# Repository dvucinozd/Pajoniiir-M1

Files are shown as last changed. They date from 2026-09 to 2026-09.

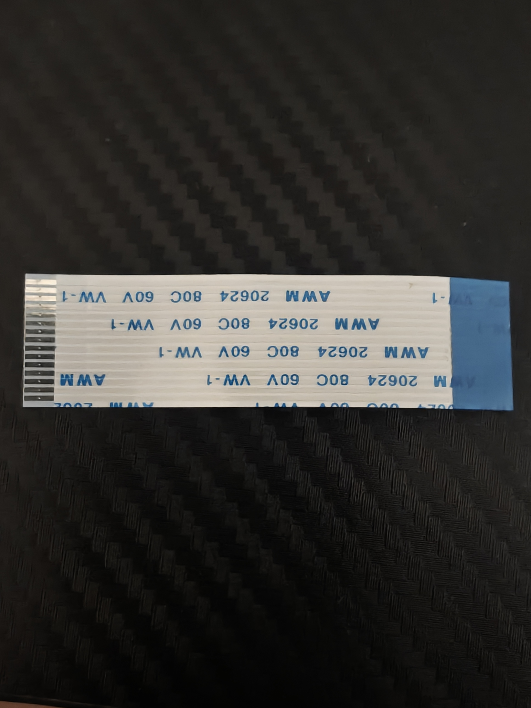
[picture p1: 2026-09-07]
hardware/Pajoniiir-M1/evidence/dsi506_ffc_flat.png

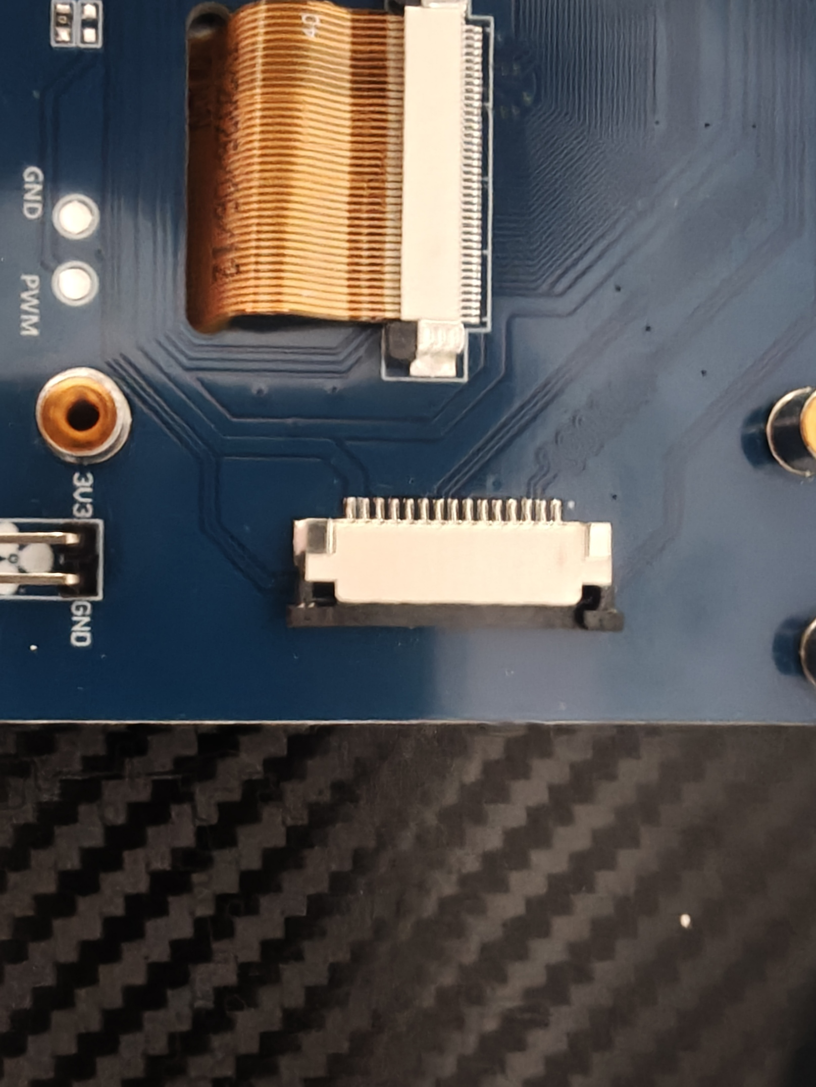
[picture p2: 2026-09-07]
hardware/Pajoniiir-M1/evidence/dsi506_actual_dsi_closeup.png

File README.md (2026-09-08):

# Pajoniiir-M1

Purpose-built Rev A mainboard for the **Pajoniiir standalone dual-deck DJ system**.

This repository contains the live hierarchical KiCad design, electrical and firmware contracts, mechanical evidence, placement/routing screening contracts, local CAD libraries and fail-closed validation tools.

## Current status

**Electrical milestone:** M1-ELEC-B2

**Mechanical milestone:** M1-MECH-B7

**Pre-layout milestone:** M1-PRELAYOUT-B10 - routed ESP32-P4 flash, crystal and external-DCDC feasibility proof

**Schematic structure:** PASS — 15/15 leaf sheets

**KiCad toolchain:** KiCad 10 only; local KiCad 10.0.4 ERC passes with zero violations and CI installs the KiCad 10 stable release

**Manufacturing BOM parity:** PASS — 244 source / 244 exported, 15 DNP, 3 intentional blank footprints

**Board-first mechanical contract:** PASS — display profiles cannot define the PCB outline or mounts

**Display-derived B2-B6 geometry:** historical screening only

**Final placement/routing freeze:** BLOCKED — 12 physical/EVT gates remain

**Gerber/EVT order:** NOT AUTHORIZED

Evidence updates: [ERC/library closure](docs/Pajoniiir_M1_ERC_Library_Closure_2026-09-04.md), [DSI506 rear image and corrected height](docs/Pajoniiir_M1_DSI506_Evidence_2026-09-04.md).

The current human-readable snapshot is [Pajoniiir M1 Current Design Status B10](docs/Pajoniiir_M1_Current_Design_Status_B10.md).

## Architecture

```text
                         5 V LOCKING INPUT
                                |
                         TPS259474 eFuse
                                |
                         5V_PROTECTED
                                |
                    5 mOhm Kelvin system shunt
                       / INA238 measurement
                                |
                             5V_SYS
              +-----------------+------------------+
              |                                    |
          TPS62132                         USB VBUS switches
          3V3_SYS                          TPS25221 x2
              |                               |       |
      +-------+---------+                  USB0 HS  USB1 FS
      |       |         |                  storage   FLX4
      v       v         v
  ESP32-P4 ESP32-C6  PCM5102A
      |      SDIO      MAIN L/R
      |
      +-- 15-pin MIPI DSI + I2C --> qualified display profile
      +-- SDMMC -----------------> microSD
```

The mainboard exposes a generic 15-pin Raspberry-Pi-style MIPI DSI host interface. EYOYO DSI506 / DYL0023 is the first validated display profile; other models may use the same board after electrical, power, firmware and cable qualification.

## Electrical baseline

- ESP32-P4NRW32X, target silicon v3.2 or newer approved revision
- 32 MB in-package PSRAM
- W25Q128JVPIQ 16 MB external QSPI flash
- ESP32-C6-WROOM-1-N4 over four-bit SDIO
- USB0 dedicated High-Speed storage host
- USB1 GPIO26/27 Full-Speed DDJ-FLX4 MIDI/UAC host
- independent TPS25221 VBUS switching, about 1.0 A USB0 and 1.6 A USB1 initial limits
- PCM5102APWR stereo MAIN output with deterministic XSMT boot mute
- native four-bit SDMMC microSD with TPS22918 power cycling
- P4 UART, P4 USB Serial/JTAG pogo and C6 recovery paths
- optional INA238 system power telemetry

## DSI host contract

```text
Host connector    Amphenol SFW15R-2STE1LF
Interface         15 contacts, 1.0 mm, Raspberry-Pi-style DSI map
Supply branch     3V3_DISPLAY_MODULE; final multi-model budget open
DSI routing       clock + lane0 + lane1
I2C               GPIO7 SDA / GPIO8 SCL
Cable             qualified per display model or adapter
Validated profile DSI506 / DYL0023: lane0, 800 Mbps, RGB888, 27.777 MHz
```

Connector shape alone does not prove compatibility. Every supported display needs a recorded pin map, power envelope, DSI timing/controller profile and cable orientation.

## Mechanical baseline

The mainboard is a standalone assembly and mounts to its own chassis or enclosure bosses. Its outline, mounting pattern and connector coordinates remain open until complete footprint packing, routing, thermal and service-envelope work establishes a viable board.

DSI506-derived values such as the 58 x 49 mm rear posts, 104 x 62 mm board screen and 128 x 84 x 30 mm enclosure screen are retained only for optional DSI506 bracket/enclosure work. They are not production `Edge.Cuts` authority.

## Connector and footprint state

| RefDes | Production part | Footprint | Mechanical state |
|---|---|---|---|
| J1 | Switchcraft 722RAHLP | open | terminal-center and panel geometry required |
| J2/J3 | Amphenol 87520-1010ALF | locked | panel/cable envelope open |
| J4/J5 | Kycon KLPX-0848A-2-W-G / -R-G | locked | panel/cable envelope open |
| J6 | Amphenol SFW15R-2STE1LF | locked | board-edge placement, power budget and per-display cable profile open |
| J7 | Molex 503398-1892 | locked | slot/access/clearance open |
| SW1/SW2 | B3U-3000P-B | locked | recessed tool-hole placement open |
| J9 | project-local factory pogo | closed, DNL | normal placement work only |

Only `J1`, `C3` and `C8` intentionally have blank footprints in the manufacturing source.

## PCB and routing state

`hardware/Pajoniiir-M1/Pajoniiir-M1.kicad_pcb` is a populated four-copper-layer pre-layout canvas. It contains all 244 assigned footprints and 193 named schematic nets in eight `Dwgs.User` working domains. B10 adds 78 track segments and 11 vias for the P4 external flash, crystal and external-DCDC proof. The P4 group has no footprint bounding-box overlaps; the board still has no zones or `Edge.Cuts`.

`m1_board_packing_inventory_b7.json` records all 247 schematic components, 244 assigned footprints, 33 footprint classes including the blank-gate class, and the seven board-first packing phases.

`m1_board_placement_seed_b8.json` records the generated domain coordinates and explicitly marks every coordinate as non-production. The seed and validator scripts preserve schematic UUID paths so KiCad can continue synchronizing the board with the hierarchy.

`m1_prelayout_b9_core_island.json` remains the reproducible unrouted source placement. `m1_prelayout_b10_core_routes.json` records the live critical routes and metrics. Its validator enforces the 5.203 mm U1/Y1 body gap, QSPI transition topology, 0.60/0.30 mm B10 vias, power-trunk widths, zero P4 bounding-box overlaps and zero route-geometry DRC violations.

The stackup is locked to JLCPCB `JLC04161H-7628`, 1.6 mm, 1 oz outer copper and 0.5 oz inner copper.

```text
F.Cu   components + critical USB/MIPI/QSPI/SDIO routing
In1.Cu continuous solid GND reference
In2.Cu power distribution + compatible low-speed routing
B.Cu   secondary components and low-speed routing
```

B5 locks routing topology and provides screening geometry:

- USB: 90 ohm differential; screening 0.2332 mm width / 0.15 mm gap
- MIPI: 100 ohm differential; screening 0.1722 mm width / 0.15 mm gap

These numbers are not production impedance locks. Exact JLCPCB calculator records, soldermask/model selection and matching KiCad rules are required before route freeze.

## Open layout blockers

The current 12 blocking gates are:

```text
C3_INPUT_BULK
C8_PROTECTED_BULK
J1_POWER_INPUT
SW1_RESET
SW2_BOOT
J2_USB0
J3_USB1
J4_RCA_L
J5_RCA_R
J_LCD_DISPLAY_FPC
J7_MICROSD
PCB_OUTLINE
```

Although most connector MPNs and footprints are locked, their gates stay open until absolute panel datums, cutouts, mating envelopes and local clearances are physically validated.

## Repository structure

```text
docs/                         engineering and status documents
hardware/Pajoniiir-M1/        KiCad project and machine contracts
  *.kicad_sch                 root plus 15 hierarchical sheets
  Pajoniiir-M1.kicad_pcb      populated four-layer B10 critical-route canvas
  *.json                      electrical/mechanical/freeze authorities
  libraries/                  project symbols and footprints
  tools/                      migration and fail-closed validators
.github/workflows/            KiCad and mechanical CI
```

## Authority order

When sources disagree:

1. live `hardware/Pajoniiir-M1/*.kicad_sch`
2. `board_first_mechanical_contract.json` and `mechanical_gates.json`
3. `pcb_constraints.json` and the current routing contract
4. B4 exact connector source lock
5. display compatibility profiles, beginning with `display_compatibility_dsi506.json`
6. [Engineering BOM v0.3](docs/Pajoniiir_Mainboard_BOM_v0.3.md)
7. [Global GPIO allocation](docs/Pajoniiir_Global_GPIO_Allocation_v0.1.md)
8. subsystem documents
9. superseded display-mounted B2-B6 and JC4880 records as historical evidence

## Current documents

### Status and release gates

- [Development handoff and remaining work](docs/Pajoniiir_M1_Development_Handoff_2026-09-08.md)
- [Current Design Status B10](docs/Pajoniiir_M1_Current_Design_Status_B10.md)
- [B10 P4 Critical Routes](docs/Pajoniiir_M1_PRELAYOUT_B10_P4_Critical_Routes_v0.1.md)
- [B9 P4 Core Island](docs/Pajoniiir_M1_PRELAYOUT_B9_P4_Core_Island_v0.1.md)
- [Schematic Audit](docs/Pajoniiir_M1_Schematic_Audit_v0.1.md)
- [Schematic Readiness Review](docs/Pajoniiir_RevA_Schematic_Readiness_Review_v0.1.md)
- [Manufacturing Output Contract](docs/Pajoniiir_Manufacturing_Output_Contract_v0.1.md)
- [Mechanical and Sourcing Gates](docs/Pajoniiir_M1_Mechanical_Sourcing_Gates_v0.1.md)
- [PCB Placement and Routing Constraints](docs/Pajoniiir_M1_PCB_Layout_Constraints_v0.1.md)

### Electrical contracts

- [Engineering BOM v0.3](docs/Pajoniiir_Mainboard_BOM_v0.3.md)
- [Global GPIO Allocation](docs/Pajoniiir_Global_GPIO_Allocation_v0.1.md)
- [Hardware/Firmware Contract](docs/Pajoniiir_M1_Hardware_Firmware_Contract_v0.1.md)
- [5-inch DSI Interface Migration](docs/Pajoniiir_M1_ELEC_B0_5in_DSI_Interface_Migration_v0.1.md)
- [15-pin DSI Connector Lock](docs/Pajoniiir_M1_ELEC_B1_DSI15_Connector_Lock_v0.1.md)
- [Board-first mechanical rebase](docs/Pajoniiir_M1_MECH_B7_Board_First_Rebase_v0.1.md)
- [DSI506 compatibility evidence](docs/Pajoniiir_M1_DSI506_Evidence_2026-09-04.md)

### Historical and subsystem design records

The original architecture, schematic plan, JC4880 display/backlight, GT911 and M1-MECH-A documents remain in `docs/` as design provenance. Their display-specific geometry does not override the B7 board-first authority.

## Validation

From the repository root:

```bash
python hardware/Pajoniiir-M1/tools/validate_schematic_structure.py
python hardware/Pajoniiir-M1/tools/validate_mechanical_authority.py
python hardware/Pajoniiir-M1/tools/report_mech_gate_snapshot.py
"C:/Program Files/KiCad/10.0/bin/python.exe" hardware/Pajoniiir-M1/tools/validate_core_routing_b10.py \
  --board hardware/Pajoniiir-M1/Pajoniiir-M1.kicad_pcb \
  --project hardware/Pajoniiir-M1/Pajoniiir-M1.kicad_pro \
  --report hardware/Pajoniiir-M1/m1_prelayout_b10_core_routes.json \
  --drc <fresh-kicad-drc.json>
```

Native KiCad 10 CI loads every schematic, exports and cross-checks the manufacturing BOM, exports the hierarchy netlist/PDF, enforces ERC cleanliness and validates the B10 PCB routing contract against a fresh DRC report.

Final placement, routing, Gerbers and EVT ordering remain blocked until every `blocks_layout_freeze` gate is closed and the production impedance geometry is recorded.

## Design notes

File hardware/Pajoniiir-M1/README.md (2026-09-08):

# Pajoniiir-M1 KiCad Rev A

Live KiCad 10 project for the Pajoniiir-M1 custom mainboard. KiCad 10 is the only supported ECAD toolchain for future edits and CI.

## Current design state

- Electrical milestone: M1-ELEC-B2
- Mechanical milestone: M1-MECH-B7
- Pre-layout milestone: M1-PRELAYOUT-B10 P4 critical-route proof
- Root schematic plus 15 leaf sheets: structurally clean
- Current manufacturing source: 244 `in_bom=yes`, 15 DNP, 3 intentional blank footprints
- PCB: 244 footprints, 193 named nets, 78 B10 track segments and 11 vias; no zones/`Edge.Cuts`
- Board packing inventory: 247 schematic components, 244 assigned footprints, 3 intentional blanks
- Final placement/routing freeze: blocked by 12 physical/EVT gates

J6 is a generic 15-pin Raspberry-Pi-style MIPI DSI host using Amphenol SFW15R-2STE1LF. DSI506 / DYL0023 is one validated display profile. `11_TOUCH_GT911.kicad_sch` stays empty because touch behavior belongs to the selected display profile.

## Authorities

1. `*.kicad_sch` — connectivity, RefDes, values and footprints
2. `board_first_mechanical_contract.json` — mainboard geometry boundary
3. `mechanical_gates.json` and `pcb_constraints.json` — freeze and layout gates
4. `m1_prelayout_b5_routing_contract.json` — routing topology and impedance state
5. `m1_board_packing_inventory_b7.json` — footprint population and packing sequence
6. `m1_board_placement_seed_b8.json` — populated-domain coordinates and non-production boundary
7. `m1_prelayout_b9_core_island.json` — reproducible unrouted P4 source placement
8. `m1_prelayout_b10_core_routes.json` — current critical-route placement and copper metrics
9. `m1_mech_b4_connector_source_lock.json` — exact external connector intent
10. `display_compatibility_dsi506.json` — first qualified display profile

The B2-B6 display-mounted placement and enclosure JSON files are retained as historical DSI506 screening only.

Human-readable current state: `../../docs/Pajoniiir_M1_Current_Design_Status_B10.md`.

Next-session development sequence: `../../docs/Pajoniiir_M1_Development_Handoff_2026-09-08.md`.

## Mechanical and routing boundary

The board mounts to its own chassis. Final `Edge.Cuts`, chassis holes, connector coordinates and height zones must come from board component packing, routing and service requirements. Display rear posts and display-derived board/enclosure screens are not production authority.

The selected stackup is JLCPCB JLC04161H-7628, four layers and 1.6 mm. Exact 90 ohm USB and 100 ohm MIPI width/gap values still require a recorded JLCPCB calculator result before routing freeze.

Do not add production `Edge.Cuts`, call screening anchors final placement, or release Gerbers while `layout_freeze_allowed` is false.

## Validation

Run from the repository root:

```bash
python hardware/Pajoniiir-M1/tools/validate_schematic_structure.py
python hardware/Pajoniiir-M1/tools/validate_mechanical_authority.py
python hardware/Pajoniiir-M1/tools/validate_board_packing_inventory.py
python hardware/Pajoniiir-M1/tools/report_mech_gate_snapshot.py
"C:/Program Files/KiCad/10.0/bin/python.exe" hardware/Pajoniiir-M1/tools/validate_core_routing_b10.py \
  --board hardware/Pajoniiir-M1/Pajoniiir-M1.kicad_pcb \
  --project hardware/Pajoniiir-M1/Pajoniiir-M1.kicad_pro \
  --report hardware/Pajoniiir-M1/m1_prelayout_b10_core_routes.json \
  --drc <fresh-kicad-drc.json>
```

Native KiCad ERC, hierarchy load, manufacturing BOM parity, netlist and PDF export are enforced in CI. B10 routing validation additionally uses KiCad's bundled `pcbnew` Python module and a fresh KiCad DRC JSON locally.

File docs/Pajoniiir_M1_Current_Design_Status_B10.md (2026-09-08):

# Pajoniiir-M1 current design status B10

**Date:** 2026-09-08

**Electrical milestone:** M1-ELEC-B2

**Mechanical milestone:** M1-MECH-B7

**Pre-layout milestone:** M1-PRELAYOUT-B10

**Layout state:** populated board-first canvas with routed P4 flash, crystal and external-DCDC feasibility proof; `layout_freeze_allowed=false`

**ECAD toolchain:** KiCad 10.x only for all future edits and CI

## Product boundary

Pajoniiir-M1 is the primary product assembly: a standalone ESP32-P4 mainboard. Its PCB outline, mounting holes, connector locations, height zones and enclosure datums must come from the board's own packing, routing, thermal, service and manufacturing requirements.

The screen is a replaceable external peripheral. DSI506 / DYL0023 remains one electrically and physically qualified compatibility profile; it does not define the mainboard outline or mounting pattern.

## Electrical and PCB state

The hierarchical KiCad design contains 15 leaf sheets. Current structural validation passes, all 244 assigned footprints are on the board, and the board retains 193 named schematic nets. The intentional blank-footprint set remains J1, C3 and C8.

The board retains:

- ESP32-P4 with ESP32-C6 over four-bit SDIO;
- independent USB host ports and switched VBUS branches;
- PCM5102A stereo MAIN output;
- native four-bit SDMMC microSD;
- power protection, current measurement and power-good diagnostics;
- generic 15-pin Raspberry-Pi-style MIPI DSI host interface.

B8 populated the eight reversible `Dwgs.User` electrical domains. B9 compacted the 63 P4 and flash-sheet footprints into a deterministic island. B10 rotates U1 and adds real copper for the external QSPI flash, 40 MHz crystal and external VDD_HP regulator.

The B10 live board contains 78 track segments and 11 vias. There are no footprint bounding-box overlaps in the P4 group, no zones and no `Edge.Cuts`. The crystal body is 5.203 mm from U1. The six QSPI paths have a 12.208 mm screening length spread and three package-opposed paths use one via pair each.

KiCad 10.0.4 reports zero route-specific geometry violations. U8 now uses a project-local KiCad 10 footprint with four 0.30 mm thermal-via drills, clearing the previous minimum-drill conflict. The unfinished whole board still has 499 unconnected items and nine non-routing findings: eight silkscreen findings and the intentionally absent outline.

`m1_prelayout_b10_core_routes.json` is the current machine-readable route authority. B9 remains the reproducible unrouted source placement.

## Display interface

J6 remains Amphenol `SFW15R-2STE1LF`, 15 contacts at 1.0 mm pitch, top contact, right-angle SMT ZIF. It routes DSI clock, lane 0, lane 1, shared display I2C and `3V3_DISPLAY_MODULE`.

Every supported display model still needs its own pin-map or adapter, power envelope, DSI timing/controller profile, touch behavior and cable orientation/service qualification. Type-B is a DSI506 cable fact, not a universal M1 requirement.

## Locked and open items

Locked today:

- electrical connectivity and current 15-sheet hierarchy;
- J6 part, footprint and 15-pin electrical map;
- JLCPCB `JLC04161H-7628` four-layer, 1.6 mm stackup;
- most external connector MPN and footprint intent;
- DSI506 compatibility profile;
- reproducible B9 source placement and B10 critical-route proof;
- U8 project-local VQFN thermal-via variant with 0.30 mm drills;
- 0.15 mm Default clearance for current fine-pitch escape validation;
- `layout_freeze_allowed=false` while blockers remain.

The 12 layout blockers remain:

```text
C3_INPUT_BULK
C8_PROTECTED_BULK
J1_POWER_INPUT
SW1_RESET
SW2_BOOT
J2_USB0
J3_USB1
J4_RCA_L
J5_RCA_R
J_LCD_DISPLAY_FPC
J7_MICROSD
PCB_OUTLINE
```

## Next board work

1. Place U4 at a candidate board edge, enforce its all-layer antenna keepout and prove the four-bit SDIO escape to U1.
2. Add the complete P4 power/GND plane and stitching strategy.
3. Compact the power spine and connector domains around the P4 and C6 islands, then derive the minimum board-owned envelope.
4. Add a chassis mounting pattern and validate cables, height zones, thermal clearance and user access.
5. Close J1/C3/C8 EVT and exact controlled-impedance geometry before final route freeze.

No Gerber or EVT order is authorized while the outline and blocking gates remain open.

## Validation

```powershell
python hardware/Pajoniiir-M1/tools/validate_schematic_structure.py
python hardware/Pajoniiir-M1/tools/validate_mechanical_authority.py
python hardware/Pajoniiir-M1/tools/validate_board_packing_inventory.py
python hardware/Pajoniiir-M1/tools/report_mech_gate_snapshot.py
kicad-cli pcb drc --format json --output <b10-drc.json> `
  hardware/Pajoniiir-M1/Pajoniiir-M1.kicad_pcb
& 'C:\Program Files\KiCad\10.0\bin\python.exe' `
  hardware/Pajoniiir-M1/tools/validate_core_routing_b10.py `
  --board hardware/Pajoniiir-M1/Pajoniiir-M1.kicad_pcb `
  --project hardware/Pajoniiir-M1/Pajoniiir-M1.kicad_pro `
  --report hardware/Pajoniiir-M1/m1_prelayout_b10_core_routes.json `
  --drc <b10-drc.json>
```

The B8 and B9 validators apply to their historical unrouted artifacts. The B10 validator is the live-board routing gate.

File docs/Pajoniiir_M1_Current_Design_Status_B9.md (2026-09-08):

# Pajoniiir-M1 current design status B9

> **HISTORICAL STATUS.** B10 added the routed P4 flash, crystal and external-DCDC feasibility proof. Use `Pajoniiir_M1_Current_Design_Status_B10.md` for the current state.

**Date:** 2026-09-07

**Electrical milestone:** M1-ELEC-B2

**Mechanical milestone:** M1-MECH-B7

**Pre-layout milestone:** M1-PRELAYOUT-B9

**Layout state:** populated board-first canvas with a compact P4 routing-feasibility island; `layout_freeze_allowed=false`

## Product boundary

Pajoniiir-M1 is the primary product assembly: a standalone ESP32-P4 mainboard. Its PCB outline, mounting holes, connector locations, height zones and enclosure datums must be derived from the board's own component packing, routing, thermal, service and manufacturing requirements.

The screen is a replaceable external peripheral. No display PCB, display mounting-post pattern or display enclosure may define the M1 board geometry.

The active machine authority is `hardware/Pajoniiir-M1/board_first_mechanical_contract.json`. `mech_a.json`, `mechanical_gates.json` and `pcb_constraints.json` are synchronized to that boundary.

## Electrical state

The hierarchical KiCad design contains 15 leaf sheets. Current structural validation passes with all 15 sheets and the intentional blank-footprint policy remains limited to J1, C3 and C8. Local KiCad 10 ERC previously passed with zero violations after power-good test points, no-connect markers and library closure were added.

The board retains these main functions:

- ESP32-P4 with ESP32-C6 over four-bit SDIO
- independent USB host ports and switched VBUS branches
- PCM5102A stereo MAIN output
- native four-bit SDMMC microSD
- power protection, current measurement and power-good diagnostics
- generic 15-pin Raspberry-Pi-style MIPI DSI host interface

## Display interface and compatibility

J6 is the board interface, using Amphenol `SFW15R-2STE1LF`, 15 contacts at 1.0 mm pitch, top contact, right-angle SMT ZIF. The locked electrical map routes DSI clock, lane 0, lane 1, shared display I2C and `3V3_DISPLAY_MODULE`.

EYOYO DSI506 / DYL0023 is one validated compatibility profile. Pajoniiir-M3 evidence confirms its electrical map and operating profile, and the supplied photos confirm its Type-B FFC construction. Those facts do not make DSI506 the final product display or the mechanical datum for M1.

Every additional display model must qualify:

- the same 15-pin electrical map, or an explicit adapter;
- startup, steady-state and transient current on `3V3_DISPLAY_MODULE`;
- DSI lanes, rate, pixel format and timing;
- touch/controller I2C behavior where used;
- cable contact orientation, insertion and service envelope.

Type-B is a DSI506 cable fact, not a universal M1 requirement. The board-side connector remains fixed; a cable or adapter profile resolves model-specific orientation.

## Mechanical rebase

The following values are retained only as DSI506-specific or historical screening evidence:

- 58 x 49 mm DSI506 rear-post pattern;
- 104 x 62 mm display-derived board screen;
- 128 x 84 x 30 mm display-derived enclosure screen;
- the 1.4455 mm DSI506 right-edge FFC clearance result;
- all JC4880 enclosure, mount and Z-stack geometry.

They are forbidden as production `Edge.Cuts`, mainboard mounting or connector-placement authority. The B2 through B6 display-specific records remain useful when designing a DSI506 bracket, cable kit or enclosure variant.

The board outline and its chassis mounting pattern remain open. `m1_board_packing_inventory_b7.json` closed the inventory step with 247 schematic components, 244 assigned footprints, 3 intentional blank footprints and 33 footprint classes including the blank-gate class.

M1-PRELAYOUT-B8 populated the live PCB with all 244 assigned footprints and 193 named schematic nets. Eight `Dwgs.User` rectangles separate the working electrical domains: power spine, USB edges, audio, P4 core, C6 RF, DSI host, storage and service.

M1-PRELAYOUT-B9 moves all 63 footprints from `03_P4_CORE` and `04_P4_FLASH_CLOCK_RESET` into a deterministic 52.602 x 50.033 mm routing-feasibility island. U1, U2, U3, L1 and Y1 now form the electrical anchors; the six QSPI tuning resistors sit between U1 and U2, the external DCDC loop sits beside U1, and the 40 MHz crystal body remains 7.285 mm from U1. The island has zero footprint bounding-box overlaps and the entire board still has no tracks, zones or `Edge.Cuts`.

`m1_prelayout_b9_core_island.json` records every B9 coordinate and metric. These coordinates and the eight domain rectangles remain a reversible working canvas. They are not connector, mounting or enclosure datums, and the next escape/routing pass may move parts within the P4 island.

## Locked and open items

Locked today:

- electrical connectivity and current 15-sheet hierarchy;
- J6 part, footprint and 15-pin electrical map;
- JLCPCB `JLC04161H-7628` four-layer, 1.6 mm stackup;
- most external connector MPN and footprint intent;
- DSI506 electrical/firmware compatibility profile;
- the reproducible B9 P4 core-island seed and its fail-closed validator;
- `layout_freeze_allowed=false` while blockers remain.

The 12 layout blockers remain:

```text
C3_INPUT_BULK
C8_PROTECTED_BULK
J1_POWER_INPUT
SW1_RESET
SW2_BOOT
J2_USB0
J3_USB1
J4_RCA_L
J5_RCA_R
J_LCD_DISPLAY_FPC
J7_MICROSD
PCB_OUTLINE
```

The meaning of the last two gates changed at B7. `J_LCD_DISPLAY_FPC` now asks for board-edge J6 placement, generic service access, branch power qualification and per-display cable profiles. `PCB_OUTLINE` now asks for a board-owned outline and chassis mount derived from completed packing and routing evidence.

## Next board work

1. Prove the U1 escape corridors and short QSPI, external-DCDC and crystal routes inside the B9 island while retaining a complete GND reference.
2. Place U4 at a candidate outer edge, preserve its all-layer antenna keepout and prove the four-bit SDIO escape to U1.
3. Compact the power spine and connector domains around those two critical islands, then derive a minimum feasible board envelope.
4. Add an independent chassis mounting-hole pattern and validate mated cables, height zones and thermal clearance.
5. Close J1/C3/C8 EVT and exact controlled-impedance geometry before final routing freeze.

No Gerber or EVT order is authorized while the outline and blocking gates remain open.

## Validation

```bash
python hardware/Pajoniiir-M1/tools/validate_schematic_structure.py
python hardware/Pajoniiir-M1/tools/validate_mechanical_authority.py
python hardware/Pajoniiir-M1/tools/validate_board_packing_inventory.py
python hardware/Pajoniiir-M1/tools/report_mech_gate_snapshot.py
"C:/Program Files/KiCad/10.0/bin/python.exe" hardware/Pajoniiir-M1/tools/validate_board_placement_b8.py \
  --board hardware/Pajoniiir-M1/Pajoniiir-M1.kicad_pcb \
  --netlist <fresh-kicad-xml-netlist> \
  --report hardware/Pajoniiir-M1/m1_board_placement_seed_b8.json
"C:/Program Files/KiCad/10.0/bin/python.exe" hardware/Pajoniiir-M1/tools/validate_core_placement_b9.py \
  --board hardware/Pajoniiir-M1/Pajoniiir-M1.kicad_pcb \
  --report hardware/Pajoniiir-M1/m1_prelayout_b9_core_island.json
```

The former B4 panel-window and B5 display-mounted placement validators are no longer CI gates because their coordinate systems were tied to DSI506. Their JSON outputs are explicitly marked historical screening only.

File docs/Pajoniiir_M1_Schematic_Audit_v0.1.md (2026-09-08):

# Pajoniiir-M1 — Schematic Audit v0.2

**Updated:** 2026-09-04

**Electrical milestone:** M1-ELEC-B2

**Mechanical context:** M1-MECH-B7

**Status:** local KiCad 10.0.4 ERC and export validation pass; KiCad 10 is the sole current CI/ECAD toolchain; final PCB placement/routing remains blocked

## Scope

This audit covers the root KiCad schematic and all 15 leaf sheets under `hardware/Pajoniiir-M1/`.

```text
01_POWER_INPUT
02_POWER_3V3
03_P4_CORE
04_P4_FLASH_CLOCK_RESET
05_C6_WIFI
06_USB_POWER
07_USB0_STORAGE
08_USB1_FLX4
09_AUDIO_PCM5102A
10_DISPLAY_MIPI
11_TOUCH_GT911
12_MICROSD
13_DEBUG_SERVICE
14_TEST_MONITORING
15_DNP_OPTIONS
```

`11_TOUCH_GT911` and `15_DNP_OPTIONS` intentionally contain no instantiated symbols after migration to the generic DSI host. Their presence preserves the hierarchy and historical sheet roles.

## Current verdict

| Check | Result |
|---|---|
| 15-sheet structural contract | PASS |
| Unique RefDes/unit contract | PASS |
| Root/child hierarchical pin name and shape equivalence | PASS |
| Critical 5 V/shunt topology | PASS |
| Generic 15-pin DSI host contract | PASS |
| Complete hierarchy load under KiCad 10.0.4 | PASS (16-sheet ERC/PDF export) |
| Local native KiCad 10.0.4 ERC | 0 unexplained errors, 0 excluded errors, 0 warnings |
| Manufacturing BOM parity | 244 source / 244 export, 15 DNP, 3 blank gates, PASS |
| Final PCB placement/routing freeze | BLOCKED |

The `.kicad_pro` file still contains six UUID-scoped exclusion records from the retired JC4880 connector gate. The current native KiCad 10 ERC report contains no violations, so those records are inactive configuration history rather than current violations.

See [PG diagnostics and library closure](Pajoniiir_M1_ERC_Library_Closure_2026-09-04.md) for TP25/TP26 connectivity, connector shield preservation, U14 land pattern and the remaining export-warning observation.

## Captured electrical architecture

### Power

```text
J1 -> D1 -> U7 TPS259474A -> 5V_PROTECTED
   -> R120 5 mOhm Kelvin shunt -> 5V_SYS
```

`5V_SYS` supplies the TPS62132 3.3 V system regulator and independent TPS25221 USB VBUS paths. INA238 measures across the system shunt. J1, C3 and C8 remain intentional blank-footprint production gates.

### ESP32-P4

U1 is ESP32-P4NRW32X with a reviewed project-local KiCad 10 symbol/footprint derived from current Espressif data. Both symbol units are instantiated. The P4 v3.x power model, physical pin 54 `VDD_HP_1`, TLV62569 core regulator, 499 k/499 k/22 pF feedback network, DSI_REXT, MIPI LDO and USB PHY supplies are captured.

### Flash, clock and recovery

W25Q128JVPIQ external flash, 40 MHz ECS crystal, boot/reset straps, P4 UART0, P4 USB Serial/JTAG pogo and C6 recovery paths are captured. SW1/SW2 use B3U-3000P-B footprints but remain open for enclosure tool-hole placement.

### ESP32-C6

ESP32-C6-WROOM-1-N4 is connected over four-bit SDIO with external pull-ups and series tuning. GPIO54 controls C6 reset/EN. RF antenna placement and final enclosure performance remain PCB/EVT work.

### USB

USB0 uses the dedicated P4 High-Speed PHY, TPD2EUSB30A and Amphenol 87520-1010ALF. USB1 uses GPIO26/27 Full-Speed, 22 ohm source series, TPD2EUSB30A and the same connector. Each port has an independent TPS25221 VBUS switch and EN/FAULT path.

J2/J3 MPNs and footprints are locked. Their gates remain open only for final panel/cutout/mated-cable geometry.

### MAIN audio

PCM5102APWR uses GPIO50 BCLK, GPIO51 DATA, GPIO52 LRCK and GPIO49 XSMT. The outputs use 470 ohm plus 2.2 nF filters into Kycon white/red RCA connectors. The former 3.5 mm line output was removed from Rev A.

### DSI host interface

The active design is a generic 15-pin Raspberry-Pi-style DSI host. J6 is Amphenol SFW15R-2STE1LF with a locked project footprint; DSI506/DYL0023 is one validated profile.

Captured interface:

```text
clock + DSI lane0 + DSI lane1
GPIO7 DISPLAY_I2C_SDA
GPIO8 DISPLAY_I2C_SCL
3V3_DISPLAY_MODULE on pins 14/15
```

The initial accepted firmware profile uses one lane at 800 Mbps, RGB888 and 27.777 MHz DPI. Touch is FT5426/FT5x06-compatible at 0x38 and panel power/backlight is controlled by the module device at 0x45.

There is no active MP3202 backlight boost, GT911 reset/interrupt network, LCD reset/TE or GPIO23 external PWM path. GPIO3/4/5/6/23 are released and unassigned.

The remaining J6 gate covers board-edge placement, power budget, generic service clearance and cable/adapter qualification per display model.

### microSD

The four-bit SDMMC bus, GPIO45-controlled TPS22918 supply and optional GPIO46 card detect are captured. J7 is Molex 503398-1892 with a locked footprint. Panel slot/access and local FFC/screw clearance remain open.

## Source and manufacturing inventory

Current source-derived counts:

```text
in_bom=yes      244
DNP              15
blank footprints  3: C3, C8, J1
DNL service       J8, J9, J10
```

Exact B4 footprints are present for J2/J3 USB, J4/J5 RCA, J7 microSD and SW1/SW2. J6 uses the B2 display connector footprint.

Historical 269/16/10 and run #76 270/17/12 figures predate the final display migration and B4 footprint locks. They are not current acceptance numbers.

## Structural validator coverage

`validate_schematic_structure.py` checks:

- balanced KiCad S-expressions and expected hierarchy
- bidirectional child-label/root-pin name and shape equivalence
- duplicate RefDes and duplicate RefDes/unit instances
- U1 two-unit geometry and pin partitioning
- prohibited ESP32-S3/ES8311/MAX485/NS4150 legacy blocks
- exact project eFuse and generic DSI host connector contracts
- `5V_PROTECTED -> R120 -> 5V_SYS` topology
- blank-footprint allowlist derived from `mechanical_gates.json`
- B7 board-first authority and fail-closed mechanical/PCB state
- PCB copper-layer count and absence of `Edge.Cuts` while the outline gate is open

Native KiCad ERC and downstream manufacturing export remain separate CI checks.

## Remaining release boundary

Electrical capture is complete. The 12 remaining blockers are physical/EVT/layout gates:

```text
C3_INPUT_BULK
C8_PROTECTED_BULK
J1_POWER_INPUT
SW1_RESET
SW2_BOOT
J2_USB0
J3_USB1
J4_RCA_L
J5_RCA_R
J_LCD_DISPLAY_FPC
J7_MICROSD
PCB_OUTLINE
```

Production placement/routing additionally requires exact 90 ohm USB and 100 ohm MIPI width/gap values for JLCPCB JLC04161H-7628.

## Go / no-go

- Schematic capture: **PASS / complete**
- Structural and manufacturing-source validation: **PASS**
- Exploratory placement using B5 screening anchors: **allowed**
- Final component placement: **blocked**
- Final USB/MIPI routing: **blocked**
- Gerbers and EVT PCB order: **blocked**

The next work should close J1 geometry, DSI FFC continuity/bend, display obstruction mapping, final enclosure/panel datums, mounting hardware, `Edge.Cuts`, C3/C8 EVT selection and production impedance rules.

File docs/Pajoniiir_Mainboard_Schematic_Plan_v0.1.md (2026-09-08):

# Pajoniiir Mainboard — Schematic Plan v0.1

**Projekt:** Pajoniiir BL-A1800 / Pajoniiir-M1  
**Ploča:** Pajoniiir Mainboard Rev A  
**Repo:** `dvucinozd/Pajoniiir-M1`  
**Datum:** 2026-09-02  
**Status:** Historical schematic architecture/capture plan. Implementation status is superseded by `Pajoniiir_M1_Schematic_Audit_v0.1.md` and the live KiCad project; pre-capture checkboxes below are not current milestone status.

---

# 1. Svrha dokumenta

Ovaj dokument bilježi kako su tadašnja hardverska arhitektura i Engineering BOM v0.2 prevedeni u plan za crtanje sheme. Aktivni projekt i Engineering BOM v0.3 sada su mjerodavni za stvarno stanje.

Cilj je da KiCad projekt od početka bude:

- hijerarhijski organiziran
- čitljiv
- lako reviewabilan
- pripremljen za ERC
- pripremljen za Rev A bring-up
- pripremljen za DNP varijante
- kompatibilan s postojećim Pajoniiir firmwareom
- pogodan za buduće PCB revizije bez velikog refaktora sheme

Podržani CAD alat: **KiCad 10 stable**.

Predloženi root projekt:

```text
hardware/
└── Pajoniiir-M1/
    ├── Pajoniiir-M1.kicad_pro
    ├── Pajoniiir-M1.kicad_sch
    ├── Pajoniiir-M1.kicad_pcb
    ├── sym-lib-table
    ├── fp-lib-table
    ├── symbols/
    ├── footprints/
    ├── 3d/
    └── docs/
```

---

# 2. Predložena hijerarhija sheme

Root sheet treba biti gotovo isključivo blok dijagram s hijerarhijskim sheetovima.

Predloženi sheetovi:

```text
00_ROOT
01_POWER_INPUT
02_POWER_3V3
03_P4_CORE
04_P4_FLASH_CLOCK_RESET
05_C6_WIFI
06_USB_POWER
07_USB0_STORAGE
08_USB1_FLX4
09_AUDIO_PCM5102A
10_DISPLAY_MIPI
11_TOUCH_GT911
12_MICROSD
13_DEBUG_SERVICE
14_TEST_MONITORING
15_DNP_OPTIONS
```

Preporuka: koristiti prefiks broja kako bi redoslijed sheetova ostao stabilan u KiCadu, PDF exportu i reviewu.

---

# 3. 00_ROOT — system interconnect

Root sheet mora prikazivati samo glavne funkcionalne blokove i globalne power railove.

## 3.1 Blokovi

```text
                        +-------------------+
                        |  01_POWER_INPUT   |
                        | VIN -> eFuse      |
                        +---------+---------+
                                  |
                                5V_SYS
                                  |
             +--------------------+--------------------+
             |                    |                    |
             v                    v                    v
      +-------------+      +-------------+      +-------------+
      | 02_POWER    |      | 06/07 USB   |      | 09 DISPLAY  |
      | 3V3 rails   |      | VBUS power  |      | backlight   |
      +------+------+      +------+------+      +------+------+
             |                    |                    |
           3V3_SYS               5V                LCD_BL
             |
      +------+-----------------------------------------------+
      |                                                      |
      v                                                      v
+-----------+                                        +---------------+
| 03 P4     |<---- QSPI ---- 04 FLASH/CLOCK         | 05 ESP32-C6   |
| CORE      |<---- SDIO ---------------------------->| ESP-HOSTED    |
+-----+-----+                                        +---------------+
      |
      +---- USB0 PHY ------> 06 USB0 STORAGE
      +---- USB1 PHY ------> 07 USB1 FLX4
      +---- I2S -----------> 08 PCM5102A
      +---- MIPI DSI ------> 09 DISPLAY
      +---- I2C -----------> 10 TOUCH
      +---- SDMMC ---------> 11 MICROSD
      +---- UART/GPIO -----> 12 DEBUG
      +---- MONITOR -------> 13 TEST/MONITORING
```

## 3.2 Root-level power nets

Koristiti konzistentne nazive:

- `VIN_5V`
- `5V_PROTECTED`
- `5V_SYS`
- `3V3_SYS`
- `3V3_C6`
- `3V3_AUDIO`
- `P4_VDD_HP`
- `LCD_BL_VOUT`
- `USB0_VBUS`
- `USB1_VBUS`
- `GND`

Ako se kasnije pokaže potreba, dodati:

- `3V3_SD`
- `3V3_LCD`
- `3V3_TOUCH`

ali u Rev A ne treba nepotrebno fragmentirati railove bez električkog razloga.

---

# 4. Naming convention

## 4.1 Digitalni signalni netovi

Koristiti funkcionalne nazive, ne samo GPIO broj.

Primjeri:

```text
P4_USB0_DP
P4_USB0_DM
P4_USB1_DP
P4_USB1_DM

P4_I2S_BCLK
P4_I2S_LRCK
P4_I2S_DOUT

P4_SDMMC_D0
P4_SDMMC_D1
P4_SDMMC_D2
P4_SDMMC_D3
P4_SDMMC_CLK
P4_SDMMC_CMD

P4_C6_SDIO_CLK
P4_C6_SDIO_CMD
P4_C6_SDIO_D0
P4_C6_SDIO_D1
P4_C6_SDIO_D2
P4_C6_SDIO_D3

P4_TOUCH_SDA
P4_TOUCH_SCL
P4_TOUCH_INT
P4_TOUCH_RST

P4_LCD_RST
P4_LCD_BL_PWM
```

GPIO broj staviti u pin label/comment, primjer:

```text
P4_I2S_BCLK   # GPIO50
```

To omogućuje kasniji firmware remap bez preimenovanja cijele sheme.

---

# 5. 01_POWER_INPUT

Ovaj sheet je električki najkritičniji uz USB.

## 5.1 Ulaz

Predloženi ulaz:

```text
J_PWR_IN
5 V regulated
4 A recommended source
```

Konektor: `TBD-MECH`.

Preporučuje se locking tip, ne obični labavi micro-USB/USB-C za osnovno napajanje Rev A.

## 5.2 Power chain

```text
J_PWR_IN
   |
   +-- C_IN_HF
   +-- C_IN_BULK
   |
   +-- TVS
   |
   +-- TPS25947 eFuse
   |
   +--> 5V_PROTECTED / 5V_SYS
```

## 5.3 TPS25947 signali

Izvesti:

- `EFUSE_EN`
- `EFUSE_PG`

Ako nema dovoljno GPIO-a u Rev A, `EFUSE_EN` može biti hardware-on. Za TPS259474A koristiti `EFUSE_PG`/`PGTH`; ova varijanta nema zaseban `FLT` izlaz. `EFUSE_PG` treba dovesti barem na P4 ili test point.

## 5.4 Test points

- TP VIN_5V
- TP 5V_SYS
- TP GND

## 5.5 ERC pravila

- power input označiti `PWR_FLAG`
- output eFusea označiti kao power output
- ne dopustiti drugi izvor na 5V_SYS
- USB VBUS se nikada ne smije direktno vezati natrag na VIN bez switcha

---

# 6. 02_POWER_3V3

U8 = TPS62132RGTR.

## 6.1 Funkcija

```text
5V_SYS
  |
TPS62132
  |
3V3_SYS
```

## 6.2 Consumers

`3V3_SYS` napaja:

- ESP32-P4 I/O/system railove prema referentnoj shemi
- external QSPI flash
- ESP32-C6-WROOM-1
- PCM5102A 3.3 V operation
- GT911 / touch subsystem ako kompatibilno
- microSD
- LCD logic gdje panel to zahtijeva

## 6.3 Layout-sensitive elementi

Na shemi ih grupirati fizičkim redoslijedom:

```text
VIN caps -> U8 -> SW -> L -> output caps -> feedback
```

Ne crtati feedback mrežu daleko od regulatora na shemi jer to otežava review layouta.

## 6.4 Test points

- `TP_3V3_SYS`
- opcionalno `TP_BUCK_SW` samo za laboratorij, jasno označen kao noisy node

---

# 7. 03_P4_CORE

Ovo je glavni sheet za ESP32-P4.

## 7.1 U1

`ESP32-P4NRW32X`

Prije capturea finalne sheme potvrditi:

- v3.x pinout
- VDD_HP_1 razliku u odnosu na staru v1.3 ploču
- sve power pinove
- exposed pad / GND requirements
- PSRAM in-package konfiguraciju

## 7.2 Funkcionalne grupe pinova

Na custom KiCad simbolu pinove grupirati po funkciji:

1. power
2. reset/strapping
3. USB HS
4. USB FS
5. MIPI DSI
6. flash interface
7. SDMMC
8. C6 SDIO
9. I2S audio
10. I2C touch
11. UART/debug
12. misc GPIO

## 7.3 GPIO assignment baseline

### Audio

- GPIO50 = I2S BCLK
- GPIO52 = I2S LRCK/WS
- GPIO51 = I2S DATA

### Touch

- GPIO3 = RST
- GPIO4 = INT
- GPIO7 = SDA
- GPIO8 = SCL

### microSD

- GPIO39 = D0
- GPIO40 = D1
- GPIO41 = D2
- GPIO42 = D3
- GPIO43 = CLK
- GPIO44 = CMD

### LCD

- GPIO5 = LCD RESET
- GPIO6 = optional TE
- GPIO23 = BACKLIGHT PWM

### C6 SDIO

- GPIO18 = CLK
- GPIO19 = CMD
- GPIO14 = D0
- GPIO15 = D1
- GPIO16 = D2
- GPIO17 = D3
- GPIO54 = C6 RESET

### USB power control

- GPIO20 = USB0 EN
- GPIO21 = USB0 FAULT_N
- GPIO22 = USB1 EN
- GPIO32 = USB1 FAULT_N

### microSD control

- GPIO45 = SD_PWR_EN
- GPIO46 = optional CARD_DETECT

### Audio mute

- GPIO49 = PCM5102A XSMT

### Monitoring

- GPIO53 = optional INA238 ALERT

## 7.4 Reserved GPIO table

U schematic notes dodati tablicu:

| GPIO | Rev A funkcija | Status |
|---|---|---|
| 5 | LCD_RST | locked |
| 7 | TOUCH_SDA | locked |
| 8 | TOUCH_SCL | locked |
| 14 | C6_SDIO_D0 | locked |
| 15 | C6_SDIO_D1 | locked |
| 16 | C6_SDIO_D2 | locked |
| 17 | C6_SDIO_D3 | locked |
| 18 | C6_SDIO_CLK | locked |
| 19 | C6_SDIO_CMD | locked |
| 23 | LCD_BL_PWM | locked |
| 39 | SD_D0 | locked |
| 40 | SD_D1 | locked |
| 41 | SD_D2 | locked |
| 42 | SD_D3 | locked |
| 43 | SD_CLK | locked |
| 44 | SD_CMD | locked |
| 50 | I2S_BCLK | locked |
| 51 | I2S_DATA | locked |
| 52 | I2S_LRCK | locked |
| 54 | C6_RESET | tentative-v3.x check |

Posebno provjeriti GPIO54/v3.x mapiranje prije schematic locka.

---

# 8. P4 VDD_HP core regulator

Može biti na `03_P4_CORE` ili kao pod-sheet.

Preporuka: ostaviti ga unutar P4 sheeta jer je električki dio SoC-a.

## 8.1 U3

TLV62569DRLR

## 8.2 Netovi

- input = `3V3_SYS`
- output = `P4_VDD_HP`
- feedback = lokalni netovi
- GND = solid GND

## 8.3 V3.x rule

Schematic comment:

> DO NOT COPY JC4880 P4 REV1.3 CORE DCDC VALUES. USE CURRENT ESPRESSIF V3.X REFERENCE NETWORK.

## 8.4 Test point

`TP_P4_VDD_HP`

---

# 9. 04_P4_FLASH_CLOCK_RESET

Namjerno odvojeno od glavnog P4 simbola zbog preglednosti.

## 9.1 QSPI flash

U2 = W25Q128JVPIQ candidate.

Netovi:

- `FLASH_CS`
- `FLASH_CLK`
- `FLASH_D0`
- `FLASH_D1`
- `FLASH_D2`
- `FLASH_D3`

Serijski 0 Ω footprints uz P4 ili flash, prema layout izboru.

## 9.2 40 MHz crystal

- Y1 = 40 MHz ±10 ppm
- Cload TBD nakon odabira MPN-a
- kratki netovi `XTAL_P`, `XTAL_N`

## 9.3 Reset

- 10 kΩ pull-up
- 1 µF prema GND
- RESET switch
- test point

## 9.4 BOOT

- strap prema aktualnom P4 reference designu
- BOOT switch
- test point

---

# 10. 05_C6_WIFI

U4 = ESP32-C6-WROOM-1-N4 candidate.

## 10.1 Interfaces

### P4 ↔ C6 SDIO

- CLK
- CMD
- D0-D3

### Control

- C6_RESET
- optional HOST_WAKE
- optional SLAVE_WAKE ako ESP-Hosted topologija bude zahtijevala

### Debug

- C6 UART TX
- C6 UART RX
- C6 EN

## 10.2 Antenna

Na shemi staviti velik note:

> MODULE ANTENNA KEEP-OUT REQUIRED ON PCB. NO COPPER, TRACES OR METAL UNDER ANTENNA REGION.

## 10.3 Power

Poželjno odvojiti net label:

`3V3_C6`

U početku može biti spojen preko 0 Ω / ferrite bead na `3V3_SYS`.

To daje mogućnost kasnije dodati EMI filtriranje bez PCB respina.

Predloženo:

```text
3V3_SYS -- FB_C6 / 0R --> 3V3_C6
```

---

# 11. 06_USB0_STORAGE

USB0 = High-Speed root za Rekordbox storage.

## 11.1 Data path

```text
ESP32-P4 HS USB PHY
      |
   D+ / D-
      |
 optional 0R tuning
      |
 low-C ESD
      |
 USB-A receptacle
```

## 11.2 Power path

```text
5V_SYS
  |
TPS25221 x2 CH1
  |
USB0_VBUS
  |
USB-A VBUS
```

## 11.3 Signals to P4

- `USB0_PWR_EN`
- `USB0_FAULT_N`

## 11.4 Connector shield

Ne vezati mehanički shield naslijepo direktno u signal GND bez razmišljanja.

Za Rev A predvidjeti opciju:

- direct GND via 0 Ω
- RC/chassis coupling footprint

ovisno o EMC strategiji.

## 11.5 Test

- VBUS TP
- D+ TP
- D- TP
- fault TP

---

# 12. 07_USB1_FLX4

USB1 = DDJ-FLX4.

Funkcije:

- MIDI IN
- MIDI OUT
- LED feedback
- USB Audio Class
- CUE/PFL channels 3/4

## 12.1 Data path

```text
ESP32-P4 FS USB
 |
22R / 22R initial
 |
ESD
 |
USB-A receptacle
 |
USB-A -> USB-C cable
 |
DDJ-FLX4
```

## 12.2 Power

TPS25221 x2 channel 2.

Netovi:

- `USB1_PWR_EN`
- `USB1_FAULT_N`
- `USB1_VBUS`

## 12.3 Critical validation

USB1 power path mora podnijeti:

- FLX4 enumeration
- LED activity
- MIDI
- 4ch UAC
- reconnect
- startup transient

bez brownouta P4.

---

# 13. TPS25221 x2 shared implementation

Iako se USB sheetovi prikazuju odvojeno, U6 može fizički biti na jednom sheetu.

Preporuka:

- U6 staviti na `06_USB0_STORAGE`
- CH1 = USB0
- CH2 = USB1
- na `07_USB1_FLX4` dovesti hijerarhijske netove

Alternativa: napraviti zaseban `06_USB_POWER` sheet.

Ako KiCad projekt krene rasti, bolja finalna hijerarhija je:

```text
06_USB_POWER
07_USB0_STORAGE
08_USB1_FLX4
```

i ostale sheetove pomaknuti za +1.

Za Rev A preporučujem upravo ovu varijantu jer jasno odvaja power od signal integrity dijela.

---

# 14. 08_AUDIO_PCM5102A

U5 = PCM5102APWR.

## 14.1 I²S input

- `P4_I2S_BCLK`
- `P4_I2S_LRCK`
- `P4_I2S_DOUT`

MCLK = NC / not used.

## 14.2 DAC control

Izvesti:

- `DAC_XSMT`

FMT i FLT mogu biti strapirani, ali ostaviti 0 Ω / resistor selection mogućnost.

## 14.3 Power

Preporučeni pristup:

```text
3V3_SYS
 |
ferrite bead / 0R
 |
3V3_AUDIO
 |
PCM5102A
```

Time se analogni DAC ne napaja direktno s najbučnijeg digitalnog raila bez mogućnosti filtriranja.

## 14.4 Analog outputs

```text
PCM5102A OUTL
  |
470R
  +---- RCA_L
  |
2.2nF
  |
GND

PCM5102A OUTR
  |
470R
  +---- RCA_R
  |
2.2nF
  |
GND
```

Točan položaj RC mreže u odnosu na konektor treba uskladiti s TI Figure 33 referentnom topologijom.

## 14.5 3.5 mm out — removed from Rev A

M1-MECH-A8 removes J6 from the Rev A board. No DNP footprint or panel aperture is reserved. MAIN remains RCA L/R; a future 3.5 mm option requires a new board/product revision.

---

# 15. 09_DISPLAY_MIPI

## 15.1 MIPI differential pairs

Netovi:

- `DSI_CLK_P`
- `DSI_CLK_N`
- `DSI_D0_P`
- `DSI_D0_N`
- `DSI_D1_P`
- `DSI_D1_N`

## 15.2 Control

- LCD_RST
- LCD_BL_PWM

## 15.3 Required analog/PHY support

- MIPI PHY decoupling
- DSI_REXT = 4.02 kΩ
- 0 Ω tuning footprints na svim DSI pair signalima samo ako ih layout i reference design opravdavaju

## 15.4 FPC

J_LCD ostaje TBD dok se ne zaključa točan panel.

Na shemi obavezno dokumentirati:

- FPC pitch
- contact side
- pin 1 orientation
- LED+ / LED-
- logic voltage
- touch signals ako dijele FPC

Bez ovoga PCB ne smije u layout freeze.

---

# 16. LCD backlight

U_BL = MP3202DJ-LF-Z candidate.

## 16.1 Input

5V_SYS.

## 16.2 Control

`LCD_BL_PWM` s GPIO23.

Ako MP3202 EN/PWM zahtijeva specifičnu logiku ili level, uključiti buffer samo ako datasheet/measurement pokaže potrebu.

## 16.3 Output

`LCD_BL_VOUT` prema LED stringu.

## 16.4 Lock condition

Ne zaključavati:

- inductor
- diode
- sense resistor
- OVP network

dok nije poznat finalni LCD LED string.

---

# 17. 10_TOUCH_GT911

## 17.1 Interface

- SDA = GPIO7
- SCL = GPIO8
- INT = odabrati slobodan P4 GPIO
- RESET = odabrati slobodan P4 GPIO

INT/RST pinovi trebaju biti firmware-configurable.

## 17.2 Pull-ups

Početno 4.7 kΩ, ali finalna vrijednost ovisi o:

- FPC dužini
- I2C frekvenciji
- bus capacitance

## 17.3 Address selection

GT911 reset/INT sequencing može utjecati na adresu.

Na shemi i firmwareu treba eksplicitno dokumentirati željenu 0x5D konfiguraciju.

---

# 18. 11_MICROSD

## 18.1 SDMMC 4-bit

- D0 GPIO39
- D1 GPIO40
- D2 GPIO41
- D3 GPIO42
- CLK GPIO43
- CMD GPIO44

## 18.2 Pull-ups

Predvidjeti pull-up na:

- CMD
- D0
- D1
- D2
- D3

Početna vrijednost 10 kΩ, finalno prema Espressif SDMMC preporuci.

## 18.3 CLK tuning

R_SD_CLK = 22 Ω initial.

Ostaviti 0402/0603 footprint blizu P4.

## 18.4 Optional power cycle

`SD_PWR_EN` kroz load switch ili P-MOSFET može biti DNP u Rev A, ali footprint je koristan.

---

# 19. 12_DEBUG_SERVICE

Rev A treba biti servisabilan bez lemljenja žica na fine pitch pinove.

## 19.1 P4 UART

- TX
- RX
- GND
- 3V3
- CHIP_PU
- BOOT

## 19.2 C6 debug

- TX
- RX
- EN
- RESET
- GND

## 19.3 USB Serial/JTAG

Ako P4 dedicated USB Serial/JTAG pinovi nisu zauzeti active topologyjem, predvidjeti test pads ili optional connector.

Ne uvoditi novi vanjski USB connector samo radi JTAG-a ako otežava finalnu mehaniku.

## 19.4 Connector

Preferred:

- Tag-Connect footprint
- pogo pads

Ne preferirati stalni 2.54 mm header na finalnom proizvodu.

---

# 20. 13_TEST_MONITORING

Ovaj sheet sadrži samo EVT/DVT opcije.

## 20.1 Current monitor

INA226/INA238 class.

Mjeri:

- 5V_SYS
- total system current

DNP default.

## 20.2 Optional divider rails

Može se omogućiti P4 ADC mjerenje:

- 5V_SYS divider
- USB0_VBUS divider
- USB1_VBUS divider

Ako ima dovoljno ADC resursa.

To daje firmware telemetry bez skupljeg current monitor IC-a.

## 20.3 Testpoint matrix

Na sheetu definirati sve TP oznake i funkcije.

---

# 21. 14_DNP_OPTIONS

Ovaj sheet sadrži stvari koje ne želimo u Rev A populaciji, ali mogu biti korisne za eksperiment.

Primjeri:

- 3.5 mm line out removed from Rev A (M1-MECH-A8)
- optional SD load switch
- optional current monitor
- optional reset supervisor
- optional EMI ferrite beads
- optional shield RC network
- optional status RGB LED

Ne stavljati ovdje obsolete funkcije poput S3, ES8311, camera ili RS485.

Njih uopće ne treba nositi u novu shemu.

---

# 22. Net classes za budući PCB

Iako je ovo schematic plan, net classes treba planirati prije layouta.

Predložene klase:

## USB_HS

- 90 Ω differential
- D+/D-
- tight pair
- low via count

## USB_FS

- differential pair
- manje strogo od HS, ali i dalje kontrolirano

## MIPI_DSI

- differential pair
- impedance prema Espressif/board stackup recommendation
- strict length matching unutar para
- međupair matching prema DPHY budgetu

## QSPI_FLASH

- kratko
- low stub
- matching po potrebi

## SDIO_C6

- kratko
- CLK kontroliran
- data/cmd matching prema SDIO timing budgetu

## SDMMC

- CLK kritičan
- D0-D3/CMD grupirani

## I2S

- BCLK/LRCK/DATA
- držati dalje od analog outputa

## ANALOG_AUDIO

- OUTL/OUTR
- no switching cross
- minimal loop area

## POWER_5V_HIGH

- 5V_SYS
- USB0_VBUS
- USB1_VBUS
- dimenzionirati za current + transient margin

---

# 23. ERC rules

## 23.1 Power flags

Dodati samo gdje je stvarno potrebno.

Ne “gasiti” ERC upozorenja naslijepo.

## 23.2 No-connect pins

Svaki NC pin eksplicitno označiti NC.

## 23.3 DNP

DNP elementi trebaju imati:

- `DNP` property
- BOM exclude flag gdje je potrebno
- jasno objašnjenje čemu služe

## 23.4 Active-low naming

Koristiti suffix:

`_N`

Primjeri:

- USB0_FAULT_N
- USB1_FAULT_N
- C6_RESET_N samo ako signal stvarno jest active-low

---

# 24. KiCad symbol strategy

## 24.1 Koristiti official symbols gdje postoje

Za generičke R/C/L i standardne IC-e.

## 24.2 Custom verified symbols

Obavezno ručno verificirati:

- ESP32-P4NRW32X
- ESP32-C6-WROOM-1-N4
- exact LCD connector
- exact USB connectors
- exact RCA
- exact microSD socket

Pin 1 i exposed pad greške su kritične.

## 24.3 Symbol review checklist

Za svaki custom IC:

- pin count
- pin number
- pin name
- electrical type
- power pins
- NC
- exposed pad
- footprint mapping

Ne koristiti community symbol bez usporedbe s originalnim datasheetom.

---

# 25. Footprint strategy

Prije povezivanja footprinta treba imati “footprint lock” listu.

## Must verify

- U1 ESP32-P4 package revision
- U2 WSON flash
- U3 TLV62569 DRL
- U4 ESP32-C6-WROOM
- U5 PCM5102A TSSOP
- U6 TPS25221 x2 DRC
- U7 TPS25947 RPW
- U8 TPS62132 RGT
- U9 MP3202 DJ
- LCD FPC
- USB-A ×2
- RCA ×2
- SD socket
- DC input

Za svaki footprint spremiti link na manufacturer mechanical drawing u property `Datasheet`.

---

# 26. Schematic design review gates

## Gate A — architecture

Prije crtanja:

- [x] P4-only arhitektura
- [x] PCM5102A MAIN
- [x] FLX4 CUE/UAC
- [x] dual USB
- [x] C6 SDIO
- [x] MIPI display
- [x] microSD

## Gate B — component lock

Prije finalnog capturea:

- [ ] P4 exact orderable v3.x MPN
- [ ] exact crystal
- [ ] exact LCD
- [ ] exact connectors
- [ ] final USB ILIM
- [ ] final backlight values

## Gate C — ERC

- [ ] zero unexplained ERC errors
- [ ] zero floating power pins
- [ ] every NC intentional
- [ ] every DNP intentional

## Gate D — pre-layout

- [ ] net classes assigned
- [ ] differential pairs named correctly
- [ ] connector pin 1 verified
- [ ] all test points included
- [ ] all debug nets included

---

# 27. Schematic bring-up sequence

Rev A board ne treba paliti “sve odjednom”.

## Phase 1 — naked power

Bez P4 firmware aktivnosti potvrditi:

- VIN
- eFuse output
- 3V3
- P4 core rail
- no abnormal current
- no hot component

## Phase 2 — P4 boot

Provjeriti:

- 40 MHz clock
- reset
- boot strap
- QSPI flash
- UART log

## Phase 3 — display/touch

- DSI output
- backlight
- touch I2C

## Phase 4 — microSD

- init
- read/write
- hot/reinsert behavior

## Phase 5 — PCM5102A

- BCLK
- LRCK
- DATA
- analog L/R
- noise floor

## Phase 6 — C6 Wi-Fi

- SDIO enumeration
- ESP-Hosted
- Wi-Fi
- web UI

## Phase 7 — USB0

- VBUS enable
- storage enumerate
- MP3 playback

## Phase 8 — USB1

- FLX4 enumerate
- MIDI
- LED
- UAC

## Phase 9 — combined load

- full backlight
- Wi-Fi
- USB0
- USB1
- dual-deck audio
- multi-hour soak

---

# 28. Brownout-specific design review

S obzirom na prototip, svaki schematic review mora posebno provjeriti:

1. Je li 5V_SYS topologija dovoljno niskoimpedantna?
2. Ima li USB0 vlastiti lokalni bulk C?
3. Ima li USB1 vlastiti lokalni bulk C?
4. Je li TPS25221 x2 input dovoljno dobro bypassan?
5. Je li 3V3 buck odvojen od USB VBUS load transienta?
6. Je li P4 core regulator lokalno pravilno decouplan?
7. Ima li input eFuse soft-start koji ne uzrokuje spor/pogrešan startup?
8. Postoji li dovoljno velik ulazni bulk reservoir?
9. Je li ground return USB powera odvojen fizički od osjetljivog audio dijela?
10. Mogu li se svi railovi mjeriti test pointovima?

---

# 29. Audio-specific design review

1. PCM5102A mora biti blizu RCA konektora.
2. I2S ne voditi uz analog output.
3. Backlight SW node daleko od audio područja.
4. P4 core DCDC daleko od RCA input/output trase.
5. RCA ground return direktno i široko prema GND planeu.
6. 3V3_AUDIO filter/0R option obavezno.
7. XSMT mora imati determinističko stanje na bootu.
8. Ne smije biti pop/glitch zbog floating control pina.

---

# 30. USB-specific design review

1. USB0 HS pair bez stuba.
2. USB0 ESD tik uz connector.
3. USB1 series R bliže source strani.
4. VBUS trace dimenzioniran na najmanje 1 A + margin.
5. TPS25221 x2 thermal pad layout po datasheetu.
6. FAULT pinovi imaju pull-up.
7. EN pinovi imaju definiran boot state.
8. shield strategy dokumentirana.
9. nema backfeed patha.
10. svaki port može se fizički power-cycleati.

---

# 31. MIPI-specific design review

1. DSI pair pinout potvrđen s LCD FPC datasheetom.
2. Pair polarity potvrđen.
3. lane0/lane1 mapping potvrđen.
4. DSI_REXT vrijednost i pin potvrđeni.
5. MIPI DPHY decoupling neposredno uz P4.
6. pair impedance definiran prema stackupu.
7. bez layer transitiona gdje nije nužno.
8. bez split planea ispod MIPI parova.
9. backlight power udaljen od DSI parova.

---

# 32. Recommended first KiCad files

Prvi konkretni commit nakon ovog plana trebao bi sadržavati:

```text
hardware/Pajoniiir-M1/
├── Pajoniiir-M1.kicad_pro
├── Pajoniiir-M1.kicad_sch
├── sheets/
│   ├── 01_POWER_INPUT.kicad_sch
│   ├── 02_POWER_3V3.kicad_sch
│   ├── 03_P4_CORE.kicad_sch
│   ├── 04_P4_FLASH_CLOCK_RESET.kicad_sch
│   ├── 05_C6_WIFI.kicad_sch
│   ├── 06_USB_POWER.kicad_sch
│   ├── 07_USB0_STORAGE.kicad_sch
│   ├── 08_USB1_FLX4.kicad_sch
│   ├── 09_AUDIO_PCM5102A.kicad_sch
│   ├── 10_DISPLAY_MIPI.kicad_sch
│   ├── 11_TOUCH_GT911.kicad_sch
│   ├── 12_MICROSD.kicad_sch
│   ├── 13_DEBUG_SERVICE.kicad_sch
│   ├── 14_TEST_MONITORING.kicad_sch
│   └── 15_DNP_OPTIONS.kicad_sch
├── symbols/
├── footprints/
└── docs/
```

Napomena: stvarni KiCad hijerarhijski sheet file layout treba potvrditi s načinom na koji KiCad sprema child sheet reference; struktura iznad je organizacijski cilj, ne razlog za ručno uređivanje KiCad S-expression datoteka.

---

# 33. Definition of Done za Schematic Rev A

Shema je spremna za PCB tek kad:

- svaki blok ima izvor i potrošač napajanja
- svaka naponska domena je dokumentirana
- svaki P4 pin ima poznatu funkciju ili NC
- P4 revizija je finalno potvrđena
- svi power regulator values su zaključani
- dual USB VBUS je dimenzioniran
- flash MPN je potvrđen
- LCD/FPC je finalan
- touch pinout je finalan
- RCA/USB/SD/DC footprints su mehanički potvrđeni
- ERC nema neobjašnjene greške
- BOM je reproducibilan
- test points pokrivaju sve kritične railove i busove
- schematic review je odrađen protiv datasheetova, ne samo protiv prethodne development ploče

---

# 34. Sljedeći konkretni korak

Nakon ovog plana treba prijeći s dokumentacije na stvarni ECAD projekt.

Preporučeni redoslijed capturea:

1. `01_POWER_INPUT`
2. `02_POWER_3V3`
3. `03_P4_CORE`
4. `04_P4_FLASH_CLOCK_RESET`
5. `06_USB_POWER`
6. `07_USB0_STORAGE`
7. `08_USB1_FLX4`
8. `09_AUDIO_PCM5102A`
9. `05_C6_WIFI`
10. `12_MICROSD`
11. `10_DISPLAY_MIPI`
12. `11_TOUCH_GT911`
13. `13_DEBUG_SERVICE`
14. `14_TEST_MONITORING`
15. `15_DNP_OPTIONS`

Razlog za ovaj redoslijed je da se najprije zaključa power integrity i P4 minimum-boot platforma, zatim USB/audio koji su ključni za samu funkciju Pajoniiira, a tek onda display i pomoćni blokovi.

---

# 35. Zaključak

Pajoniiir-M1 shemu treba projektirati kao **namjenski embedded audio/USB proizvod**, a ne kao smanjenu kopiju JC4880 development boarda.

Najvažnije arhitekturne odluke ovog plana su:

- jedan ESP32-P4 kao glavni procesor
- zaseban ESP32-C6 modul samo za radio/network funkcije
- vlastiti robustan 5V power tree
- dva fizički neovisno switchana USB VBUS kanala
- integrirani PCM5102A
- direktni MIPI DSI display
- direktni GT911 touch
- microSD preko native SDMMC
- puna bring-up i test infrastruktura
- bez S3/ES8311/camera/RS485 legacy sklopova

Time Rev A ostaje dovoljno jednostavan za proizvodnju, ali dovoljno instrumentiran da možemo precizno pronaći svaki problem tijekom prvog hardware bring-upa.

**Sljedeća faza:** izrada stvarnog KiCad projekta i prvog sheeta `01_POWER_INPUT`.

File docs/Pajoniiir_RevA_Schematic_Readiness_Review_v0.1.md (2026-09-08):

# Pajoniiir-M1 Rev A — Readiness Review v0.2

**Updated:** 2026-09-04

**Electrical milestone:** M1-ELEC-B2

**Mechanical milestone:** M1-MECH-B7

**Pre-layout milestone:** M1-PRELAYOUT-B5

**Status:** schematic ready; production PCB layout and fabrication release not ready

## Executive verdict

The Rev A electrical design is captured in the 15-sheet KiCad hierarchy and passes local structural, native KiCad 10.0.4 ERC and manufacturing-output checks. KiCad 10 is the sole current CI/ECAD toolchain. The B7 rebase makes the mainboard independent of display geometry. The user-confirmed DSI506 height remains profile evidence only.

```text
KiCad files loaded       16/16 PASS
ERC                      0 unexplained / 0 excluded / 0 warnings
Manufacturing BOM        244 source / 244 export PASS
DNP                      15
Blank-footprint gates     3
Mechanical blockers      12
Layout freeze             false
```

The design is ready for controlled exploratory placement and physical closure work. It is not ready for final placement, controlled-impedance routing, Gerbers or an EVT PCB order.

## Authority order

1. live KiCad schematic sources
2. `mechanical_gates.json`
3. `pcb_constraints.json` and the routing contract
4. B4 connector source lock
5. display compatibility profiles
6. historical display-mounted screening records
7. `Pajoniiir_Mainboard_BOM_v0.3.md`
8. global GPIO and hardware/firmware contracts
9. subsystem documents
10. explicitly superseded JC4880/M1-MECH-A documents as history only

## Completed electrical scope

| Block | Current state |
|---|---|
| 5 V input/eFuse | captured; D1 locked; J1/C3/C8 production packages open |
| 3.3 V system rail | captured around TPS62132 |
| ESP32-P4 v3.x core | captured with v3.x power/feedback contract |
| Flash/clock/boot | captured |
| ESP32-C6 SDIO/Wi-Fi | captured; RF placement/EVT open |
| USB0/USB1 VBUS | independent TPS25221 paths captured |
| USB0 HS data | captured; J2 footprint locked |
| USB1 FLX4 FS data | captured; J3 footprint locked |
| PCM5102A MAIN output | captured; J4/J5 footprints locked |
| Generic 15-pin DSI host | captured; J6 MPN/pin map/footprint locked |
| Touch/backlight | module-integrated over display I2C |
| microSD | captured; J7 footprint locked |
| Debug/service | captured; J9 gate closed |
| Power monitoring | INA238 and Kelvin shunt captured |
| DNP/DNL policy | captured and CI-checked |

## Current DSI interface readiness

The board provides a generic 15-pin Raspberry-Pi-style DSI host using Amphenol SFW15R-2STE1LF, 15 contacts, 1.0 mm, top-contact and right-angle. DSI506/DYL0023 is one validated display profile.

Electrical pin map, module power, DSI lanes and shared I2C are locked. The initial M3-derived firmware profile is also defined.

Remaining display work is physical:

- board-edge J6 placement and viable MIPI route
- generic insertion/removal service clearance
- per-display cable or adapter orientation
- supported-display startup/transient power budget

The retired ST7701S/GT911/MP3202 architecture is not a current blocker and must not be reintroduced.

## Current connector readiness

| Group | MPN | Footprint | Remaining work |
|---|---|---|---|
| J1 | Switchcraft 722RAHLP | open | unambiguous pad centers, wall/cutout and plug geometry |
| J2/J3 | Amphenol 87520-1010ALF | locked | final top-wall centers/cutouts/cables |
| J4/J5 | Kycon KLPX-0848A-2-W-G / -R-G | locked | final centers/cutouts/mated plugs |
| J6 | Amphenol SFW15R-2STE1LF | locked | board-edge placement, power budget and display-profile cables |
| J7 | Molex 503398-1892 | locked | slot, card access, screw and FFC clearance |
| SW1/SW2 | B3U-3000P-B | locked | recessed tool holes and local clearance |

Connector sourcing is substantially closed. The remaining gates are placement and enclosure integration gates.

## Mechanical readiness

Locked:

- mainboard is a standalone assembly
- display models cannot define board `Edge.Cuts`, mounts or connector coordinates
- JLCPCB four-layer 1.6 mm stackup
- J6 connector, footprint and 15-pin electrical map
- exact external connector part intent where recorded

Open:

- board-owned chassis mounting pattern and screw keepouts
- complete footprint/courtyard packing and critical-route feasibility
- component-height and thermal zones
- absolute panel datums and cutouts
- enclosure bosses/ribs/rear cover and thermal/ventilation review
- final `Edge.Cuts`

The former DSI506-derived board, mount and enclosure dimensions are historical profile screening and cannot constrain the production mainboard.

## Stackup and routing readiness

JLCPCB JLC04161H-7628 is locked as the four-layer, 1.6 mm fabrication stackup. Layer roles and critical route topology are locked.

Production impedance geometry remains open. Current 0.2332/0.15 mm USB and 0.1722/0.15 mm MIPI width/gap values are screening inputs only. A direct current JLCPCB calculator record and matching KiCad rules are required before route freeze.

## EVT choices still open

- C3/C8 production capacitance technology, ESR, ripple rating, MPN and package
- final USB current limits against measured devices
- 3.3 V all-on load and display transient margin
- RF performance in the final enclosure
- audio noise/pop behavior under display, USB and Wi-Fi activity
- microSD power-cycle and signal-integrity tuning
- crystal and optional tuning-element selections

Only C3/C8 currently block footprint completion. The remaining electrical items are validation gates for release quality.

## Go / no-go

| Activity | State |
|---|---|
| Schematic changes and ERC | GO |
| Manufacturing BOM/netlist/PDF generation | GO |
| Mechanical CAD and physical evidence capture | GO |
| Exploratory B5 placement | GO with screening labels |
| Final connector XY and `Edge.Cuts` | NO-GO |
| Final USB/MIPI routing | NO-GO |
| Gerbers / EVT board order | NO-GO |

## Next milestone

Close the remaining physical/EVT gates in this order:

1. J1 land pattern evidence
2. DSI FFC pin-1 continuity and bend/removal proof
3. local display obstruction map
4. enclosure walls/bosses/rear cover and absolute panel datums
5. screw/NPTH and final side-wing/outline geometry
6. C3/C8 EVT production selection
7. exact controlled-impedance geometry and KiCad rules
8. final placement, routing, PCB DRC and manufacturing review

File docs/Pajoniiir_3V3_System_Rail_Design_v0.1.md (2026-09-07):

# Pajoniiir Mainboard — 3V3 System Rail Design v0.1

**Captured update 2026-09-04:** `3V3_PG` is available at `TP26` on `02_POWER_3V3` with the existing pull-up. It is a diagnostic testpoint; no P4 GPIO is assigned. See [ERC closure](Pajoniiir_M1_ERC_Library_Closure_2026-09-04.md).

**Projekt:** Pajoniiir BL-A1800 / Pajoniiir-M1
**Ploča:** Pajoniiir Mainboard Rev A
**Blok:** 02_POWER_3V3
**Datum:** 2026-09-02
**Status:** Captured in KiCad; production validation remains EVT work

> **Post-capture update (2026-09-06):** The TPS62132 design is captured. `3V3_DISPLAY_MODULE` powers the generic 15-pin J6 interface; DSI506 is one validated 340 mA profile. The production rail budget must cover the supported display matrix, and all-on/startup/transient margin remains EVT work.

---

# 1. Cilj

Ovaj blok pretvara `5V_SYS` u glavni digitalni `3V3_SYS` rail.

Glavni kandidat je:

**TPS62132RGTR**

Važna korekcija u odnosu na raniji preliminarni BOM:

- TPS62132 = fixed **3.3 V**
- TPS62133 = fixed **5.0 V**

Za Pajoniiir se zato koristi TPS62132.

---

# 2. Zašto TPS62132

TPS62132 je aktivni TI synchronous buck:

- VIN = 3–17 V
- fixed VOUT = 3.3 V
- do 3 A
- DCS-Control
- oko 2.5 MHz default switching frequency
- programmable soft-start
- Power Good
- 100% duty-cycle mode
- QFN 3×3 mm

Za Rev A je koristan jer je dovoljno snažan, dobro dokumentiran i fizički nije ekstremno sitan.

TI navodi noviji TPS62903 kao alternativu, ali za prvi Pajoniiir PCB ostajemo na TPS62132 jer je 3×3 mm QFN zahvalniji za prototipiranje i debug.

---

# 3. Consumers of 3V3_SYS

Glavni 3.3 V rail napaja:

- ESP32-P4 relevantne 3.3 V power domene
- external QSPI flash
- ESP32-C6-WROOM-1
- PCM5102A
- GT911 / touch logiku gdje je kompatibilno
- microSD
- LCD logic rail gdje finalni panel zahtijeva 3.3 V
- pull-up mreže
- debug/status logiku

P4 `VDD_HP` core rail nije direktno 3.3 V load nego se iz 3V3_SYS generira lokalnim TLV62569 core DCDC blokom.

---

# 4. Topologija

```text
5V_SYS
  |
  +---- 10uF
  +---- 100nF
  |
  v
TPS62132
  |
  SW
  |
  +---- L = 2.2uH
  |
  v
3V3_SYS
  |
  +---- 22uF
  +---- local bulk/distribution
```

---

# 5. U8 — TPS62132RGTR pin strategy

```text
PVIN  -> 5V_SYS
AVIN  -> 5V_SYS
EN    -> enabled from 5V_SYS / sequencing option
SW    -> inductor
VOS   -> 3V3_SYS sense
PG    -> 3V3_PG
FB    -> AGND on fixed-output version
SS/TR -> soft-start capacitor
DEF   -> LOW for nominal 3.3V
FSW   -> LOW for ~2.5MHz default
AGND  -> GND / exposed pad
PGND  -> GND / exposed pad
EPAD  -> GND plane
```

TI za fixed-output verzije preporučuje FB spojiti na AGND.

---

# 6. Input capacitors

TI reference design za 3.3 V/3 A koristi:

- 10 µF input
- 0.1 µF high-frequency bypass

Rev A:

| RefDes | Value | Type |
|---|---:|---|
| C_3V3_IN1 | 10 µF | X7R/X5R, ≥10 V |
| C_3V3_IN2 | 100 nF | X7R, ≥10 V |

Oba moraju biti neposredno uz PVIN/AVIN power loop.

Dodatni 10 µF footprint može se ostaviti DNP ako transient test pokaže potrebu.

---

# 7. Inductor

TI reference 3.3 V/3 A aplikacija koristi:

**1 µH ili 2.2 µH**

Za Pajoniiir Rev A preferiramo:

**2.2 µH**

Razlozi:

- niži ripple
- bolji EMI margin
- TI ga koristi u karakterizacijskim grafovima
- prikladan za full 3 A rail

Za FSW ≈ 2.5 MHz 2.2 µH je konzervativan izbor.

Kandidat klase:

```text
2.2 µH
shielded
Isat >= 4.5–5 A preferred
low DCR
~4x4 mm class
```

Exact MPN ostaje TBD nakon availability/thermal provjere.

---

# 8. Output capacitor

TI tipična 3.3 V shema:

**22 µF**

Rev A:

| RefDes | Value | Type |
|---|---:|---|
| C_3V3_OUT1 | 22 µF | X7R/X5R, ≥6.3 V |
| C_3V3_OUT2 | 100 nF | X7R |

Važno je računati DC-bias gubitak ceramic capacitance.

Ako nominalni 22 µF MLCC pod 3.3 V realno padne znatno ispod toga, koristiti:

- veći package
- viši voltage rating
- ili 2×22 µF

Predvidjeti mjesto za drugi 22 µF DNP footprint.

---

# 9. FSW

Pin FSW ima internal pulldown.

LOW daje približno:

**2.5 MHz**

To je default Rev A konfiguracija.

Prednosti:

- manji inductor
- brži transient response
- jednostavan reference layout

Ako kasnije EMI/audio mjerenje pokaže problem, moguće je razmotriti 1.25 MHz mode.

Za Rev A:

```text
FSW = GND / default LOW
```

uz opcionalni 0 Ω strap footprint.

---

# 10. DEF

TPS62132 DEF:

- LOW = nominal 3.3 V
- HIGH = nominal +5%

Pajoniiir treba:

```text
DEF = LOW
```

Ne trebamo 3.465 V margin mode kao normalni rad.

Ostaviti 0 Ω strap kako bi se u laboratoriju mogao testirati +5% rail ako ikad zatreba, ali DNP alternativni path.

---

# 11. Soft-start

TI reference circuit koristi:

**3.3 nF** na SS/TR.

Rev A default:

```text
C_SS = 3.3 nF
```

Cilj je clean startup nakon 5V_SYS eFuse ramp-a.

Treba osciloskopom provjeriti odnos:

- 5V_SYS rise
- 3V3_SYS rise
- P4 CHIP_PU
- P4 VDD_HP

Ako je 3V3 startup prerano ili prebrz, C_SS se može povećati.

---

# 12. EN

EN ima internal pulldown, pa mora biti deterministički high za normalni rad.

Najjednostavniji Rev A:

```text
5V_SYS -> R_EN -> EN
```

Početni R_EN:

**100 kΩ**

Opcionalno dodati footprint kojim P4 ili supervisor može u budućnosti preuzeti enable.

Međutim, P4 ne može biti jedini kontroler vlastitog 3V3 regulatora tijekom cold boot-a.

Zato default mora biti hardware enabled.

---

# 13. Power Good

PG je open-drain.

Net:

```text
3V3_PG
```

Početni pull-up:

```text
R_PG = 100 kΩ -> 3V3_SYS
```

TI reference figure koristi 100 kΩ.

Preporuka:

- dovesti `3V3_PG` na P4/supervisor samo ako startup architecture to koristi
- obavezno test point

PG je koristan tijekom bring-upa za dokaz da regulator nije samo “oko 3.3 V” nego je u regulation windowu.

---

# 14. VOS routing

VOS je output sense.

Ne uzimati VOS sa switch/inductor hot područja.

Routing pravilo:

```text
VOS sense point
   |
   +--- na 3V3_SYS kod output capacitor/load distribution nodea
```

Sense trace treba biti quiet Kelvin-like route prema stvarnom output nodeu.

---

# 15. Grounding

TPS62132 ima:

- AGND
- PGND
- exposed thermal pad

Sve ih treba povezati na common GND prema TI layout primjeru.

Ne raditi fizički odvojene “analog” i “power” ground otoke sa tankim spojem.

Umjesto toga:

- solid L2 ground plane
- kratki PGND return
- thermal vias ispod exposed pada
- AVIN/AGND layout tih i kompaktan

---

# 16. Switch node

`SW` je najbučniji net ovog bloka.

Pravila:

- minimalna površina
- vrlo kratko do L
- ne routeati ispod C6 antene
- ne routeati uz PCM5102A analog output
- ne routeati uz MIPI/USB HS ako nije nužno
- bez test pointa na finalnom proizvodu

Za EVT se eventualno može ostaviti mali scope pad, ali nije preporučen kao standardni TP.

---

# 17. Power distribution

Nakon output capacitor nodea:

```text
3V3_SYS
  |
  +---- P4 domains
  +---- P4 core DCDC input
  +---- FLASH
  +---- C6 filter -> 3V3_C6
  +---- AUDIO filter -> 3V3_AUDIO
  +---- microSD
  +---- touch
  +---- display logic
```

C6 i audio trebaju imati lokalni 0 Ω / ferrite option:

```text
3V3_SYS -- 0R/FB --> 3V3_C6
3V3_SYS -- 0R/FB --> 3V3_AUDIO
```

Default Rev A može koristiti 0 Ω, a ferrite se populira tek ako EMI/noise mjerenje pokaže korist.

---

# 18. Estimated load strategy

Ne zaključavamo finalni 3V3 current budget samo iz datasheet maksimuma.

Rev A treba mjeriti stvarni rail current u stanjima:

1. P4 boot
2. LCD/touch
3. Wi-Fi idle
4. Wi-Fi TX
5. SD read
6. USB0 active
7. USB1 active
8. dual-deck decode/DSP
9. all-on worst case

TPS62132 3 A daje dobru rezervu, ali thermal/layout validacija ostaje obavezna.

---

# 19. Test points

Obavezno:

```text
TP_5V_SYS_BUCK_IN
TP_3V3_SYS
TP_3V3_PG
TP_GND_3V3
```

Opcionalno:

```text
TP_SS_TR
```

Ne preporučuje se veliki SW testpoint.

---

# 20. Preliminary RefDes table

| RefDes | Part/value | Status |
|---|---|---|
| U8 | TPS62132RGTR | LOCK-CANDIDATE |
| C20 | 10 µF, ≥10 V | input |
| C21 | 100 nF, ≥10 V | input HF |
| C22 | 3.3 nF | SS/TR |
| L2 | 2.2 µH, Isat ≥4.5–5 A preferred | TBD MPN |
| C23 | 22 µF, ≥6.3 V | output |
| C24 | 22 µF | optional DNP output reserve |
| C25 | 100 nF | output HF |
| R20 | 100 kΩ | EN pull-up |
| R21 | 100 kΩ | PG pull-up |
| R22 | 0 Ω | FSW LOW strap / config |
| R23 | 0 Ω | DEF LOW strap / config |
| FB_C6 | 0 Ω default / ferrite option | branch |
| FB_AUDIO | 0 Ω default / ferrite option | branch |

---

# 21. KiCad nets

Inputs:

```text
5V_SYS
```

Outputs:

```text
3V3_SYS
3V3_PG
```

Derived child rails:

```text
3V3_C6
3V3_AUDIO
```

Local:

```text
BUCK_SW
BUCK_SS_TR
BUCK_EN
BUCK_FSW
BUCK_DEF
```

---

# 22. Bring-up measurement

Oscilloscope:

CH1 = 5V_SYS
CH2 = 3V3_SYS
CH3 = 3V3_PG
CH4 = P4_VDD_HP

Provjeriti:

- monotonic 3V3 rise
- PG transition
- no overshoot
- no repeated startup
- load transient recovery
- rail noise

---

# 23. Acceptance criteria

Blok prolazi ako:

- 3V3_SYS = unutar TPS62132 regulation tolerance
- boot transient ne spušta rail ispod P4 dopuštenja
- Wi-Fi TX burst ne uzrokuje reset
- microSD access ne uzrokuje vidljiv rail collapse
- converter ne ulazi u thermal limit
- output ripple prihvatljiv
- nema audio-correlated switching artefakta
- PG je stabilan pri normalnom radu

---

# 24. Layout constraints

Najvažniji layout loopovi:

```text
5V_SYS -> input C -> PVIN -> internal FET -> SW -> L -> COUT -> PGND
```

moraju biti vrlo kompaktni.

Preporučeni placement:

```text
CIN
 |
U8 -- L2 -- COUT
 |          |
GND plane --+
```

VOS sense voditi od output nodea, ne iz SW hot zone.

---

# 25. Zaključak

Rev A 3V3 system rail:

```text
U8      = TPS62132RGTR
VIN     = 5V_SYS
VOUT    = 3.3 V
IOUT    = up to 3 A
L       = 2.2 µH initial
CIN     = 10 µF + 100 nF
COUT    = 22 µF + optional second 22 µF
C_SS    = 3.3 nF
FSW     = LOW (~2.5 MHz)
DEF     = LOW (nominal 3.3 V)
FB      = AGND
PG pull = 100 kΩ
```

Ovim su prva dva power bloka dovoljno definirana da možemo prijeći na:

**03_P4_CORE — ESP32-P4 v3.x power domains, decoupling i TLV62569 VDD_HP regulator.**

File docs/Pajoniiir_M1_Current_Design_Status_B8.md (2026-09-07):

# Pajoniiir-M1 current design status B8

**Date:** 2026-09-06

**Electrical milestone:** M1-ELEC-B2

**Mechanical milestone:** M1-MECH-B7

**Pre-layout milestone:** M1-PRELAYOUT-B8

**Layout state:** populated board-first placement canvas; `layout_freeze_allowed=false`

## Product boundary

Pajoniiir-M1 is the primary product assembly: a standalone ESP32-P4 mainboard. Its PCB outline, mounting holes, connector locations, height zones and enclosure datums must be derived from the board's own component packing, routing, thermal, service and manufacturing requirements.

The screen is a replaceable external peripheral. No display PCB, display mounting-post pattern or display enclosure may define the M1 board geometry.

The active machine authority is `hardware/Pajoniiir-M1/board_first_mechanical_contract.json`. `mech_a.json`, `mechanical_gates.json` and `pcb_constraints.json` are synchronized to that boundary.

## Electrical state

The hierarchical KiCad design contains 15 leaf sheets. Current structural validation passes with all 15 sheets and the intentional blank-footprint policy remains limited to J1, C3 and C8. Local KiCad 10 ERC previously passed with zero violations after power-good test points, no-connect markers and library closure were added.

The board retains these main functions:

- ESP32-P4 with ESP32-C6 over four-bit SDIO
- independent USB host ports and switched VBUS branches
- PCM5102A stereo MAIN output
- native four-bit SDMMC microSD
- power protection, current measurement and power-good diagnostics
- generic 15-pin Raspberry-Pi-style MIPI DSI host interface

## Display interface and compatibility

J6 is the board interface, using Amphenol `SFW15R-2STE1LF`, 15 contacts at 1.0 mm pitch, top contact, right-angle SMT ZIF. The locked electrical map routes DSI clock, lane 0, lane 1, shared display I2C and `3V3_DISPLAY_MODULE`.

EYOYO DSI506 / DYL0023 is one validated compatibility profile. Pajoniiir-M3 evidence confirms its electrical map and operating profile, and the supplied photos confirm its Type-B FFC construction. Those facts do not make DSI506 the final product display or the mechanical datum for M1.

Every additional display model must qualify:

- the same 15-pin electrical map, or an explicit adapter;
- startup, steady-state and transient current on `3V3_DISPLAY_MODULE`;
- DSI lanes, rate, pixel format and timing;
- touch/controller I2C behavior where used;
- cable contact orientation, insertion and service envelope.

Type-B is a DSI506 cable fact, not a universal M1 requirement. The board-side connector remains fixed; a cable or adapter profile resolves model-specific orientation.

## Mechanical rebase

The following values are retained only as DSI506-specific or historical screening evidence:

- 58 x 49 mm DSI506 rear-post pattern;
- 104 x 62 mm display-derived board screen;
- 128 x 84 x 30 mm display-derived enclosure screen;
- the 1.4455 mm DSI506 right-edge FFC clearance result;
- all JC4880 enclosure, mount and Z-stack geometry.

They are forbidden as production `Edge.Cuts`, mainboard mounting or connector-placement authority. The B2 through B6 display-specific records remain useful when designing a DSI506 bracket, cable kit or enclosure variant.

The board outline and its chassis mounting pattern remain open. `m1_board_packing_inventory_b7.json` closed the inventory step with 247 schematic components, 244 assigned footprints, 3 intentional blank footprints and 33 footprint classes including the blank-gate class.

M1-PRELAYOUT-B8 now populates the live PCB with all 244 assigned footprints and 193 named schematic nets. Eight `Dwgs.User` rectangles separate the working electrical domains: power spine, USB edges, audio, P4 core, C6 RF, DSI host, storage and service. There are no footprint bounding-box overlaps, tracks, zones or `Edge.Cuts`. These rectangles and their XY coordinates are a reversible working canvas, not connector, mounting or enclosure datums.

## Locked and open items

Locked today:

- electrical connectivity and current 15-sheet hierarchy;
- J6 part, footprint and 15-pin electrical map;
- JLCPCB `JLC04161H-7628` four-layer, 1.6 mm stackup;
- most external connector MPN and footprint intent;
- DSI506 electrical/firmware compatibility profile;
- `layout_freeze_allowed=false` while blockers remain.

The 12 layout blockers remain:

```text
C3_INPUT_BULK
C8_PROTECTED_BULK
J1_POWER_INPUT
SW1_RESET
SW2_BOOT
J2_USB0
J3_USB1
J4_RCA_L
J5_RCA_R
J_LCD_DISPLAY_FPC
J7_MICROSD
PCB_OUTLINE
```

The meaning of the last two gates changed at B7. `J_LCD_DISPLAY_FPC` now asks for board-edge J6 placement, generic service access, branch power qualification and per-display cable profiles. `PCB_OUTLINE` now asks for a board-owned outline and chassis mount derived from completed packing and routing evidence.

## Next board work

1. Tighten the P4 core and flash island around U1 using the Espressif escape and decoupling constraints; keep all B8 coordinates movable.
2. Place U4 at a candidate outer edge, preserve its all-layer antenna keepout and prove the four-bit SDIO escape to U1.
3. Compact the power spine and connector domains around those two critical islands, then derive a minimum feasible board envelope.
4. Add an independent chassis mounting-hole pattern and validate mated cables, height zones and thermal clearance.
5. Close J1/C3/C8 EVT and exact controlled-impedance geometry before final routing freeze.

No Gerber or EVT order is authorized while the outline and blocking gates remain open.

## Validation

```bash
python hardware/Pajoniiir-M1/tools/validate_schematic_structure.py
python hardware/Pajoniiir-M1/tools/validate_mechanical_authority.py
python hardware/Pajoniiir-M1/tools/validate_board_packing_inventory.py
python hardware/Pajoniiir-M1/tools/report_mech_gate_snapshot.py
"C:/Program Files/KiCad/10.0/bin/python.exe" hardware/Pajoniiir-M1/tools/validate_board_placement_b8.py \
  --board hardware/Pajoniiir-M1/Pajoniiir-M1.kicad_pcb \
  --netlist <fresh-kicad-xml-netlist> \
  --report hardware/Pajoniiir-M1/m1_board_placement_seed_b8.json
```

The former B4 panel-window and B5 display-mounted placement validators are no longer CI gates because their coordinate systems were tied to DSI506. Their JSON outputs are explicitly marked historical screening only.

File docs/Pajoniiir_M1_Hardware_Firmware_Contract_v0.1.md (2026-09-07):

# Pajoniiir-M1 — Hardware / Firmware Contract v0.2

**Projekt:** Pajoniiir-M1 Rev A
**Datum:** 2026-09-06
**Status:** Current pre-bring-up custom-PCB contract after M1-ELEC-B2 implementation

---

## 1. Purpose

The custom M1 PCB gets a dedicated firmware target:

```text
bsp_pajoniiir_m1
```

The board is a standalone M1-specific power/USB/audio/service platform with a generic 15-pin Raspberry-Pi-style DSI host interface. DSI506/DYL0023 is one validated display profile already accepted in Pajoniiir-M3.

The M3 DSI506 BSP is the reference for that display profile. Other supported displays require their own timing, controller, touch and cable profile; the board must not carry forward the old 4.3-inch ST7701S/GT911/MP3202 assumptions.

---

## 2. Silicon contract

```text
ESP32-P4NRW32X
production target silicon v3.2+
```

M1 and old JC4880 binaries remain separate build artifacts.

---

## 3. GPIO contract

```text
GPIO7   DISPLAY_I2C_SDA
GPIO8   DISPLAY_I2C_SCL

GPIO14  C6_SDIO_D0
GPIO15  C6_SDIO_D1
GPIO16  C6_SDIO_D2
GPIO17  C6_SDIO_D3
GPIO18  C6_SDIO_CLK
GPIO19  C6_SDIO_CMD

GPIO20  USB0_PWR_EN
GPIO21  USB0_FAULT_N
GPIO22  USB1_PWR_EN
GPIO24  P4_USB_SERIAL_JTAG_DM
GPIO25  P4_USB_SERIAL_JTAG_DP
GPIO26  USB1_FS_DM
GPIO27  USB1_FS_DP
GPIO32  USB1_FAULT_N

GPIO35  BOOT
GPIO36  BOOT_STRAP_HIGH
GPIO37  UART0_TX
GPIO38  UART0_RX

GPIO39  SDMMC_D0
GPIO40  SDMMC_D1
GPIO41  SDMMC_D2
GPIO42  SDMMC_D3
GPIO43  SDMMC_CLK
GPIO44  SDMMC_CMD
GPIO45  SD_PWR_EN
GPIO46  SD_CARD_DETECT optional

GPIO49  DAC_XSMT
GPIO50  DAC_BCLK
GPIO51  DAC_DATA
GPIO52  DAC_LRCK
GPIO53  SYS_POWER_ALERT_N optional
GPIO54  C6_RESET
```

Released by the final display migration:

```text
GPIO3  old TOUCH_RST
GPIO4  old TOUCH_INT
GPIO5  old LCD_RST
GPIO6  old LCD_TE
GPIO23 old LCD_BL_PWM
```

These are free candidates, not automatically assigned to new features.

---

## 4. Final display connector contract

The final module uses a 15-pin 1.0 mm DSI connector:

```text
1   GND
2   DSI DATA1-
3   DSI DATA1+
4   GND
5   DSI CLK-
6   DSI CLK+
7   GND
8   DSI DATA0-
9   DSI DATA0+
10  GND
11  I2C SCL  -> GPIO8
12  I2C SDA  -> GPIO7
13  GND
14  3V3
15  3V3
```

M1 routes clock, lane0 and lane1. Initial firmware activates lane0 only because that profile is already accepted on the same module in M3.

---

## 5. DSI PHY/video contract

P4 internal MIPI LDO remains required:

```text
LDO channel 3
2500 mV
VDD_MIPI_DPHY
```

Initial display profile:

```text
resolution       800 x 480
orientation      native landscape
DSI lanes active 1
lane rate        800 Mbps
format           RGB888
DPI clock        27.777 MHz
HFP/HSW/HBP      59 / 2 / 45
VFP/VSW/VBP      109 / 2 / 22
mode             burst with sync pulses
frame ACK        off
```

Do not copy the old ST7701S 480x800 / 500 Mbps / RGB565 init table into the M1 target.

Lane1 stays physically routed even though the initial profile does not use it.

---

## 6. Shared display I2C contract

```text
SDA GPIO7
SCL GPIO8
100 kHz
```

Known module devices:

```text
0x38 touch
0x45 panel power/backlight controller
0x18 additional module response observed in M3 diagnostics
```

Do not issue generic register writes to unknown `0x18`.

---

## 7. Touch contract

The accepted touch path is FT5426/FT5x06-compatible at `0x38`.

No dedicated M1 GPIO reset or interrupt is carried by the 15-pin interface.

Initial transform:

```text
swap_xy  = 0
mirror_x = 1
mirror_y = 1
```

The accepted bus rate is **100 kHz**. Do not raise it to 400 kHz by default; M3 found 400 kHz caused runtime touch read failures on this module.

---

## 8. Panel power/backlight contract

The module-local controller at `0x45` owns panel power and brightness.

Known M3 register contract:

```text
0x85 POWERON
0x86 PWM
0x81 PORTA
```

Baseline startup concept:

1. initialize shared I2C,
2. attach `0x45`,
3. PWM = 0,
4. POWERON = 0 and settle,
5. acquire 2.5 V MIPI LDO,
6. create DSI host,
7. POWERON = 1,
8. allow panel/controller settle,
9. create/start DPI video,
10. set required module enable/orientation state,
11. ramp PWM through `0x45`.

The final M1 PCB does **not** use GPIO23 external PWM and does not populate an MP3202 WLED boost for this display.

Do not move the display module's 0-ohm external-PWM selector in baseline production.

---

## 9. Display power contract

Module supply:

```text
3V3_DISPLAY_MODULE
pins 14 + 15
GND pins 1/4/7/10/13
```

M3 specification evidence records up to **340 mA** at 3.3 V.

M1 TPS62132 is a 3 A-class 3.3 V regulator, so regulator nameplate capacity passes first-order screening. The following remain mandatory before release:

- all-on M1 3V3 current measurement,
- cold-start rail droop/overshoot,
- display enable/backlight transients,
- local connector bulk/decoupling validation.

Use a dedicated `3V3_DISPLAY_MODULE` branch with a 0-ohm/ferrite option and local capacitance.

---

## 10. USB VBUS contract

Both ports power up hardware-off.

```text
USB0 EN GPIO20 / FAULT GPIO21
USB1 EN GPIO22 / FAULT GPIO32
```

Stagger enable to avoid simultaneous inrush. Fault recovery should power-cycle only the affected port before escalating to a system reset.

USB0 remains the P4 dedicated HS storage root. USB1 FS remains GPIO26/27 for DDJ-FLX4.

---

## 11. PCM5102A contract

```text
GPIO50 BCLK
GPIO52 LRCK
GPIO51 DATA
GPIO49 XSMT
MCLK unused
```

Hold XSMT low through boot/reconfiguration and unmute only after clocks/stream are stable.

---

## 12. microSD / C6 / service contracts

microSD:

```text
D0..D3 GPIO39..42
CLK GPIO43
CMD GPIO44
power enable GPIO45
card detect GPIO46 optional
```

ESP32-C6 SDIO:

```text
D0..D3 GPIO14..17
CLK GPIO18
CMD GPIO19
RESET GPIO54
```

Recovery/service remains UART0 GPIO37/38 plus USB Serial/JTAG pogo on GPIO24/25.

---

## 13. Bring-up acceptance for M1 display

M1 hardware bring-up starts from the M3-known-good profile and then verifies the custom PCB:

- 3.3 V module rail startup and current,
- DPHY 2.5 V,
- `0x38` and `0x45` presence,
- stable 800x480 image,
- correct color order,
- touch at 100 kHz,
- brightness 0..100 through `0x45`,
- cold boot/reconnect,
- sustained UI/waveform scanout,
- no display-induced audio/USB regression.

A failure on the M1 custom PCB should first be treated as a board/power/SI/integration regression against a known-good module profile, not as a reason to invent a new panel driver.

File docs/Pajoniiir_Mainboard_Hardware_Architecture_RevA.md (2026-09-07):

# Pajoniiir Mainboard — Hardverska arhitektura i početni PCB BOM

> **HISTORICAL ARCHITECTURE RECORD.** The active Rev A display and mechanical architecture changed after this record. Do not use this document's JC4880/ST7701S/GT911/MP3202, old enclosure or pre-capture BOM statements as current authority. Use `Pajoniiir_M1_Current_Design_Status_B8.md`, the live KiCad hierarchy and current machine-readable contracts.

**Projekt:** Pajoniiir BL-A1800
**Repozitorij:** `dvucinozd/Pajoniiir`
**Branch:** `feat/p4-dual-usb-host`
**Analizirani commit:** `af597d8`
**Namjena dokumenta:** početni hardverski baseline za izradu vlastite Pajoniiir PCB ploče
**Datum:** 2026-09-02

---

## 1. Cilj dokumenta

Cilj ovog dokumenta je pretvoriti postojeći Pajoniiir prototip, koji trenutno koristi razvojnu ploču **Guition JC4880P443C_I_W** i vanjski **PCM5102A** modul, u jasnu i proizvodno upotrebljivu hardversku arhitekturu za vlastitu tiskanu ploču.

Dokument nije samo popis modula koji su danas fizički spojeni, nego popis funkcionalnih i električnih blokova koji moraju postojati na budućoj Pajoniiir Mainboard ploči.

Posebno su obrađeni:

- ESP32-P4 glavni procesor
- memorija i flash
- ESP32-C6 Wi-Fi koprocesor
- 4.3" MIPI DSI zaslon
- GT911 touch
- microSD
- PCM5102A MAIN audio izlaz
- dual USB host
- zaštita i napajanje USB VBUS-a
- glavno napajanje
- zaštite
- debug/programiranje
- testne točke
- komponente koje više nisu potrebne
- prijedlog Rev A arhitekture
- prijedlog početnog Engineering BOM-a

---

# 2. Sažetak trenutne Pajoniiir arhitekture

Na branchu `feat/p4-dual-usb-host` Pajoniiir je sada **P4-only** uređaj.

Stari ESP32-S3 više nije dio aktivne proizvodne arhitekture.

Glavni ESP32-P4 direktno obavlja:

- USB0 mass-storage host za Rekordbox USB medij
- USB1 host za DDJ-FLX4
- USB MIDI IN
- USB MIDI OUT / LED feedback
- USB Audio Class prema FLX4
- dva decka
- audio decode
- audio DSP
- mixing
- MAIN izlaz preko PCM5102A
- CUE/PFL prema FLX4 headphone izlazu
- Rekordbox library
- microSD
- LVGL korisničko sučelje
- touch
- Wi-Fi/web UI preko ESP32-C6
- OTA firmware update
- controller profile sustav

Aktivna arhitektura može se svesti na:

```text
                         ┌──────────────────────┐
                         │      ESP32-P4        │
                         │                      │
Rekordbox USB ─ USB0 ──► │ HS USB HOST          │
                         │                      │
DDJ-FLX4 ───── USB1 ───► │ USB HOST             │
 MIDI + UAC 4ch          │                      │
                         │                      │
                         │ I2S                  │
                         └──────┬───────────────┘
                                │
                          BCLK / LRCK / DATA
                                │
                         ┌──────▼───────┐
                         │   PCM5102A   │
                         │   MAIN DAC   │
                         └─────┬────┬───┘
                               │    │
                              RCA  RCA
                               L    R

ESP32-P4 ── MIPI DSI ──► ST7701S 4.3" LCD
ESP32-P4 ── I²C ───────► GT911 Touch
ESP32-P4 ── SDMMC ─────► microSD
ESP32-P4 ── SDIO ──────► ESP32-C6 ── Wi-Fi

CUE/PFL ────────────────► USB UAC CH3/CH4
                           │
                           ▼
                    DDJ-FLX4 headphone jack
```

---

# 3. Osnovna projektna filozofija nove PCB ploče

Nova ploča ne bi trebala biti kopija Guition JC4880P443C_I_W.

Guition ploča je univerzalna HMI/multimedijska development ploča i sadrži više sklopova koji Pajoniiiru više nisu potrebni.

Nova PCB treba biti:

- specifična za Pajoniiir
- P4-only
- dual USB host
- s robusnim VBUS napajanjem
- s integriranim PCM5102A
- s integriranim Wi-Fi modulom
- s MIPI DSI display sučeljem
- s GT911 touchom
- s microSD
- s dovoljnom rezervom napajanja
- s dobrim debug i test mogućnostima

Preporučeni naziv:

**Pajoniiir Mainboard Rev A**

---

# 4. Glavni procesor

## 4.1 ESP32-P4

Za novi dizajn ne preporučuje se kopiranje stare ESP32-P4 revizije koja se nalazi na Guition ploči.

Za novu ploču preporučeni kandidat je novija ESP32-P4 revizija s integriranim 32 MB PSRAM-a.

### Preporučena varijanta

**ESP32-P4NRW32X**

Cilj je zadržati:

- 32 MB PSRAM
- dovoljno memorije za LVGL
- waveform cache
- compressed audio cache
- dva decka
- USB stack
- audio DSP
- Rekordbox parser
- OTA
- web UI

### Razlog

Tvoj firmware već aktivno koristi 32 MB PSRAM-a.

U `sdkconfig.defaults` postoje:

```text
CONFIG_SPIRAM=y
CONFIG_SPIRAM_USE_MALLOC=y
CONFIG_SPIRAM_MODE_HEX=y
CONFIG_SPIRAM_SPEED_200M=y
CONFIG_SPIRAM_FETCH_INSTRUCTIONS=y
CONFIG_SPIRAM_RODATA=y
CONFIG_SPIRAM_XIP_FROM_PSRAM=y
CONFIG_SPIRAM_FLASH_LOAD_TO_PSRAM=y
```

Dakle 32 MB PSRAM nije luksuz nego dio trenutne arhitekture.

---

# 5. Firmware flash

Pajoniiir trenutno koristi 16 MB firmware flash.

To treba zadržati zbog:

- ESP-IDF
- LVGL
- USB stacka
- audio codeca
- DSP-a
- controller profila
- OTA A/B particija
- rollback mehanizma
- coredump particije

### Preporuka

**16 MB / 128 Mbit QSPI NOR Flash**

Primjeri klase:

- Winbond W25Q128
- GD25Q128
- ISSI IS25LP128
- ekvivalent koji je podržan i provjeren za ESP32-P4

### Obavezni pomoćni elementi

- 100 nF decoupling uz flash
- pull-up na CS prema Espressif preporuci
- 0 Ω tuning footprintovi na SPI signalima
- kvalitetan GND reference plane
- vrlo kratke veze prema P4

---

# 6. P4 clock

ESP32-P4 zahtijeva vanjski glavni clock.

### Y1

**40 MHz crystal**

Preporučene karakteristike:

- 40 MHz
- ±10 ppm ili bolje
- odgovarajući ESR
- odgovarajući CL
- mala kućišna izvedba, npr. 3225 ili 2520

Load kondenzatori moraju biti izračunati prema konkretnom kristalu.

Za Rev A korisno je predvidjeti footprintove tako da se vrijednosti mogu tuningom promijeniti bez izmjene PCB-a.

---

# 7. Reset / Boot / Strapping

Nova ploča treba imati barem:

### SW1 — RESET

Povezan na `CHIP_PU`.

Preporučeni reset network:

- 10 kΩ pull-up
- 1 µF prema GND
- tipka prema GND

### SW2 — BOOT

Za ručni ulazak u download/programming mode.

### Dodatno

Preporučuje se dovesti:

- CHIP_PU
- BOOT
- UART TX
- UART RX
- GND
- 3V3

na debug header ili pogo-pin test pads.

---

# 8. ESP32-P4 core napajanje

ESP32-P4 zahtijeva dobro projektirano napajanje.

Posebnu pažnju treba posvetiti VDD_HP/core DCDC dijelu.

### Kandidat

**TLV62569**

ili drugi Espressif odobren regulator za konkretnu P4 reviziju.

Uz njega trebaju:

- odgovarajući induktor
- input kondenzatori
- output kondenzatori
- feedback otpornici
- vrlo kratka high-current switching petlja
- dobar GND plane

### Važno

Za novu reviziju ESP32-P4 mora se koristiti aktualni Espressif reference design.

Ne treba 1:1 kopirati power dio sa stare Guition P4 revizije.

---

# 9. ESP32-C6 Wi-Fi koprocesor

ESP32-P4 nema integrirani Wi-Fi.

Tvoj firmware koristi ESP-Hosted preko SDIO prema C6.

Trenutni firmware koristi približno:

```text
P4 GPIO18  -> SDIO CLK
P4 GPIO19  -> SDIO CMD
P4 GPIO14  -> SDIO D0
P4 GPIO15  -> SDIO D1
P4 GPIO16  -> SDIO D2
P4 GPIO17  -> SDIO D3
P4 GPIO54  -> C6 RESET
```

## Preporuka

Umjesto bare ESP32-C6 RF implementacije:

**ESP32-C6-WROOM-1**

### Prednosti

Modul već integrira:

- ESP32-C6
- flash
- RF matching
- 40 MHz clock
- PCB antenu ili U.FL varijantu
- RF layout koji je već kvalificiran

Time se znatno smanjuje RF rizik nove PCB ploče.

### Obavezni PCB zahtjevi

- antenna keep-out
- bez bakra ispod PCB antene
- bez visokih metalnih dijelova uz antenu
- odgovarajući 3.3 V decoupling
- SDIO routing
- RESET
- eventualni UART za C6 debug

---

# 10. Display

Aktualna hardverski potvrđena konfiguracija je:

- 4.3"
- IPS TFT
- 480 × 800
- ST7701S
- MIPI DSI
- 2 data lane
- landscape UI kroz rotaciju

Tvoj UI je praktički projektiran za 800 × 480 landscape način rada.

## Preporuka

Zadržati isti ili potpuno kompatibilan LCD panel.

### Potrebna DSI sučelja

- DSI CLK+
- DSI CLK-
- DSI DATA0+
- DSI DATA0-
- DSI DATA1+
- DSI DATA1-

### Kontrolni signali

- LCD RESET
- backlight enable/PWM
- power rails

### Firmware pinovi

- GPIO5 — LCD reset
- GPIO23 — LCD backlight PWM

### Preporučene dodatne PCB komponente

- DSI_REXT ≈ 4.02 kΩ
- 0 Ω series/tuning footprints
- lokalni DSI PHY decoupling
- FPC connector
- kvalitetan ground reference
- vrlo kratke MIPI parice

---

# 11. LCD backlight driver

Guition ploča sadrži sklop za LCD backlight.

Na vlastitoj PCB ploči moramo ga ponovno implementirati.

### Kandidat

**MP3202** ili drugi LED boost driver koji odgovara točno odabranom panelu.

Sklop treba uključivati:

- boost IC
- inductor
- Schottky diode ako topologija zahtijeva
- current setting resistor
- input/output kondenzatore
- PWM/EN iz P4
- dovoljno visok voltage rating za LED string

Vrijednosti se ne smiju zaključati prije nego odaberemo konačni LCD panel i njegov backlight string.

---

# 12. Touch

Trenutni touch controller:

**GT911**

Trenutna komunikacija:

- I2C SDA — GPIO7
- I2C SCL — GPIO8
- adresa 0x5D

Za novu PCB preporučujem spojiti i dodatne signale:

- GT911 INT
- GT911 RESET

čak i ako ih sada firmware ne koristi.

To omogućuje:

- interrupt-driven touch
- hardware reset toucha
- lakši recovery
- manje I2C pollinga

### Potrebno

- SDA pull-up
- SCL pull-up
- ESD zaštita
- FPC konektor
- pravilna touch naponska domena

---

# 13. microSD

microSD treba ostati.

Ne služi kao glavni Rekordbox media uređaj, ali je važan za:

- controller profile
- config
- cache
- moguće logove
- pomoćne podatke
- future features

Trenutni mapping:

| Signal | GPIO |
|---|---:|
| D0 | 39 |
| D1 | 40 |
| D2 | 41 |
| D3 | 42 |
| CLK | 43 |
| CMD | 44 |

Koristi se 4-bit SDMMC.

## Preporučene dodatne komponente

- microSD socket
- ESD array
- pull-up na CMD
- pull-up na D0-D3
- series resistor footprint na CLK
- series resistor footprints i na drugim linijama ako SI test pokaže potrebu
- lokalni 100 nF
- bulk capacitor npr. 10–47 µF blizu socketa

## Preporučeno napajanje

microSD napajati iz glavnog 3.3 V raila.

Opcionalno dodati:

- high-side load switch ili P-MOSFET

kako bi firmware mogao fizički power-cycleati SD karticu.

---

# 14. PCM5102A MAIN audio DAC

PCM5102A je sada dokazani MAIN audio izlaz.

Aktualni pinovi:

| Funkcija | ESP32-P4 |
|---|---:|
| BCLK | GPIO50 |
| LRCK / WS | GPIO52 |
| DATA | GPIO51 |
| MCLK | nije potreban |

PCM5102A podržava 3-wire I2S jer ima interni PLL.

## Preporučeni IC

**PCM5102APWR**

TSSOP-20 kućište.

## Prednosti

- kvalitetan stereo DAC
- line-level output
- nema potrebe za dodatnim MCLK-om
- nema potrebe za zasebnim izlaznim op-ampom u osnovnoj konfiguraciji
- ground-centered output
- prikladan za RCA MAIN OUT

## Tipični pomoćni elementi

Prema TI referentnom dizajnu treba predvidjeti:

- lokalni 100 nF bypass
- bulk decoupling
- charge pump capacitor
- analog supply filtering
- digital supply filtering
- 470 Ω series R na OUTL
- 470 Ω series R na OUTR
- približno 2.2 nF RF filter C na L/R
- XSMT control
- FMT konfiguraciju
- FLT konfiguraciju

## Izlazi

### J4
RCA LEFT

### J5
RCA RIGHT

### J6 — removed from Rev A

The optional 3.5 mm stereo line output was removed in M1-MECH-A8. MAIN remains RCA L/R; CUE/headphones remain on the DDJ-FLX4 USB Audio path.

---

# 15. CUE / headphones audio

Važno: nova ploča **ne treba drugi DAC za headphones**.

CUE/PFL signal ide:

```text
P4 audio engine
      |
      +-> MAIN -> PCM5102A -> RCA
      |
      +-> CUE/MONITOR
             |
             -> USB Audio Class ch.3/4
                    |
                    -> DDJ-FLX4
                           |
                           -> FLX4 headphone jack
```

To smanjuje:

- broj DAC-ova
- analogne sklopove
- routing
- trošak
- potencijalne ground-loop probleme

---

# 16. Dual USB host

Ovo je najvažniji električni blok cijelog Pajoniiir Mainboarda.

Trenutna konfiguracija:

### USB0

Rekordbox storage.

### USB1

DDJ-FLX4:

- MIDI IN
- MIDI OUT
- LEDs
- UAC audio
- cue/headphones

USB podaci rade, ali na Guition prototipu VBUS napajanje ostaje glavni hardverski rizik.

---

# 17. Zašto USB VBUS mora biti potpuno nov

Na prototipu je potvrđeno da napajanje JC4880 preko JP1 VCC5V:

- napaja sam P4 board
- ali ne jamči ispravan downstream VBUS prema oba USB host porta

Kasniji bench setup uspio je napajati uređaje, ali je došlo do brownouta pod audio opterećenjem.

Zbog toga buduća PCB mora imati namjenski dual-VBUS power distribution.

---

# 18. Preporučena dual USB power arhitektura

```text
                         +---------------- USB0 VBUS
                         |
5V_SYS ── TPS25221 x2 ───────+
                         |
                         +---------------- USB1 VBUS
```

### U6

**TPS25221 x2**

Dual USB current-limited high-side switch.

Za svaki port:

- zaseban switch kanal
- zaseban current limit
- zaseban enable
- zaseban fault
- thermal protection
- short-circuit protection
- soft-start

## Preporučeni target

Približno:

- USB0: 0.8–1.0 A
- USB1: 0.8–1.0 A

Točan ILIM treba definirati prema:

- DDJ-FLX4 stvarnoj potrošnji
- USB stick peak currentu
- TPS25221 x2 datasheetu
- bench mjerenju

---

# 19. USB firmware-controlled power

Vrlo preporučljivo:

### EN1

P4 kontrolira USB0 VBUS.

### EN2

P4 kontrolira USB1 VBUS.

### FAULT1

P4 čita USB0 overcurrent/fault.

### FAULT2

P4 čita USB1 overcurrent/fault.

To omogućuje softwareu:

- isključiti samo USB stick
- power-cycleati USB0
- power-cycleati FLX4
- razlikovati overcurrent od USB enumeration problema
- prikazati fault u Settings UI
- napraviti automatski recovery bez resetiranja uređaja

Primjer budućeg dijagnostičkog ekrana:

```text
USB POWER

USB0 STORAGE   5.02 V   OK
USB1 FLX4      4.98 V   OK

USB0 FAULT     NO
USB1 FAULT     NO
```

---

# 20. USB konektori

Za Rev A preporučujem:

**USB-A host ×2**

umjesto dva USB-C host konektora.

## Razlog

USB-A host je električki i mehanički jednostavniji.

Nema potrebe za:

- CC1/CC2 konfiguracijom
- Type-C role detectionom
- source current advertisement logikom
- USB-C host role greškama

### USB0

USB-A ženski

za USB stick.

### USB1

USB-A ženski

prema DDJ-FLX4 preko:

**USB-A → USB-C data kabela**

Kasnije se može napraviti Type-C revizija ako bude potrebno.

---

# 21. USB signal integrity

Za svaki USB port treba predvidjeti:

- D+
- D-
- GND
- SHIELD
- VBUS iz TPS25221 x2

## FS USB

Za Full-Speed linije predvidjeti series resistor footprintove, tipično:

- 22 Ω
- 33 Ω

konačna vrijednost nakon SI testiranja.

## HS USB

Za High-Speed port:

- pravilna 90 Ω differential impedance
- kratke parice
- isti layer
- minimalan broj via
- kontinuiran GND plane
- low-capacitance ESD

ESD zaštita HS linija mora imati vrlo malu kapacitivnost, tipično <1 pF.

---

# 22. USB ESD zaštita

Za oba porta treba zaseban USB ESD array.

Kandidati klase:

- TPD2EUSB30
- USBLC6-2
- PESD5V
- ekvivalent za USB 2.0

Za HS port treba izabrati dio s dovoljno niskim Cpar.

---

# 23. Glavno napajanje

Predložena osnovna arhitektura:

```text
External regulated 5 V / 4 A
            |
           TVS
            |
        Input eFuse
            |
           5V_SYS
            |
     ┌──────┼───────────────┐
     │      │               │
     │      │               │
 TPS25221 x2   5→3.3V         LCD BL
 USB VBUS   BUCK            BOOST
            |
       ┌────┼──────┬──────────────┐
       │    │      │              │
      P4   C6    FLASH          PCM5102A
       │
  P4 core DCDC
```

---

# 24. Ulazni eFuse

Preporučeni kandidat:

**TPS25947**

ili ekvivalent.

Poželjne funkcije:

- overcurrent protection
- current limit
- short-circuit protection
- overvoltage protection
- reverse polarity/reverse current zaštita
- thermal shutdown
- controlled soft-start
- power-good

To je vrlo korisno jer uređaj ima:

- veliki P4
- MIPI LCD
- Wi-Fi
- audio DAC
- dva USB host uređaja
- SD karticu

---

# 25. Ulazna TVS zaštita

Na 5 V power input preporučujem TVS diodu.

Odabir ovisi o:

- vanjskom adapteru
- konektoru
- maksimalnom dopuštenom standoff naponu
- željenom IEC ESD/surge nivou

Treba dodati i:

- input bulk capacitor
- 100 nF ceramic
- eventualni π filter

---

# 26. 5 V → 3.3 V regulator

Glavni 3.3 V regulator mora biti sinkroni buck.

Ne preporučujem linearni regulator.

Razlog:

- ESP32-P4
- C6
- flash
- microSD
- touch
- digitalni DAC dio
- ostala logika

mogu stvoriti značajnu potrošnju.

### Minimalni target

3.3 V / 2 A

### Preporučeni design target

3.3 V / 3 A

radi rezerve.

Kandidati klase:

- TPS62132
- TPS62132
- MP2145
- SY8089
- drugi kvalitetan synchronous buck

Konačni dio treba odabrati prema:

- cijeni
- dostupnosti
- efikasnosti
- EMI-u
- layout zahtjevima

---

# 27. Power budget

Repo trenutačno predviđa približno:

- do ~1 A USB0
- do ~1 A USB1
- P4 + LCD + Wi-Fi + SD + audio ostatak

Zato:

### Minimum

5 V / 3 A

### Preporučeni design input

**5 V / 4 A**

To daje korisnu rezervu za:

- FLX4 startup
- USB stick peak
- LCD backlight
- Wi-Fi TX burst
- SD current transient
- audio processing

PCB power routing treba projektirati tako da 4 A nije problem.

---

# 28. Napajanje kao topologija zvijezde

Preporučuje se od `5V_SYS` razdvojiti glavne grane:

```text
5V_SYS
 |
 +-- P4/3V3 converter
 |
 +-- USB TPS25221 x2
 |
 +-- LCD backlight
 |
 +-- audio analog filter
```

Treba izbjeći da USB load transient prolazi istom tankom stazom kao P4 napajanje.

To je posebno važno jer je prototip već pokazao brownout ponašanje.

---

# 29. Opcionalni power monitor

Vrlo korisna EVT/DVT komponenta:

**INA226 / INA238 / sličan current monitor**

Mjerio bi:

- 5V_SYS voltage
- total current
- power

Time firmware može logirati:

- USB hotplug peak
- FLX4 startup
- dual-deck load
- Wi-Fi burst
- backlight load

Primjer:

```text
SYSTEM POWER

5V_SYS       4.98 V
CURRENT      1.74 A
POWER        8.67 W

USB0         OK
USB1         OK
```

Ovo nije nužno za finalnu masovnu proizvodnju, ali je vrlo korisno za Rev A.

---

# 30. Debug / programiranje

Ploča mora biti lako servisabilna.

Preporučujem footprint za:

### UART0

- TX
- RX
- GND
- 3V3
- CHIP_PU
- BOOT

Format može biti:

- 1×6 2.54 mm
- 1.27 mm header
- Tag-Connect
- pogo pads

Za proizvodnju je najbolji pogo/Tag-Connect pristup.

---

# 31. Status LED

Preporučujem najmanje jednu P4 status LED.

Moguće namjene:

- boot
- firmware update
- fault
- USB recovery
- diagnostics

Može biti:

- jedna RGB LED
- ili dvije obične LED

Za finalni proizvod LED može biti skrivena unutra ako nije potrebna korisniku.

---

# 32. Reset supervisor

Nije nužno, ali ostaviti footprint nije loša ideja.

Ako se tijekom DVT testiranja pokaže da power-up sequence treba dodatnu kontrolu, može se koristiti supervisor IC.

Primjeri klase:

- TPS3808
- TLV803
- STM809

Za prvu reviziju može biti DNP.

---

# 33. Što NE treba prenijeti s JC4880 ploče

Sljedeće komponente postoje na universal development boardu, ali nisu potrebne u aktivnoj Pajoniiir arhitekturi.

## ESP32-S3

**Izbaciti.**

P4 sada direktno upravlja FLX4.

## ES8311 codec

**Izbaciti.**

MAIN ide preko PCM5102A.

Cue ide preko FLX4 UAC.

## Speaker amplifier

**Izbaciti.**

Nema potrebe za lokalnim speaker outputom.

## Speaker connector

**Izbaciti.**

## Analog microphone circuitry

**Izbaciti.**

## Camera MIPI CSI

**Izbaciti.**

## Camera power/control

**Izbaciti.**

## RS485/MAX485

**Izbaciti.**

## P4-S3 UART control link

**Izbaciti.**

## P4-S3 monitor I2S

**Izbaciti.**

## Battery charger / lithium circuit

Za prvu Pajoniiir PCB reviziju:

**izbaciti**, osim ako se kasnije donese odluka da uređaj mora raditi na bateriju.

## Veliki universal GPIO expansion header

Nije potreban.

Bolje koristiti:

- test pads
- mali debug header
- nekoliko rezervnih GPIO padova

---

# 34. Komponente koje treba zadržati funkcionalno, ali ne nužno identično

S Guition koncepta ostaju potrebni:

- ESP32-P4
- 32 MB PSRAM
- 16 MB flash
- ESP32-C6 Wi-Fi
- LCD
- touch
- microSD
- 5 V napajanje
- 3.3 V napajanje
- USB host
- debug UART

Ali nova PCB treba koristiti komponente i layout prilagođene Pajoniiiru.

---

# 35. Preliminarni glavni Engineering BOM

Ovo nije još finalni manufacturing BOM, nego početni popis glavnih komponenti.

| RefDes | Qty | Funkcija | Preporučeni dio / klasa | Status |
|---|---:|---|---|---|
| U1 | 1 | Main SoC | ESP32-P4NRW32X | obavezno |
| U2 | 1 | Flash | 16 MB QSPI NOR | obavezno |
| Y1 | 1 | P4 clock | 40 MHz crystal, ±10 ppm | obavezno |
| U3 | 1 | P4 core DCDC | TLV62569 class | obavezno |
| L1 | 1 | P4 DCDC inductor | prema P4 ref designu | obavezno |
| U4 | 1 | Wireless | ESP32-C6-WROOM-1 | obavezno za Wi-Fi |
| U5 | 1 | MAIN DAC | PCM5102APWR | obavezno |
| U6 | 1 | Dual USB VBUS (Rev A: 2× TPS25221) | TPS25221 x2 | obavezno |
| U7 | 1 | Input eFuse | TPS25947 class | preporučeno |
| U8 | 1 | 3.3 V buck | 2–3 A synchronous buck | obavezno |
| U9 | 1 | LCD backlight | MP3202 class | obavezno |
| U10 | 0/1 | Touch | GT911 | ovisi o modulu |
| DS1 | 1 | Display | 4.3" 480x800 ST7701S | obavezno |
| J1 | 1 | microSD | socket | obavezno |
| J2 | 1 | USB0 | USB-A host | obavezno |
| J3 | 1 | USB1 | USB-A host | obavezno |
| J4 | 1 | MAIN L | RCA | obavezno |
| J5 | 1 | MAIN R | RCA | obavezno |
| J6 | 0 | Stereo line out | removed M1-MECH-A8 | not on Rev A PCB |
| J7 | 1 | 5 V input | locking DC connector | obavezno |
| SW1 | 1 | Reset | tactile | obavezno |
| SW2 | 1 | Boot | tactile | obavezno |
| D1 | 1 | Input TVS | 5 V rail class | preporučeno |
| D2 | 1 | USB0 ESD | USB 2.0 low-C | obavezno |
| D3 | 1 | USB1 ESD | USB 2.0 low-C | obavezno |
| U11 | 0/1 | Power monitor | INA226/INA238 | EVT opcija |
| LED1 | 1 | Status | LED ili RGB | preporučeno |
| TPx | više | Test points | power/data/debug | obavezno za Rev A |

---

# 36. Pasivni sklopovi koje će finalni BOM morati sadržavati

Finalni BOM mora eksplicitno uključiti:

## ESP32-P4

- sve decoupling kondenzatore
- core regulator passives
- crystal load C
- reset R/C
- boot pull-up/down
- flash pull-up
- flash tuning resistors
- DSI reference resistor

## USB

- 2× current-limit R
- 2× EN pull-down
- 2× FAULT pull-up
- 2× VBUS bulk C
- 2× ESD array
- FS series R
- HS optional tuning R

## PCM5102A

- 470 Ω ×2
- 2.2 nF ×2
- 100 nF bypass više komada
- bulk C
- charge-pump C
- mode strap resistors

## microSD

- CMD pull-up
- D0–D3 pull-up
- CLK series R
- local bulk C
- ESD

## touch

- SDA pull-up
- SCL pull-up
- RESET pull
- INT pull

## C6

- power decoupling
- EN/reset
- SDIO tuning/pull-up komponente

---

# 37. Audio PCB layout pravila

PCM5102A treba staviti blizu RCA konektora.

Preporučeni tok:

```text
P4
 |
 | I2S digital
 |
PCM5102A
 |
 | analog L/R
 |
RF filter
 |
RCA L / RCA R
```

Digitalne I2S linije ne treba provlačiti paralelno uz analogne izlaze.

Treba:

- odvojiti noisy buck switching node
- držati backlight boost dalje od PCM5102A
- držati USB HS dalje od analognog audio dijela
- koristiti solid GND plane
- pravilno rasporediti analogni i digitalni povrat

Ne preporučuje se rezati GND plane ispod DAC-a bez dobrog razloga.

---
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

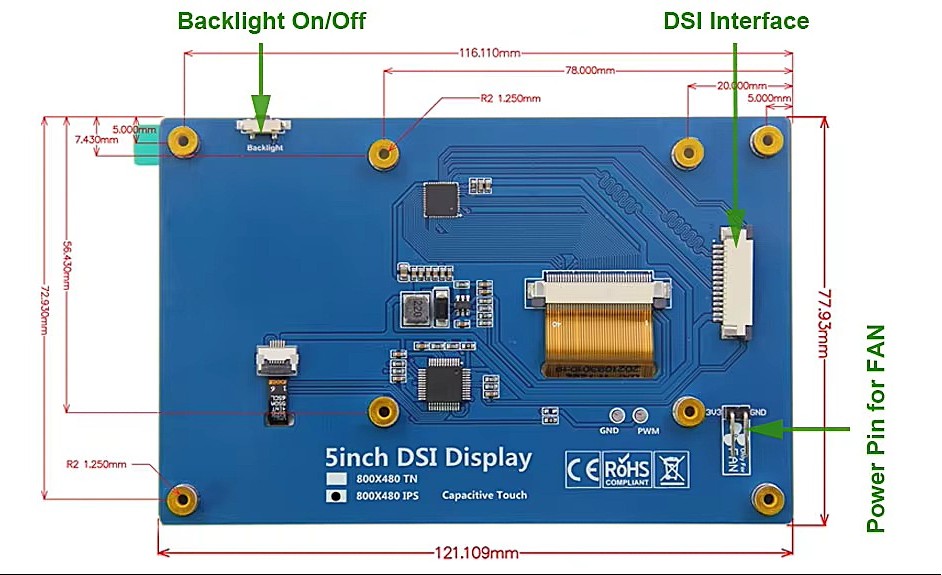
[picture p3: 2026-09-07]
hardware/Pajoniiir-M1/evidence/dsi506_rear_dimensioned_reference.jpg

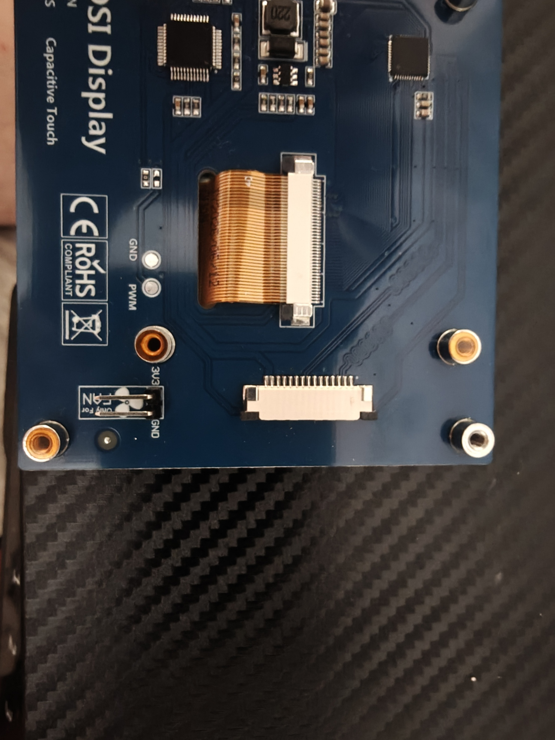
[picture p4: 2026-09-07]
hardware/Pajoniiir-M1/evidence/dsi506_actual_rear_connector_context.png

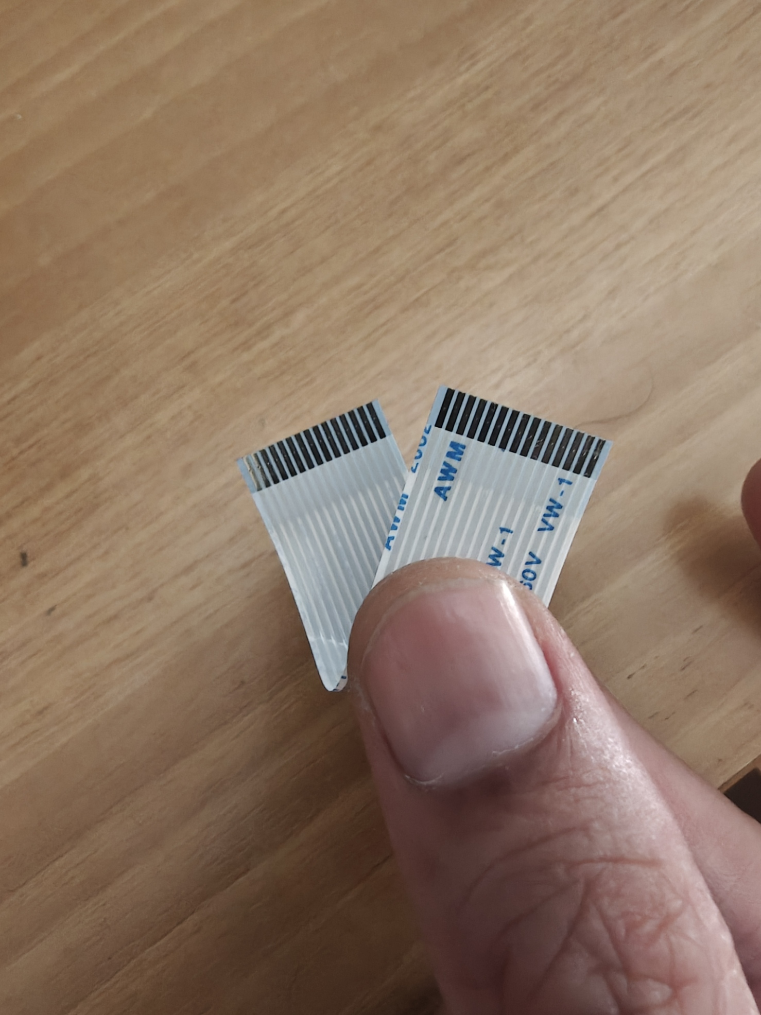
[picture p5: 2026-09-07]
hardware/Pajoniiir-M1/evidence/dsi506_ffc_both_ends.png

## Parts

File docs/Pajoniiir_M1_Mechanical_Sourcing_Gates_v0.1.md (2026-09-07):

# Pajoniiir-M1 — Mechanical and Sourcing Gates v0.3

**Updated:** 2026-09-06
**Mechanical milestone:** M1-MECH-B7
**Status:** board-first authority locked; layout freeze blocked
**Machine authority:** `hardware/Pajoniiir-M1/mechanical_gates.json`

## Current conclusion

The mainboard is the mechanical authority. No display model defines its outline, mounting pattern, connector walls or Z stack. DSI506 geometry and the former B2-B6 direct-mount studies are historical profile evidence only.

```text
layout_freeze_allowed  false
open blockers          12
closed gates           4
blank BOM gates        3
```

Most external connector MPNs and footprints are selected, but panel centers and board placement remain open. The final board envelope must come from complete component packing, critical-route feasibility, thermal/height zoning, connector service access and an independent chassis mount.

## Closed gates

| Gate | Closure |
|---|---|
| `D1_INPUT_TVS` | SMBJ6.0CA-TR / `Diode_SMD:D_SMB` |
| `J6_LINE35` | optional 3.5 mm line output removed from Rev A |
| `J9_USB_SERVICE_POGO` | project-local 1x05 factory pogo footprint, DNL |
| `FAB_STACKUP` | JLCPCB JLC04161H-7628, four layers, 1.6 mm |

## Open component and connector gates

### C3 and C8

The current 330 uF values are tuning baselines. Startup/inrush and worst-case rail transient tests must establish capacitance, ESR and ripple-current targets. The board-first placement study must establish the available package and height envelope.

### J1 power input

Switchcraft 722RAHLP with S760KHZ mating plug is the selected production intent. The footprint stays blank until the terminal centers are resolved without inference. Closure also needs board-edge placement, panel engagement, reinforcement, polarity marking and the full mated cable/strain envelope.

### J2/J3 USB, J4/J5 RCA, J7 microSD and SW1/SW2

Exact part and footprint intent is retained. Each gate remains open for board-local placement, chassis cutout, full mated/user-access envelope and local routing/courtyard clearance. No former B3 wall assignment or B5 anchor is production authority.

### J6 DSI host

J6 is a generic 15-pin Raspberry-Pi-style MIPI DSI host. Amphenol SFW15R-2STE1LF and its project footprint are locked. Clock, lane 0, lane 1, display I2C and `3V3_DISPLAY_MODULE` are captured.

Closure requires:

1. service-accessible board-edge placement with a viable U1-to-J6 MIPI route;
2. generic insertion/removal clearance in the board chassis;
3. startup/transient power budget for the supported display matrix;
4. a cable or adapter orientation record for every supported display profile.

DSI506 Type-B cable and rear-board geometry belong only to its compatibility profile.

### PCB outline

Closure requires:

- complete footprint/courtyard packing;
- a board-owned chassis mounting pattern and edge clearances;
- power, USB, MIPI, SDIO, QSPI and audio routing feasibility;
- thermal and component-height zones;
- external connector cutouts and full mated cable/service envelopes;
- manufacturing panelization and assembly review.

## Freeze rule

Final placement/routing freeze is allowed only after all 12 blocking gates close and exact 90 ohm USB / 100 ohm MIPI geometry is recorded for the locked stackup. Until then, no final `Edge.Cuts`, Gerber or EVT order may be described as release-ready.

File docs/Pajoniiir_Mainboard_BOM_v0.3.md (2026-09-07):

# Pajoniiir Mainboard — Engineering BOM v0.3

**Project:** Pajoniiir-M1 Rev A

**Updated:** 2026-09-04

**Baseline:** M1-ELEC-B2 / M1-MECH-B7

**Status:** current engineering-intent BOM companion to the live KiCad hierarchy

This document records current component intent and unresolved production choices. It is not a manufacturing BOM. The manufacturing candidate must be exported from `hardware/Pajoniiir-M1/Pajoniiir-M1.kicad_sch` and checked with `validate_manufacturing_outputs.py`.

## Current source baseline

| Metric | Count |
|---|---:|
| Unique `in_bom=yes` RefDes | 244 |
| DNP RefDes | 15 |
| Intentional blank footprints | 3 |
| Instantiated RefDes including DNL service items | 247 |

Intentional blank footprints are `C3`, `C8` and `J1`. Any additional blank footprint is a validation failure.

Current DNP set:

```text
C24 C72 C76 C77 C78 C79 C80 C106 C107 C108 C109 R70 R74 R99 R100
```

## System baseline

- Main compute: ESP32-P4NRW32X, production target silicon v3.2 or newer approved revision
- Firmware storage: W25Q128JVPIQ, 16 MB external QSPI flash
- Wi-Fi: ESP32-C6-WROOM-1-N4 over four-bit SDIO
- MAIN audio: PCM5102APWR stereo DAC
- Display interface: generic 15-pin Raspberry-Pi-style MIPI DSI host; DSI506/DYL0023 is one validated profile
- Touch/backlight: supplied by the selected display profile over shared display I2C where supported
- Storage: USB0 High-Speed host plus native four-bit microSD
- Controller/audio host: USB1 Full-Speed DDJ-FLX4 MIDI and four-channel USB Audio
- CUE/PFL: DDJ-FLX4 USB Audio/headphone path

The former ST7701S/GT911/MP3202 bare-panel path and optional 3.5 mm line output are not part of the active Rev A BOM.

## Critical ICs and modules

| RefDes | Qty | Function | MPN/value | Footprint | State |
|---|---:|---|---|---|---|
| U1 | 1 | Main MCU + 32 MB PSRAM | ESP32-P4NRW32X | `Pajoniiir-M1:ESP32-P4` | locked for schematic; verify production revision/lot |
| U2 | 1 | 16 MB QSPI flash | W25Q128JVPIQ | `Package_SON:WSON-8-1EP_6x5mm_P1.27mm_EP3.4x4.3mm` | captured |
| U3 | 1 | P4 VDD_HP regulator | TLV62569DRLR | `Package_TO_SOT_SMD:SOT-563` | captured |
| U4 | 1 | Wi-Fi coprocessor | ESP32-C6-WROOM-1-N4 | `Pajoniiir-M1:ESP32-C6-WROOM-1` | captured; RF placement still required |
| U5 | 1 | MAIN stereo DAC | PCM5102APWR | `Package_SO:TSSOP-20_4.4x6.5mm_P0.65mm` | captured |
| U6/U12 | 2 | USB0/USB1 VBUS switches | TPS25221DRVR | `Package_SON:WSON-6-1EP_2x2mm_P0.65mm_EP1x1.6mm` | captured |
| U7 | 1 | Input eFuse | TPS259474ARPWR | `Pajoniiir-M1:Texas_RPW0010A_VQFN-HR-10_2x2mm` | land pattern locked |
| U8 | 1 | 3.3 V / 3 A system buck | TPS62132RGTR | `Package_DFN_QFN:VQFN-16-1EP_3x3mm_P0.5mm_EP1.68x1.68mm_ThermalVias` | captured |
| U13 | 1 | microSD load switch | TPS22918DBVR | `Package_TO_SOT_SMD:SOT-23-6` | captured |
| U14 | 1 | System power monitor | INA238AIDGSR | `Pajoniiir-M1:Texas_DGS0010A_VSSOP-10_3x3mm_P0.5mm` | captured for EVT/DVT telemetry |

## Power and monitoring

Input path:

```text
J1 -> D1/input capacitance -> U7 TPS259474A -> 5V_PROTECTED
   -> R120 5 mOhm Kelvin shunt -> 5V_SYS
```

| RefDes | Function | Value/MPN | Footprint/state |
|---|---|---|---|
| J1 | Locking 5 V input | Switchcraft 722RAHLP; S760KHZ mating plug | MPN locked; footprint intentionally blank |
| D1 | Input TVS | SMBJ6.0CA-TR | `Diode_SMD:D_SMB`, locked |
| C3 | Input bulk | 330 uF tuning baseline | exact MPN/package blocked by EVT |
| C8 | Protected-rail bulk | 330 uF tuning baseline | exact MPN/package blocked by EVT |
| U7 | eFuse | TPS259474ARPWR | project HotRod RPW0010A footprint locked |
| R120 | System current shunt | WSK25125L000FEA, 5 mOhm, 1%, 1 W, four-terminal | Vishay WSK2512 Kelvin footprint |
| U14 | Current/voltage monitor | INA238AIDGSR, address 0x40 | captured |
| U8 | 3.3 V buck | TPS62132RGTR | captured |
| TP25 | eFuse PG diagnostic | EFUSE_PG | TestPoint:TestPoint_Pad_D1.5mm |
| TP26 | 3.3 V PG diagnostic | 3V3_PG | TestPoint:TestPoint_Pad_D1.5mm |
| L2 | 3.3 V buck inductor | XGL4030-222MEC, 2.2 uH | `Inductor_SMD:L_Coilcraft_XxL4030` |

Initial eFuse targets remain UVLO about 4.42 V, OVLO about 5.70 V and current limit about 4.45 A typical. C3/C8 require startup, inrush, transient, ESR, ripple-current and physical-envelope evidence before production lock.

## P4, flash and clock

| RefDes | Function | Value/MPN |
|---|---|---|
| U1 | ESP32-P4 | ESP32-P4NRW32X |
| U2 | QSPI flash | W25Q128JVPIQ |
| Y1 | Main crystal | ECS-400-10-37B2-CKY-TR, 40 MHz, +/-10 ppm |
| U3 | P4 core regulator | TLV62569DRLR |
| R27/R28/C42 | P4 v3.x feedback network | 499 k / 499 k / 22 pF |
| R24 | DSI_REXT | 4.02 k, 1% |

P4 physical package pin 54 is `VDD_HP_1`; it must not be confused with GPIO54. M1 requires a separate v3.x firmware target and must not use a pre-v3 binary.

## C6 Wi-Fi

| Item | Baseline |
|---|---|
| Module | ESP32-C6-WROOM-1-N4 |
| Power | `3V3_C6`, 100 nF + 10 uF + 22 uF |
| Reset | P4 GPIO54 through 0 ohm to C6 EN, 10 k pull-up + 1 uF |
| SDIO | P4 GPIO14..19, four-bit bus |
| Pull-ups | 51.1 k on CMD and D0..D3 |
| Series | 22 ohm clock; 0 ohm CMD/data tuning |

The module antenna requires an edge placement and all-layer keepout. WROOM-1U remains a fallback only if enclosure/RF validation requires an external antenna.

## USB

| RefDes | Function | MPN/value | Footprint/state |
|---|---|---|---|
| U6 | USB0 VBUS switch | TPS25221DRVR, 54.9 k RILIM, about 1.0 A | captured |
| U12 | USB1 VBUS switch | TPS25221DRVR, 34.8 k RILIM, about 1.6 A initial | captured |
| D2/D3 | USB data ESD | TPD2EUSB30ADRTR | `Package_TO_SOT_SMD:Texas_DRT-3` |
| J2/J3 | USB 2.0 Type-A host | Amphenol 87520-1010ALF | project footprint locked |

USB0 uses the dedicated P4 High-Speed PHY with 0 ohm inline tuning. USB1 uses GPIO26/27 Full-Speed with 22 ohm source series. GPIO24/25 remain reserved for P4 USB Serial/JTAG service.

Connector panel centers, cutouts, insertion clearance and mated cable envelopes remain open mechanical gates.

## MAIN audio

| RefDes | Function | MPN/value | Footprint/state |
|---|---|---|---|
| U5 | Stereo DAC | PCM5102APWR | TSSOP-20 |
| J4 | MAIN L | Kycon KLPX-0848A-2-W-G | project RCA footprint locked |
| J5 | MAIN R | Kycon KLPX-0848A-2-R-G | project RCA footprint locked |
| R80/C91 | Left output filter | 470 ohm / 2.2 nF C0G | captured |
| R81/C92 | Right output filter | 470 ohm / 2.2 nF C0G | captured |

GPIO50 is BCLK, GPIO51 DATA, GPIO52 LRCK and GPIO49 XSMT. The DAC boots muted. The retired 3.5 mm line-output connector has no Rev A footprint.

## DSI host interface

| RefDes | Function | MPN/value | Footprint/state |
|---|---|---|---|
| J6 | 15-pin DSI host connector | Amphenol SFW15R-2STE1LF | project footprint locked and instantiated |
| FB3 | Display module power isolation | 0 ohm / ferrite option | 0603 |
| C93/C94 | Local display supply | 100 nF / 10 uF | captured |
| R82..R87 | Six inline DSI tuning links | 0 ohm | 0201 |
| R95/R96 | Display I2C series | 22 ohm | 0402 |
| R97/R98 | Display I2C pull-ups | 4.7 k | 0603 |
| R99/R100 | Parallel I2C pull-up options | 4.7 k DNP | 0603 |

J6 pin map:

```text
1 GND       2 DSI_D1_N   3 DSI_D1_P   4 GND
5 DSI_CLK_N 6 DSI_CLK_P  7 GND        8 DSI_D0_N
9 DSI_D0_P 10 GND       11 I2C_SCL   12 I2C_SDA
13 GND     14 3V3       15 3V3
```

The remaining J6 gate covers board-edge placement, branch power budget, service access and a cable/adapter orientation record for each supported display. DSI506 is the first validated profile. There is no discrete MP3202 backlight block or GT911 reset/interrupt network in the active BOM.

## microSD

| RefDes | Function | MPN/value | Footprint/state |
|---|---|---|---|
| U13 | Card power switch | TPS22918DBVR | SOT-23-6 |
| J7 | Push-push microSD socket | Molex 503398-1892 | project footprint locked |
| C103/R105 | CT/QOD | 470 pF / 100 ohm | captured |
| R109 | SD clock series | 22 ohm | captured |
| R112..R116 | Bus pull-ups | 10 k to switched `3V3_SD` | captured |

The panel slot, card insertion/ejection/finger envelope, lower-right screw clearance and FFC coexistence remain open.

## Recovery and service

- SW1/SW2: B3U-3000P-B with exact standard KiCad footprint; panel tool-hole placement remains open.
- J8/J10: P4/C6 Tag-Connect pads, DNL.
- J9: project-local 1x05 USB Serial/JTAG factory pogo, DNL, closed sourcing/footprint gate.
- Factory fixtures must sense VREF only and must power the board through the qualified 5 V input path.

## Production choices still open

The following are not production BOM locks:

1. J1 exact land pattern
2. C3 and C8 exact capacitance technology, MPN and footprint
3. final mounting-hole diameter and screw head/washer hardware
4. panel cutouts and absolute connector centers
5. board-edge J6 service placement, power budget and per-display cable/adapter profiles
6. final PCB side wings/notches and `Edge.Cuts`
7. exact 90 ohm USB and 100 ohm MIPI width/spacing

Use `mechanical_gates.json` for the complete closure evidence and current layout-freeze state.

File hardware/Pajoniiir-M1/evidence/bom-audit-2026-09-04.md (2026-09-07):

# Pajoniiir-M1 manufacturing BOM audit

- Source `in_bom=yes` RefDes: **244**
- KiCad BOM RefDes: **244**
- Source DNP RefDes: **15**
- Intentional blank-footprint BOM gates: **3**
- Result: **PASS**

## Intentional blank-footprint gates

- `C3`
- `C8`
- `J1`

## DNP RefDes

- `C106`
- `C107`
- `C108`
- `C109`
- `C24`
- `C72`
- `C76`
- `C77`
- `C78`
- `C79`
- `C80`
- `R100`
- `R70`
- `R74`
- `R99`

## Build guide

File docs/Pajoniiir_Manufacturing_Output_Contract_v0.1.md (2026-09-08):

# Pajoniiir-M1 — Manufacturing Output Contract v0.2

**Milestone:** M1-ELEC-B2 / M1-MECH-B7

**Updated:** 2026-09-04

**Status:** CI-enforced manufacturing-output baseline

## Authority

Engineering BOM documents describe intent. The manufacturing candidate is exported directly from the root KiCad hierarchy:

```text
hardware/Pajoniiir-M1/Pajoniiir-M1.kicad_sch
```

The current source-derived baseline is:

| Metric | Current value |
|---|---:|
| Unique `in_bom=yes` RefDes | 244 |
| DNP RefDes | 15 |
| Intentional blank-footprint gates | 3 |
| Blank-footprint RefDes | `C3`, `C8`, `J1` |

These counts are snapshots. CI derives the expected set from the 15 leaf schematics and compares it with the KiCad-generated BOM.

## CI outputs

Relevant schematic/library/tool changes produce:

```text
Pajoniiir-M1-manufacturing-bom.csv
Pajoniiir-M1-manufacturing-bom-audit.md
Pajoniiir-M1.net.xml
Pajoniiir-M1-schematic.pdf
Pajoniiir-M1-erc.json
```

The bundle is uploaded as the GitHub Actions artifact `Pajoniiir-M1-M1-SCH-A`.

## Enforced checks

`validate_manufacturing_outputs.py` fails when:

- a source `in_bom=yes` RefDes is missing from the exported BOM
- KiCad exports an unexpected RefDes
- Value or Footprint differs between source and export
- a new blank footprint appears outside the gate allowlist
- an allowlisted blank footprint becomes populated without removing the stale allowlist entry
- a manufacturing RefDes does not end with a numeric suffix

This is separate from ERC. ERC checks electrical consistency; BOM parity checks hierarchy loading and assembly database integrity.

## Current blank-footprint gates

```text
C3  input bulk capacitor; exact MPN/package waits for startup/inrush/transient EVT
C8  protected-rail bulk capacitor; exact MPN/package waits for transient EVT
J1  Switchcraft 722RAHLP; land pattern waits for unambiguous terminal-center evidence
```

J2/J3, J4/J5, J6, J7 and SW1/SW2 now have exact footprints. Their mechanical gates remain open for panel datums, cutouts, mating envelopes or local clearance, but they are no longer blank-footprint manufacturing gates.

J8/J9/J10 service interfaces are DNL/`in_bom=no` and do not appear in the manufacturing BOM.

## Current DNP set

The current 15 DNP RefDes are:

```text
C24 C72 C76 C77 C78 C79 C80 C106 C107 C108 C109 R70 R74 R99 R100
```

DNP entries remain visible in the exported assembly data so EVT tuning choices are explicit.

## Latest verified result

The historical KiCad 9 CI run covering the B5 schematic state reported:

```text
all 16 schematic files load: PASS
manufacturing BOM parity: source=242 bom=242 dnp=15 blank_gates=3 PASS
native ERC: unexplained_errors=0 excluded_errors=0 warnings=0
```

Current KiCad 10.0.4 verification after TP25/TP26 and library closure: **244 source / 244 exported, 15 DNP, 3 blank gates; zero native ERC violations**. The KiCad 9 result above is retained only as historical evidence. KiCad 10 is the sole current CI/ECAD toolchain. See [closure evidence](Pajoniiir_M1_ERC_Library_Closure_2026-09-04.md).

Historical run #76 reported 270/270, 17 DNP and 12 blank gates before the J6 audio removal, D1 lock, DSI506 migration and B4 footprint locks. Those numbers are retained only as historical evidence and are not the current baseline.

## Sign-off interpretation

Passing the workflow proves:

1. structural schematic contracts pass
2. every schematic loads under native KiCad 10
3. native ERC has no unexplained errors or warnings
4. KiCad exports the manufacturing BOM
5. exported RefDes/Value/Footprint data match the source hierarchy
6. KiCad exports the hierarchy netlist
7. KiCad generates the complete schematic PDF

It does not authorize PCB fabrication. Final manufacturing sign-off still requires closure of all layout-blocking mechanical/EVT gates, final `Edge.Cuts`, production impedance rules, PCB DRC and fabrication-output review.

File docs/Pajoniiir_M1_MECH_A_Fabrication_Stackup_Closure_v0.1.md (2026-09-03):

# Pajoniiir-M1 — M1-MECH-A Fabrication Stackup Closure v0.1

**Datum:** 2026-09-03  
**Revision:** M1-MECH-A11  
**Status:** FAB_STACKUP gate CLOSED; exact routed width/spacing remains pre-routing controlled-impedance work

## Decision

Rev A fabrication baseline is now:

```text
Fabricator       JLCPCB
Stackup          JLC04161H-7628
Layer count      4
Finished PCB     1.6 mm
Outer copper     1 oz
Inner copper     0.5 oz
L1 -> L2         7628 prepreg, 0.2104 mm, Er 4.4
L2 -> L3         FR-4 core, 1.065 mm, Er 4.6
L3 -> L4         7628 prepreg, 0.2104 mm, Er 4.4
```

Layer use:

```text
L1 / F.Cu   components + primary USB/MIPI/high-speed signals
L2 / In1    uninterrupted GND reference plane
L3 / In2    power distribution + low-speed where appropriate
L4 / B.Cu   secondary signals/components
```

Primary USB/MIPI routing is intentionally kept on L1 referenced directly to the solid L2 ground plane. High-speed traces must not use L3 as a split-power reference.

## Controlled impedance

Targets are locked:

```text
USB0 HS       90 ohm differential ±10%
USB1 FS       90 ohm differential ±10%
MIPI DSI     100 ohm differential ±10%
```

JLCPCB currently publishes controlled-impedance support on 4-layer boards and standard ±10% impedance tolerance. Its current stackup table explicitly lists `JLC04161H-7628`, and a 2026 JLCPCB case study uses that exact 4-layer / 1.6 mm stackup for 90-ohm USB and 100-ohm PCIe/MIPI DSI targets.

## Why exact width/gap is not frozen in A11

A stackup selection and a routed impedance geometry are different freeze points.

JLCPCB's current impedance calculator accepts the selected stackup, layer, target impedance and pair spacing, then derives the trace width. Manufacturing compensation can also affect the final artwork width. Therefore A11 does **not** invent a width/gap pair from a generic FR-4 formula.

Before `controlled_impedance_locked` becomes true, the layout must record the current JLCPCB calculator result for this exact stackup for:

- USB 90 ohm differential,
- MIPI DSI 100 ohm differential,
- any high-speed path that changes layer/reference geometry.

Changing the stackup from `JLC04161H-7628` requires a fresh impedance calculation.

## Gate result

`FAB_STACKUP` no longer blocks M1-MECH-A. `controlled_impedance_locked` deliberately remains `false`; this prevents stackup selection from being mistaken for completed PCB routing sign-off.

## Sources

- JLCPCB controlled-impedance stackups: https://jlcpcb.com/impedance
- JLCPCB impedance calculator guide: https://jlcpcb.com/help/article/user-guide-to-the-jlcpcb-impedance-calculator
- JLCPCB PCB capabilities: https://jlcpcb.com/capabilities/pcb-ca-
- JLCPCB 2026 controlled-impedance case study: https://jlcpcb.com/blog/pibrick-cm5-jlcpcb-case-study

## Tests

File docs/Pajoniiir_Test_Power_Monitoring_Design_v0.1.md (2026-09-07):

# Pajoniiir Mainboard — Test & Power Monitoring Design v0.1

**Projekt:** Pajoniiir BL-A1800 / Pajoniiir-M1
**Ploča:** Pajoniiir Mainboard Rev A
**Blok:** 14_TEST_MONITORING
**Datum:** 2026-09-02
**Status:** Captured in KiCad; telemetry is present for EVT/DVT validation

> **Post-capture update (2026-09-06):** INA238 is captured on the shared `DISPLAY_I2C_SDA/SCL` bus. DSI506 uses devices at `0x38` and `0x45`; other qualified display profiles must document their own addresses and coexistence. References below to GT911 describe historical shared-bus analysis.

---

# 1. Cilj

Pajoniiir je već pokazao da USB hotplug i load transients mogu izazvati brownout na development-board power topologiji.

Zato Rev A treba imati dovoljno mjernih točaka da možemo objektivno razlikovati:

- input adapter problem
- main eFuse trip
- 5V_SYS droop
- 3V3_SYS droop
- USB0/USB1 inrush
- Wi-Fi burst
- SD inrush
- backlight load
- P4 core instability

Rev A zato dobiva opcionalnu digitalnu 5V_SYS telemetriju.

---

# 2. Optional power monitor

Primary candidate:

**INA238AIDGSR**

Status:

**ACTIVE**

Relevantno:

- 16-bit ADC
- I2C
- shunt current measurement
- bus voltage measurement
- calculated power
- ALERT output
- 2.7–5.5 V device supply
- 16 selectable addresses
- high-side sensing

Rev A:

**DNP-CAPABLE**

Footprint i shunt se projektiraju, ali monitor se može izostaviti u cost-down BOM-u nakon DVT-a.

---

# 3. Measurement location

INA238 mjeri glavni protected 5 V rail nakon eFusea, prije grananja na potrošače.

~~~text
TPS259474A
    |
5V_PROTECTED
    |
 R_SHUNT
    |
5V_SYS
    |
    +-- 3V3 buck
    +-- USB0
    +-- USB1
    +-- backlight
~~~

Time mjerimo ukupnu stvarnu potrošnju uređaja.

---

# 4. Shunt resistor

Rev A:

**R_SYS_SHUNT = Vishay WSK25125L000FEA — 5 mΩ, 1%, 1 W, 4-terminal/Kelvin**

Pri 4.5 A:

~~~text
Vshunt = 4.5 A × 0.005 Ω
       = 22.5 mV

P = I²R
  = 4.5² × 0.005
  ≈ 101 mW
~~~

To daje veliku thermal marginu i mali voltage drop.

Uz INA238 ±40.96 mV range:

~~~text
IFS ≈ 40.96 mV / 5 mΩ
    ≈ 8.19 A
~~~

što je dobar mjerni raspon za Pajoniiir.

---

# 5. Kelvin sensing

Shunt mora imati:

- high-current pads/traces
- zasebne thin Kelvin sense traceove s unutarnje strane shunt padova
- IN+ i IN− se ne smiju spojiti na udaljene high-current net nodeove

Layout:

~~~text
power trace ==== [ RSHUNT ] ==== power trace
                  |      |
               Kelvin+ Kelvin-
                  |      |
                 INA238
~~~

Bez shared copper dropa u sense pathu.

---

# 6. INA input filter

Rev A initial:

~~~text
IN+ -- 10 Ω --+
              |
            100 nF
              |
IN- -- 10 Ω --+
~~~

R_FILTER_P = 10 Ω
R_FILTER_N = 10 Ω
C_FILTER = 100 nF

TI dopušta do 100 Ω, ali koristimo 10 Ω radi minimalne dodatne gain error osjetljivosti.

---

# 7. INA238 power

~~~text
3V3_SYS -> INA238 VS
          |
         100 nF
          |
         GND
~~~

Dodatno 1 µF lokalno.

RefDes:

- C_INA_HF = 100 nF
- C_INA_LOCAL = 1 µF

---

# 8. I2C bus

INA238 se može spojiti na shared P4 I2C:

~~~text
GPIO7 SDA
GPIO8 SCL
~~~

Touch i INA238 koriste isti fizički bus.

Odabrana adresa:

**0x40**

A0 = GND
A1 = GND

To ne kolidira s GT911 0x5D.

Postojeći touch pull-upovi mogu služiti busu; ne duplicirati nepotrebne jake pull-upove na INA sheetu.

---

# 9. ALERT

INA238 ALERT je koristan za brownout/power-envelope debugging.

Predloženi GPIO:

**GPIO53 = SYS_POWER_ALERT_N**

Status:

**LOCK-CANDIDATE / optional**

Topologija:

~~~text
3V3_SYS
 |
10k
 |
SYS_POWER_ALERT_N ---- GPIO53
       |
     INA238 ALERT
~~~

Ako INA238 nije populiran:

GPIO53 ostaje slobodan.

---

# 10. Alert use cases

Firmware može konfigurirati ALERT za:

- overcurrent
- overpower
- bus undervoltage
- conversion-ready tijekom test firmwarea

Najkorisnije u EVT/DVT:

**5V_SYS undervoltage** i **system overcurrent**.

P4 tada može timestampati power incident uz:

- USB fault state
- Wi-Fi state
- SD state
- audio load
- backlight duty

---

# 11. Optional rail dividers

Ne treba digitalni monitor na svakom railu.

Predvidjeti P4 ADC DNP dividers samo za engineering:

## 5V_SYS_ADC

Primjer:

~~~text
5V_SYS -- 100k --+-- 100k -- GND
                 |
               ADC pin
                 |
               100nF
                 |
                GND
~~~

Ali zbog GPIO budgeta i zato što INA238 već mjeri 5V_SYS, ovo nije primary.

Status:

**DNP / not required**

---

# 12. USB port current characterization

Ne dodajemo dva dodatna INA238 u production baseline.

USB0 i USB1 već imaju optional shunt/jumper measurement footprints iz USB power designa.

Tijekom EVT-a:

- USB0 measure with current probe or temporary low-ohm shunt
- USB1 measure with current probe or temporary low-ohm shunt

Total system current kontinuirano bilježi INA238.

---

# 13. Critical rail test points

Mandatory large/accessible:

~~~text
TP_VIN_5V
TP_5V_SYS
TP_3V3_SYS
TP_P4_VDD_HP
TP_3V3_C6
TP_3V3_AUDIO
TP_3V3_SD
TP_USB0_VBUS
TP_USB1_VBUS
TP_MIPI_2V5
TP_LEDA
~~~

GND:

najmanje 3 scope-friendly ground loops oko ploče:

- power area
- P4/digital area
- audio/display area

---

# 14. Scope probe philosophy

Za railove:

- normalni test pointovi
- ground spring-friendly pad blizu raila

Za high-speed buses:

- nema velikih loops
- samo micro probe pads gdje stvarno potrebno

Testability ne smije uništiti signal integrity.

---

# 15. Thermal monitoring

INA238 ima internal die temperature sensing, ali ne mjeri hotspot drugih regulatora.

EVT thermal survey treba obuhvatiti:

- TPS259474A
- TPS62132
- TLV62569
- USB0 TPS25221
- USB1 TPS25221
- MP3202
- ESP32-P4
- ESP32-C6
- PCM5102A
- SD load switch

IR kamera / thermocouple measurement pri worst-case combined loadu.

---

# 16. Brownout event capture

Recommended test firmware ring buffer:

~~~text
timestamp
5V_SYS_mV
system_mA
system_mW
3V3 status
eFuse PG
USB0 fault
USB1 fault
USB0 enabled
USB1 enabled
SD powered
Wi-Fi state
backlight %
deck/audio load state
reset reason
~~~

Kod reboot-a zadnjih N sampleova spremiti u retained/crash log ako je moguće.

---

# 17. Sampling rate

INA238 nije audio-rate instrument.

Za power diagnostics dovoljno:

- normal telemetry: 10–50 samples/s
- stress diagnostics: 100–500 samples/s ovisno o conversion time/averaging
- pravi microsecond transient i dalje se mjeri osciloskopom

Digital monitor i scope se nadopunjuju.

---

# 18. DNP strategy

Rev A PCB footprint sadrži INA238 i shunt.

Opcije:

## EVT

populate:
- shunt
- INA238
- ALERT
- full telemetry

## Cost-down production

Ako se INA238 uklanja:

- R_SHUNT se zamijeni odobrenim footprint-compatible 0 Ω high-current jumperom ako se želi eliminirati mjerni pad; standardna EVT/DVT konfiguracija zadržava WSK25125L000FEA
- INA footprint DNP
- ALERT GPIO oslobođen

Bolje je zadržati 5 mΩ shunt samo ako njegov cost/drop nije problem.

---

# 19. Preliminary BOM

| RefDes | Qty | Part/value | Status |
|---|---:|---|---|
| U_MON | 0/1 | INA238AIDGSR | DNP-capable |
| R_SYS_SHUNT | 1 | **WSK25125L000FEA — 5 mΩ, 1%, 1 W, 4-terminal** | LOCK-CANDIDATE; `Resistor_SMD:R_Shunt_Vishay_WSK2512_6332Metric_T1.19mm` |
| R_INA_P | 1 | 10 Ω | filter |
| R_INA_N | 1 | 10 Ω | filter |
| C_INA_DIFF | 1 | 100 nF | filter |
| C_INA_HF | 1 | 100 nF | supply |
| C_INA_LOCAL | 1 | 1 µF | supply |
| R_INA_ALERT_PU | 1 | 10 kΩ | optional |
| TP_RAIL_* | set | test pads | mandatory |
| TP_GND_LOOP_* | 3+ | scope ground loops | mandatory |

---

# 20. GPIO allocation update

~~~text
GPIO53 -> SYS_POWER_ALERT_N
~~~

samo kada je INA238 populiran.

Ovo je optional function i ne smije blokirati buduću važniju funkciju.

---

# 21. Factory use

Factory test može koristiti INA238 za:

- no-load current sanity
- boot current envelope
- detect assembly short/high-current board
- full-load power sanity
- USB attach power delta

Primjer:

~~~text
boot_idle_current within expected window
USB0_delta within expected window
USB1_delta within expected window
backlight_delta within expected window
~~~

To je vrlo korisno za proizvodni screening.

---

# 22. Acceptance

Monitoring subsystem prolazi ako:

- current reading usporediv s bench DMM-om
- no measurable impact on 5V_SYS stability
- ALERT radi
- I2C ne interferira s GT911
- shunt nema thermal issue
- Kelvin layout daje stabilno mjerenje
- monitor može biti DNP bez promjene funkcije ostatka boarda

---

# 23. Zaključak

Rev A monitoring:

~~~text
5V_PROTECTED
   |
5mΩ Kelvin shunt
   |
5V_SYS
   |
INA238 high-side measurement

INA238:
3V3_SYS supply
I2C address 0x40
GPIO7/8 shared bus
GPIO53 optional ALERT
~~~

Ovo daje Pajoniiiru ugrađeni engineering alat za dokazivanje power margine i hvatanje brownout uzroka bez oslanjanja samo na subjektivno opažanje.

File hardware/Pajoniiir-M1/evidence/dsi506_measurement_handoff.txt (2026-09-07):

Da. Za drugi projekt koristi ove mjere kao **mehanički datum za kompletan 5" DSI506/DYL0023 modul**, uključujući LCD, stražnji PCB i četiri navojna nosača.

### Osnovne dimenzije modula

| Element | Mjera |
| --- | ---: |
| Prednje staklo / touch površina | **120.0 × 75.0 mm** |
| Stražnji PCB – ukupni gabarit | **121.109 × 77.193 mm** |
| Vidljivi LCD | **110.0 × 67.0 mm** |
| Ukupna nominalna debljina display sklopa | **7.0 mm** |
| Prednja ploha → stražnja ploha PCB-a | **5.0 mm** |
| Prednja ploha → najviša stražnja komponenta/nosač | **10.0 mm max.** |

Vidljiva površina LCD-a počinje **5.0 mm od lijevog ruba stakla** i **2.0 mm od gornjeg ruba**. Desni rub je također 5 mm, a donji 6 mm.

### Koordinatni sustav za CAD

Najpraktičnije je definirati:

* **X=0, Y=0 = gornji lijevi kut stražnjeg PCB-a**, gledano sa stražnje strane
* +X ide udesno
* +Y ide prema dolje
* Z=0 = prednja površina stakla
* stražnja strana je +Z.

### Svih 8 mehaničkih pozicija

Stražnji PCB ima raster od **8 pozicija Ø2.5 mm**, odnosno radijus 1.25 mm. Koordinate centara su:

| Pozicija | X | Y |
| --- | ---: | ---: |
| gornja lijeva vanjska | **5.000** |  **5.000** |
| gornja lijeva unutarnja |  **43.109** |  **7.430** |
| gornja desna unutarnja  | **101.109** |  **7.430** |
| gornja desna vanjska | **116.109** |  **5.000** |
| donja lijeva unutarnja  |  **43.109** | **56.430** |
| donja desna unutarnja | **101.109** | **56.430** |
| donja lijeva vanjska | **5.000** | **72.930** |
| donja desna vanjska | **116.109** | **72.930** |

Sve mjere su u milimetrima i odnose se na gornji lijevi kut stražnjeg PCB-a.

### Vanjska četiri otvora

Vanjski raster je približno:

**111.109 × 67.930 mm**, centar–centar.

Dakle horizontalno:

`5.000 → 116.109 = 111.109 mm`

i vertikalno:

`5.000 → 72.930 = 67.930 mm`.

### Četiri unutarnja navojna nosača

Ovo su ti vjerojatno **najvažnije mjere za drugi projekt**, jer se na njih može direktno pričvrstiti druga PCB ploča.

Raster nosača:

**58.0 × 49.0 mm**

Centri:

```text
        58.000 mm
   ●────────────────●
   │                │
   │                │ 49.000 mm
   │                │
   ●────────────────●
```

Apsolutne koordinate:

```text
UL = X 43.109 / Y  7.430
UR = X101.109 / Y  7.430

LL = X 43.109 / Y 56.430
LR = X101.109 / Y 56.430
```

Ti nosači su fizički potvrđeni kao:

* **4 komada**
* vanjski promjer nosača: **Ø5.0 mm**
* visina nosača iznad stražnje površine PCB-a: **5.0 mm**
* unutarnji navoj: **M2.5**
* uporabiva dubina navoja: **3.0 mm**
* vrhovi sva četiri nosača su koplanarni.

### Z-stack nosača

Ako prednju površinu stakla definiramo kao **Z=0**:

```text
Z = 0.0 mm     prednja površina stakla
    │
    │ 5.0 mm
    ▼
Z = 5.0 mm     stražnja ravnina controller PCB-a
    │
    │ 5.0 mm  visina nosača
    ▼
Z = 10.0 mm    vrh četiri M2.5 nosača
```

Dakle PCB koji postaviš direktno na te nosače imat će svoju donju površinu na približno **Z=10.0 mm**. Ako koristiš standardni PCB od **1.6 mm**, njegova stražnja/gornja površina bit će na **Z=11.6 mm**.

Za PCB koji pričvršćuješ na nosače predviđeni clearance otvori su okvirno **Ø3.0–3.2 mm** za M2.5 vijke. Za 1.6-mm PCB kao početna konfiguracija potvrđen je **M2.5 × 4 mm** vijak: dobiva se približno 2.4 mm zahvata navoja i ostaje oko 0.6 mm do dna. **M2.5 × 5 mm bez podloške/spacera nemoj koristiti**, jer bi premašio izmjerenu dubinu navoja od 3 mm.

### DSI konektor — korisno za CAD drugog projekta

Centar DSI konektora na stražnjem PCB-u:

**X = 110.109 mm, Y = 33.000 mm**

od istog gornjeg lijevog PCB datuma. Konektor je uz **desni rub PCB-a**, a kabel se umeće prema `-X`. FFC je:

**15 pin / 1.0 mm pitch / približno 60 × 15 mm**, Type-B, bez uvrtanja kabela.

### Sažetak koji možeš direktno prebaciti u CAD

```text
DISPLAY:
Front glass:        120.000 × 75.000 mm
Rear PCB:           121.109 × 77.193 mm
Visible LCD:        110.000 × 67.000 mm
Visible LCD offset: X=5.000, Y=2.000 mm

Z:
Front glass:        Z=0
Rear PCB plane:     Z=5.000 mm
Display body:       Z≈7.000 mm
Post tops:          Z=10.000 mm

INNER THREADED POSTS:
Count:              4
Thread:             M2.5
Outer diameter:     Ø5.000 mm
Height:             5.000 mm
Usable thread:      3.000 mm
Pattern:            58.000 × 49.000 mm

Post centers:
UL:  43.109,  7.430
UR: 101.109,  7.430
LL:  43.109, 56.430
LR: 101.109, 56.430

OUTER HOLES:
Diameter:           Ø2.500 mm
Pattern:            111.109 × 67.930 mm

Outer centers:
UL:   5.000,  5.000
UR: 116.109,  5.000
LL:   5.000, 72.930
LR: 116.109, 72.930

DSI CONNECTOR CENTER:
X=110.109
Y=33.000
```

Jedina važna napomena: **M2.5 nosači, Ø5 mm, visina 5 mm i dubina navoja 3 mm su fizički potvrđeni**, dok je gabarit stražnjeg PCB-a **121.109 × 77.193 mm nominalna mjera izvedena iz našeg dimenzioniranog fizičkog materijala** i za serijsku proizvodnju smo ostavili zahtjev za završnom provjerom šublerom/službenim CAD-om.

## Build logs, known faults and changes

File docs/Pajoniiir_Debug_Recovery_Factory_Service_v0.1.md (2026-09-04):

# Pajoniiir Mainboard — Debug, Recovery & Factory Service Design v0.1

**Projekt:** Pajoniiir BL-A1800 / Pajoniiir-M1  
**Ploča:** Pajoniiir Mainboard Rev A  
**Blok:** 13_DEBUG_SERVICE  
**Datum:** 2026-09-02  
**Status:** Captured in KiCad; service architecture and J9 factory-pogo footprint locked

---

# 1. Cilj

Rev A mora biti recoverable čak kada ne rade application firmware, Wi-Fi / ESP-Hosted, USB0 storage, USB1 FLX4, display ili microSD.

Zato Pajoniiir-M1 dobiva više neovisnih servisnih puteva.

---

# 2. Recovery hierarchy

1. **P4 UART0** — najrobustniji recovery/download
2. **P4 USB Serial/JTAG** — factory/debug bez USB-UART bridgea
3. **C6 UART0 + boot straps** — direktni C6 recovery
4. RESET/BOOT pogo access
5. test-point railovi

Ni jedan recovery path ne smije ovisiti o glavnom LCD-u ili mreži.

---

# 3. P4 UART0

ESP32-P4 default UART0:

~~~text
GPIO37 = TX
GPIO38 = RX
~~~

Oba su strapping pinovi, pa ih se ne smije agresivno opteretiti tijekom boot sampling intervala.

Rev A:

~~~text
GPIO37 -- 33R --> P4_UART0_TX
GPIO38 -- 33R --> P4_UART0_RX
~~~

Bez velikih capacitors.

---

# 4. P4 BOOT / RESET

Servis mora imati pristup:

~~~text
P4_CHIP_PU
P4_BOOT_GPIO35
P4_BOOT_GPIO36
~~~

Normalno:

- GPIO35 = 10 kΩ pull-up
- GPIO36 = 10 kΩ pull-up

Download:

- GPIO35 LOW
- GPIO36 HIGH
- reset / CHIP_PU cycle

---

# 5. P4 USB Serial/JTAG

Aktualni Espressif P4 hardware guide potvrđuje:

~~~text
GPIO24 = USB Serial/JTAG D-
GPIO25 = USB Serial/JTAG D+
~~~

Pajoniiir namjerno čuva ova dva GPIO-a jer USB1 koristi GPIO26/27.

To omogućuje USB download boot, serial console, JTAG debugging i production programming bez posebnog USB-UART bridge IC-a.

---

# 6. USB Serial/JTAG signal conditioning

Kao i drugi P4 Full-Speed USB path:

~~~text
GPIO24 DM -- 22R -- service pads
GPIO25 DP -- 22R -- service pads
~~~

Optional DNP shunt capacitors:

- C_P4_USBJTAG_DM = DNP
- C_P4_USBJTAG_DP = DNP

Ovaj interface može završiti na factory pogo footprintu; ne mora imati user-facing USB connector.

---

# 7. P4 Tag-Connect / pogo connector

Primary service footprint:

**TC2030-NL-FP class, 6-pin no-parts footprint**

Tag-Connect footprint nije populirani BOM dio.

Predloženi Pajoniiir assignment:

| Pin | Signal |
|---:|---|
| 1 | 3V3_SYS sense/VREF |
| 2 | P4_UART0_TX |
| 3 | P4_UART0_RX |
| 4 | P4_CHIP_PU |
| 5 | GND |
| 6 | P4_BOOT_GPIO35 |

GPIO36 je hard-pulled HIGH pa ga ne moramo trošiti na 6-pin interface.

Uz connector ipak staviti zaseban TP_GPIO36.

---

# 8. P4 USB Serial/JTAG pogo

Za USB Serial/JTAG koristi se zaseban mali 4-pad/5-pad fixture footprint:

~~~text
3V3_SYS VREF
GND
USBJTAG_DM
USBJTAG_DP
optional CHIP_PU
~~~

Ne spajati VBUS s programatora direktno na 5V_SYS bez definirane politike.

Factory fixture u pravilu koristi board vlastito napajanje, a 3V3 je samo reference/sense.

---

# 9. C6 direct recovery

C6 test access:

~~~text
C6_UART_TX
C6_UART_RX
C6_EN
C6_GPIO8
C6_GPIO9
3V3_C6
GND
~~~

Minimalni 6-pin pogo assignment:

| Pin | Signal |
|---:|---|
| 1 | 3V3_C6 VREF |
| 2 | C6_UART_TX |
| 3 | C6_UART_RX |
| 4 | C6_EN |
| 5 | GND |
| 6 | C6_GPIO9_BOOT |

GPIO8 ima hard 10 kΩ pull-up pa Joint Download zahtijeva samo GPIO9 LOW + EN reset.

---

# 10. Separate P4 and C6 fixtures

Ne pokušavati stisnuti P4 i C6 recovery u isti 6-pin connector.

Razlozi:

- smanjuje grešku u proizvodnji
- oba procesora se mogu servisirati neovisno
- jednostavniji fixture
- jasniji silkscreen

Naming:

~~~text
JDBG_P4
JDBG_C6
~~~

---

# 11. Silkscreen

Na bare PCB-u jasno označiti:

~~~text
P4 DBG
C6 DBG
BOOT
RST
3V3
5V
GND
~~~

Pin 1 na Tag-Connect footprintu jasno obilježiti.

---

# 12. Service power policy

Factory programmer ne smije slučajno napajati board kroz signalni VREF.

VREF pinovi služe kao **sense/reference only**.

Ako je potreban fixture power input, koristiti zaseban FACTORY_5V_IN kroz definirani power path ili glavni 5 V input connector.

---

# 13. Manual RESET / BOOT access

Rev A engineering board treba fizičke tipke:

- SW_RESET
- SW_BOOT

Finalni production enclosure može ih sakriti iza service holea ili ih kasnije ukloniti iz user accessa.

Footprintove na Rev A zadržati.

---

# 14. Console strategy

P4 primary console tijekom bring-upa: **UART0**.

Kasnije production firmware može koristiti USB Serial/JTAG console, ali UART ostaje hard recovery.

C6 primary recovery console: **UART0 direct pads**.

ESP-Hosted logs preko P4 nisu dovoljan recovery path.

---

# 15. JTAG

P4 USB Serial/JTAG je primarni low-BOM debug path.

Ako budući hard debugging zatraži dedicated external JTAG pins/debugger, Rev A ima dovoljno spare GPIO-a, ali ne treba sada trošiti PCB prostor i pinove bez potrebe.

---

# 16. Logic-level policy

Svi P4 i C6 servisni UART signali:

**3.3 V logic**

Ne priključivati RS-232 voltage-level adapter.

Fixture mora koristiti 3.3 V TTL UART.

---

# 17. UART ESD

Debug pads su interni/factory access.

Default: **nema zasebne ESD diode**.

Ako finalni enclosure izvede debug header van korisniku, protection se mora ponovno definirati.

---

# 18. Test point set

P4:

- TP_P4_UART_TX
- TP_P4_UART_RX
- TP_P4_BOOT35
- TP_P4_BOOT36
- TP_CHIP_PU
- TP_USBJTAG_DM
- TP_USBJTAG_DP

C6:

- TP_C6_UART_TX
- TP_C6_UART_RX
- TP_C6_EN
- TP_C6_GPIO8
- TP_C6_GPIO9

Power:

- TP_5V_SYS
- TP_3V3_SYS
- TP_P4_VDD_HP
- TP_3V3_C6
- GND test loops

---

# 19. Factory programming flow

## P4

1. power board from qualified 5 V source
2. fixture detects 3V3 VREF
3. force GPIO35 LOW
4. pulse CHIP_PU
5. flash bootloader/partition/app
6. verify flash
7. reset normal boot
8. read serial number / test firmware

## C6

1. ensure 3V3_C6 valid
2. force GPIO9 LOW
3. pulse C6_EN
4. flash ESP-Hosted slave image
5. release GPIO9
6. reset
7. verify C6 UART boot
8. run P4↔C6 SDIO self-test

---

# 20. Production test firmware

Rev A treba imati dedicated factory-test app/mode koji može provjeriti rail health, PSRAM, flash, C6, Wi-Fi, microSD, USB0, USB1, PCM5102A tone, LCD, touch, buttons i FAULT pinove.

Rezultat treba biti machine-readable preko UART/USB console.

---

# 21. Fixture detection

Fixture treba čitati board identification iz firmwarea.

Ne uvoditi dodatni EEPROM ili trošiti GPIO samo za Rev A board ID.

Board revision se može kodirati kroz:

- firmware board ID
- PCB silkscreen
- manufacturing database

---

# 22. Preliminary BOM / footprints

| RefDes | Qty | Item | Status |
|---|---:|---|---|
| JDBG_P4 | 1 | TC2030-NL-FP class | PCB footprint only, DNL |
| JDBG_C6 | 1 | TC2030-NL-FP class | PCB footprint only, DNL |
| JDBG_USB | 1 | 4/5-pad pogo footprint | PCB-only |
| R_UART_P4_TX | 1 | 33 Ω | required |
| R_UART_P4_RX | 1 | 33 Ω | required |
| R_USBJTAG_DM | 1 | 22 Ω | candidate |
| R_USBJTAG_DP | 1 | 22 Ω | candidate |
| C_USBJTAG_DM | 1 | DNP | tuning |
| C_USBJTAG_DP | 1 | DNP | tuning |
| SW_RESET | 1 | momentary NO | Rev A |
| SW_BOOT | 1 | momentary NO | Rev A |

---

# 23. Acceptance criteria

- P4 recoverable with application flash erased
- C6 recoverable with corrupt ESP-Hosted image
- UART boot logs stable
- USB Serial/JTAG enumerates independently of USB1
- fixture cannot back-power board through VREF
- BOOT/RESET sequence repeatable 100/100
- no strapping failures with debug cable attached
- no permanent debug connector required for production unit

---

# 24. Zaključak

Rev A dobiva tri nezavisna servisna puta:

~~~text
P4 UART0:
GPIO37 / GPIO38
Tag-Connect/pogo
BOOT + RESET

P4 USB Serial/JTAG:
GPIO24 / GPIO25
factory pogo

C6 direct UART:
UART0 + GPIO9 + EN
separate pogo
~~~

Time board ostaje servisabilan čak i kod potpunog firmware failurea.

**Sljedeći blok:** 14_TEST_MONITORING — 5V_SYS current/voltage telemetry, optional INA238, shunt, ALERT i DNP strategy.

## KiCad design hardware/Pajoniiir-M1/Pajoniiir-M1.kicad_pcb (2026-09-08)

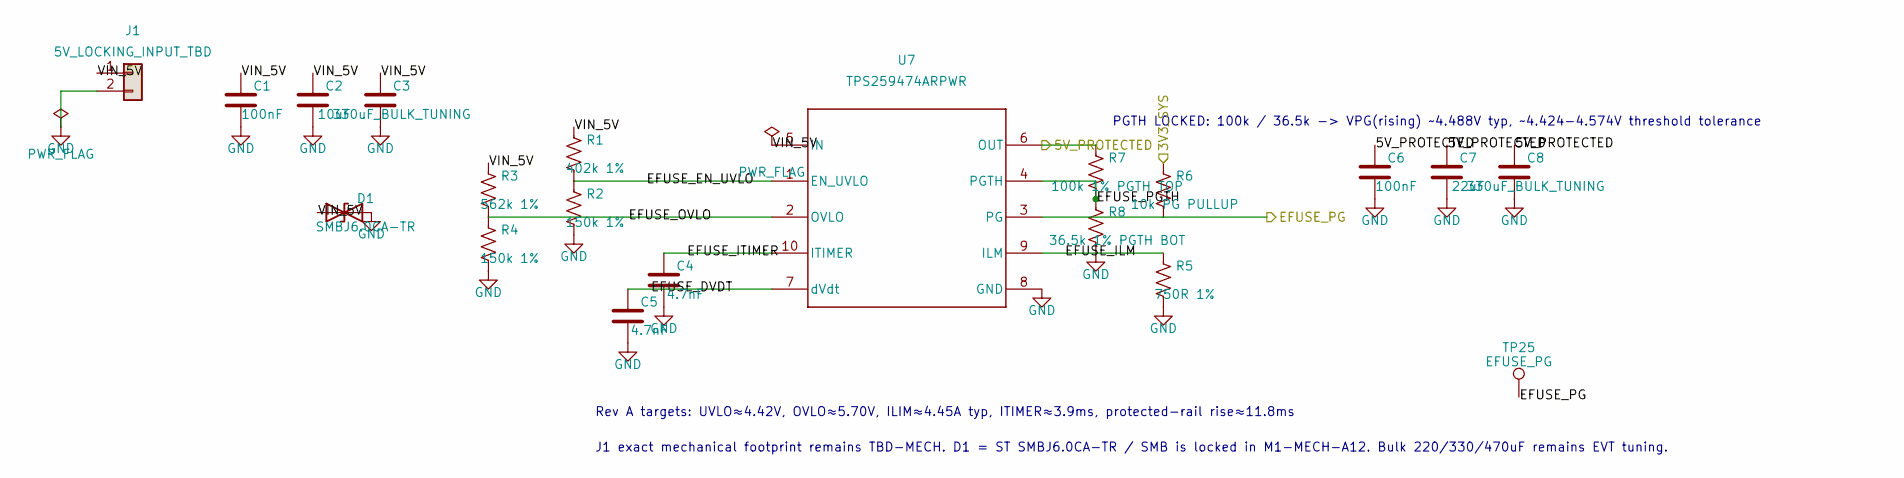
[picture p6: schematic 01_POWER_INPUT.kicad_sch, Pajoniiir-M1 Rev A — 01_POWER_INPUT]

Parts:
C1, C6: 100nF; C_0603_1608Metric
C2: 10uF; C_0805_2012Metric
C3, C8: 330uF_BULK_TUNING
C4, C5: 4.7nF; C_0603_1608Metric
C7: 22uF; C_1206_3216Metric
D1: SMBJ6.0CA-TR; D_SMB
J1: 5V_LOCKING_INPUT_TBD
R1: 402k 1%; R_0603_1608Metric
R2, R4: 150k 1%; R_0603_1608Metric
R3: 562k 1%; R_0603_1608Metric
R5: 750R 1%; R_0603_1608Metric
R6: 10k PG PULLUP; R_0603_1608Metric
R7: 100k 1% PGTH TOP; R_0603_1608Metric
R8: 36.5k 1% PGTH BOT; R_0603_1608Metric
TP25: EFUSE_PG; TestPoint_Pad_D1.5mm
U7: TPS259474ARPWR; Texas_RPW0010A_VQFN-HR-10_2x2mm; MPN TPS259474ARPWR

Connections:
/01_POWER_INPUT/EFUSE_DVDT: C5.1, U7.7 (dVdt)
/01_POWER_INPUT/EFUSE_EN_UVLO: R1.2, R2.1, U7.1 (EN_UVLO)
/01_POWER_INPUT/EFUSE_ITIMER: C4.1, U7.10 (ITIMER)
/01_POWER_INPUT/EFUSE_OVLO: R3.2, R4.1, U7.2 (OVLO)
/01_POWER_INPUT/EFUSE_PG: R6.2, TP25.1, U7.3 (PG)
/01_POWER_INPUT/EFUSE_PGTH: R7.2, R8.1, U7.4 (PGTH)
/01_POWER_INPUT/VIN_5V: C1.1, C2.1, C3.1, D1.1 (A1), J1.1, R1.1, R3.1, U7.5 (IN)
/3V3_SYS: R6.1; also elsewhere on the board
/5V_PROTECTED: C6.1, C7.1, C8.1, R7.1, U7.6 (OUT); also elsewhere on the board

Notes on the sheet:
PGTH LOCKED: 100k / 36.5k -> VPG(rising) ~4.488V typ, ~4.424-4.574V threshold tolerance
Rev A targets: UVLO≈4.42V, OVLO≈5.70V, ILIM≈4.45A typ, ITIMER≈3.9ms, protected-rail rise≈11.8ms
J1 exact mechanical footprint remains TBD-MECH. D1 = ST SMBJ6.0CA-TR / SMB is locked in M1-MECH-A12. Bulk 220/330/470uF remains EVT tuning.

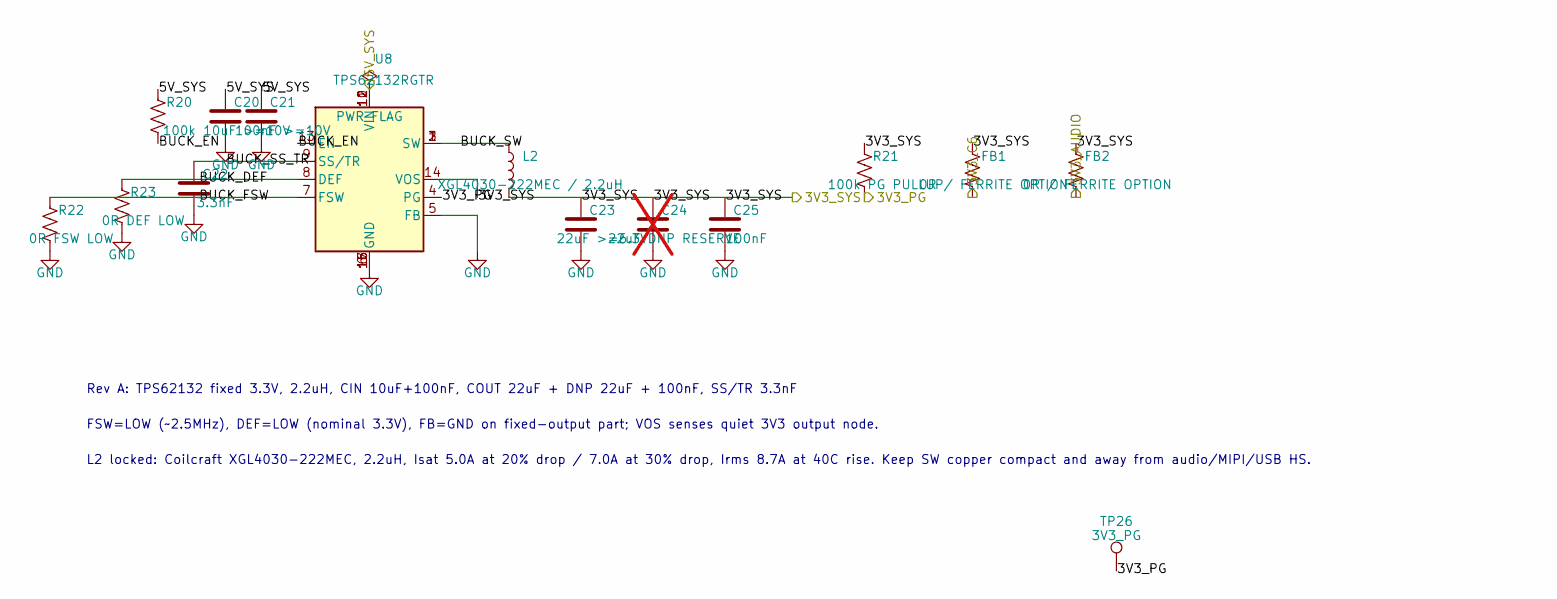
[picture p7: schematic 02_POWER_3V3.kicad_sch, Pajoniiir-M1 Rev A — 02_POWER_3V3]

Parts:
C20: 10uF >=10V; C_0805_2012Metric
C21: 100nF >=10V; C_0603_1608Metric
C22: 3.3nF; C_0603_1608Metric
C23: 22uF >=6.3V; C_1206_3216Metric
C24: 22uF DNP RESERVE; C_1206_3216Metric; not fitted
C25: 100nF; C_0603_1608Metric
FB1, FB2: 0R / FERRITE OPTION; R_0603_1608Metric
L2: XGL4030-222MEC / 2.2uH; L_Coilcraft_XxL4030
R20: 100k; R_0603_1608Metric
R21: 100k PG PULLUP; R_0603_1608Metric
R22: 0R FSW LOW; R_0603_1608Metric
R23: 0R DEF LOW; R_0603_1608Metric
TP26: 3V3_PG; TestPoint_Pad_D1.5mm
U8: TPS62132RGTR; VQFN-16-1EP_3x3mm_P0.5mm_EP1.68x1.68mm_ThermalVias

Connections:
/02_POWER_3V3/3V3_PG: R21.2, TP26.1, U8.4 (PG)
/02_POWER_3V3/BUCK_DEF: R23.1, U8.8 (DEF)
/02_POWER_3V3/BUCK_EN: R20.2, U8.13 (EN)
/02_POWER_3V3/BUCK_FSW: R22.1, U8.7 (FSW)
/02_POWER_3V3/BUCK_SS_TR: C22.1, U8.9 (SS/TR)
/02_POWER_3V3/BUCK_SW: L2.1, U8.1 (SW), U8.2 (SW), U8.3 (SW)
/3V3_AUDIO: FB2.2; also elsewhere on the board
/3V3_C6: FB1.2; also elsewhere on the board
/3V3_SYS: C23.1, C24.1, C25.1, FB1.1, FB2.1, L2.2, R21.1, U8.14 (VOS); also elsewhere on the board
/5V_SYS: C20.1, C21.1, R20.1, U8.10 (VIN), U8.11 (VIN), U8.12 (VIN); also elsewhere on the board

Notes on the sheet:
Rev A: TPS62132 fixed 3.3V, 2.2uH, CIN 10uF+100nF, COUT 22uF + DNP 22uF + 100nF, SS/TR 3.3nF
FSW=LOW (~2.5MHz), DEF=LOW (nominal 3.3V), FB=GND on fixed-output part; VOS senses quiet 3V3 output node.
L2 locked: Coilcraft XGL4030-222MEC, 2.2uH, Isat 5.0A at 20% drop / 7.0A at 30% drop, Irms 8.7A at 40C rise. Keep SW copper compact and away from audio/MIPI/USB HS.

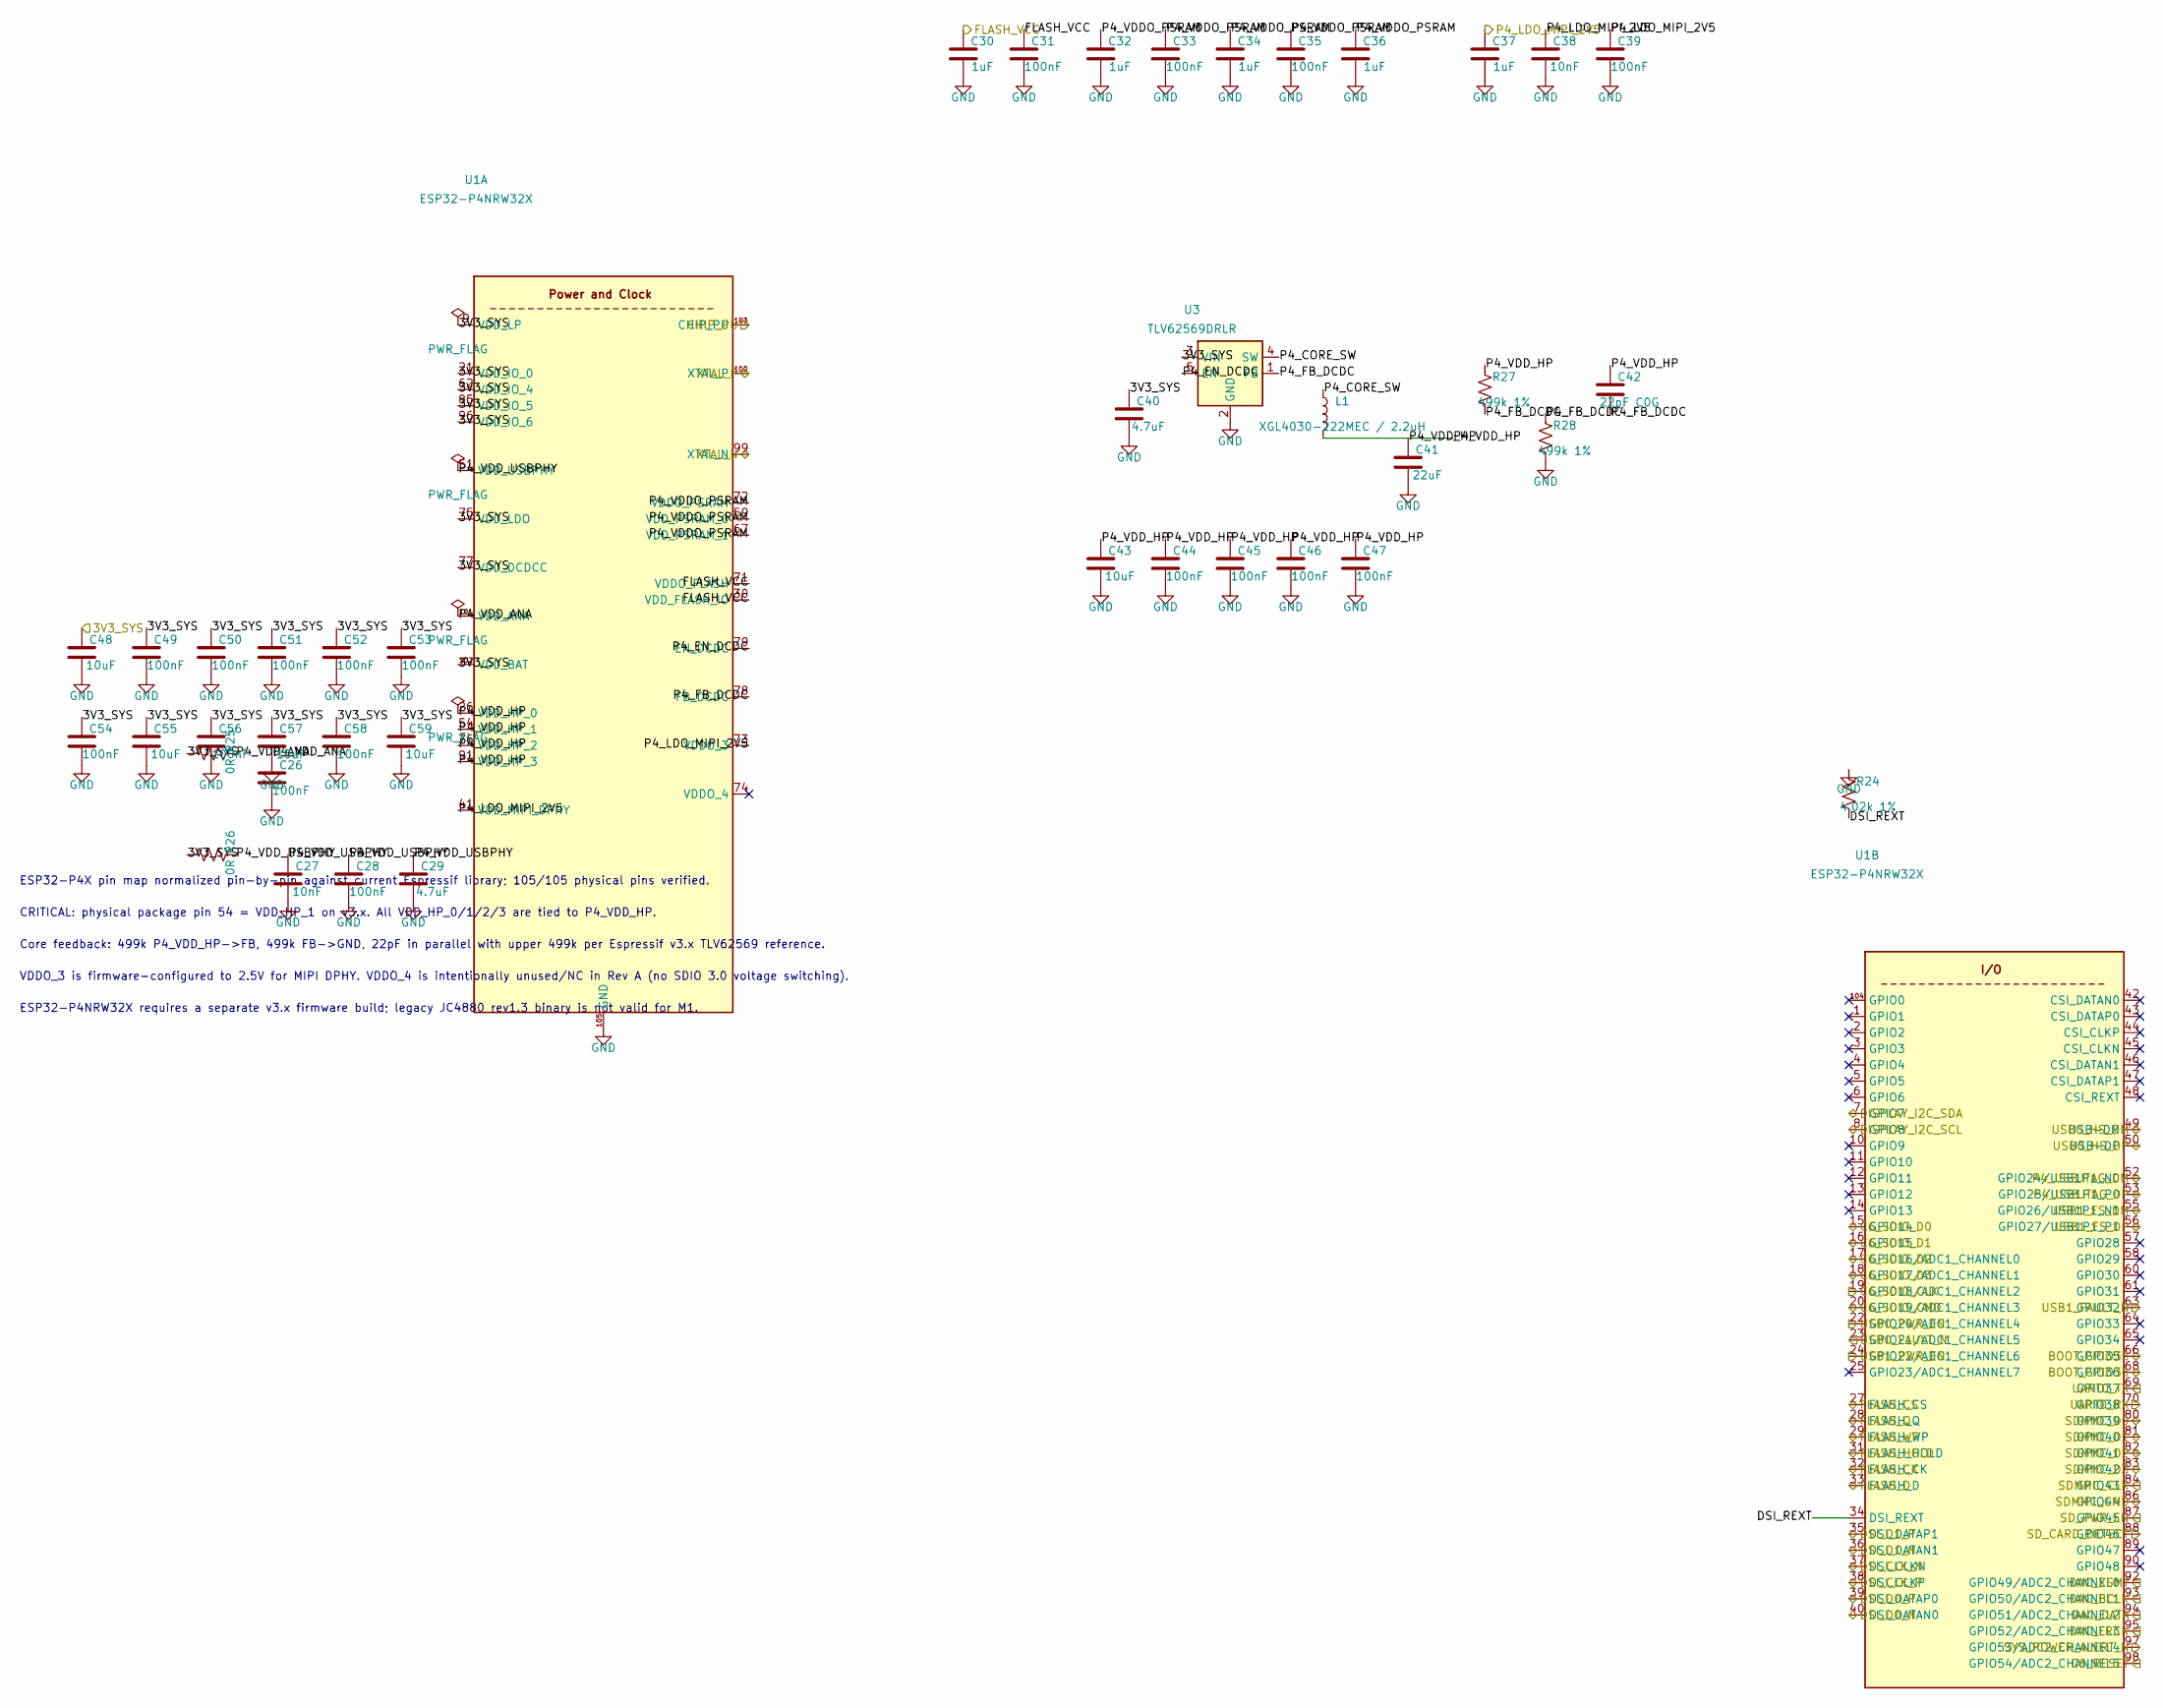
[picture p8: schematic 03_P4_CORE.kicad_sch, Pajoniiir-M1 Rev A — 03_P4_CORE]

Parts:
C26, C28, C31, C33, C35, C39, C44, C45, C46, C47, C49, C50, C51, C52, C53, C54, C56, C58: 100nF; C_0603_1608Metric
C27, C38: 10nF; C_0402_1005Metric
C29: 4.7uF; C_0603_1608Metric
C30, C32, C34, C36, C37: 1uF; C_0603_1608Metric
C40: 4.7uF; C_0805_2012Metric
C41: 22uF; C_0805_2012Metric
C42: 22pF C0G; C_0402_1005Metric
C43, C48, C55, C57, C59: 10uF; C_0805_2012Metric
L1: XGL4030-222MEC / 2.2uH; L_Coilcraft_XxL4030
R24: 4.02k 1%; R_0402_1005Metric
R25, R26: 0R; R_0603_1608Metric
R27, R28: 499k 1%; R_0402_1005Metric
U1: ESP32-P4NRW32X; ESP32-P4
U3: TLV62569DRLR; SOT-563

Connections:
/3V3_SYS: C40.1, C48.1, C49.1, C50.1, C51.1, C52.1, C53.1, C54.1, C55.1, C56.1, C57.1, C58.1, C59.1, R25.1, R26.1, U1.9 (VDD_LP), U1.21 (VDD_IO_0), U1.62 (VDD_IO_4), U1.75 (VDD_LDO), U1.77 (VDD_DCDCC), U1.85 (VDD_IO_5), U1.96 (VDD_IO_6), U1.102 (VDD_BAT), U3.3 (VIN); also elsewhere on the board
/03_P4_CORE/DSI_REXT: R24.2, U1.34 (DSI_REXT)
/03_P4_CORE/FLASH_CK: U1.32 (FLASH_CK); also elsewhere on the board
/03_P4_CORE/FLASH_D: U1.33 (FLASH_D); also elsewhere on the board
/03_P4_CORE/FLASH_HOLD: U1.31 (FLASH_HOLD); also elsewhere on the board
/03_P4_CORE/FLASH_Q: U1.28 (FLASH_Q); also elsewhere on the board
/03_P4_CORE/FLASH_VCC: C30.1, C31.1, U1.30 (VDD_FLASH_IO), U1.71 (VDDO_FLASH); also elsewhere on the board
/03_P4_CORE/FLASH_WP: U1.29 (FLASH_WP); also elsewhere on the board
/03_P4_CORE/P4_CORE_SW: L1.1, U3.4 (SW)
/03_P4_CORE/P4_EN_DCDC: U1.79 (EN_DCDC), U3.5 (EN)
/03_P4_CORE/P4_FB_DCDC: C42.2, R27.2, R28.1, U1.78 (FB_DCDC), U3.1 (FB)
/03_P4_CORE/P4_VDDO_PSRAM: C32.1, C33.1, C34.1, C35.1, C36.1, U1.59 (VDD_PSRAM_0), U1.67 (VDD_PSRAM_1), U1.72 (VDDO_PSRAM)
/03_P4_CORE/P4_VDD_ANA: C26.1, R25.2, U1.101 (VDD_ANA)
/03_P4_CORE/P4_VDD_HP: C41.1, C42.1, C43.1, C44.1, C45.1, C46.1, C47.1, L1.2, R27.1, U1.26 (VDD_HP_0), U1.54 (VDD_HP_1), U1.76 (VDD_HP_2), U1.91 (VDD_HP_3)
/03_P4_CORE/P4_VDD_USBPHY: C27.1, C28.1, C29.1, R26.2, U1.51 (VDD_USBPHY)
/04_P4_FLASH_CLOCK_RESET/FLASH_CS: U1.27 (FLASH_CS); also elsewhere on the board
/BOOT_GPIO35: U1.66 (GPIO35); also elsewhere on the board
/BOOT_GPIO36: U1.68 (GPIO36); also elsewhere on the board
/C6_RESET: U1.98 (GPIO54/ADC2_CHANNEL5); also elsewhere on the board
/C6_SDIO_CLK: U1.19 (GPIO18/ADC1_CHANNEL2); also elsewhere on the board
/C6_SDIO_CMD: U1.20 (GPIO19/ADC1_CHANNEL3); also elsewhere on the board
/C6_SDIO_D0: U1.15 (GPIO14); also elsewhere on the board
/C6_SDIO_D1: U1.16 (GPIO15); also elsewhere on the board
/C6_SDIO_D2: U1.17 (GPIO16/ADC1_CHANNEL0); also elsewhere on the board
/C6_SDIO_D3: U1.18 (GPIO17/ADC1_CHANNEL1); also elsewhere on the board
/CHIP_PU: U1.103 (CHIP_PU); also elsewhere on the board
/DAC_BCLK: U1.93 (GPIO50/ADC2_CHANNEL1); also elsewhere on the board
/DAC_DATA: U1.94 (GPIO51/ADC2_CHANNEL2); also elsewhere on the board
/DAC_LRCK: U1.95 (GPIO52/ADC2_CHANNEL3); also elsewhere on the board
/DAC_XSMT: U1.92 (GPIO49/ADC2_CHANNEL0); also elsewhere on the board
/DISPLAY_I2C_SCL: U1.8 (GPIO8); also elsewhere on the board
/DISPLAY_I2C_SDA: U1.7 (GPIO7); also elsewhere on the board
/DSI_CLK_N: U1.37 (DSI_CLKN); also elsewhere on the board
/DSI_CLK_P: U1.38 (DSI_CLKP); also elsewhere on the board
/DSI_D0_N: U1.40 (DSI_DATAN0); also elsewhere on the board
/DSI_D0_P: U1.39 (DSI_DATAP0); also elsewhere on the board
/DSI_D1_N: U1.36 (DSI_DATAN1); also elsewhere on the board
/DSI_D1_P: U1.35 (DSI_DATAP1); also elsewhere on the board
/P4_LDO_MIPI_2V5: C37.1, C38.1, C39.1, U1.41 (VDD_MIPI_DPHY), U1.73 (VDDO_3); also elsewhere on the board
/P4_USBJTAG_DM: U1.52 (GPIO24/USB1P1_N0); also elsewhere on the board
/P4_USBJTAG_DP: U1.53 (GPIO25/USB1P1_P0); also elsewhere on the board
/SDMMC_CLK: U1.84 (GPIO43); also elsewhere on the board
/SDMMC_CMD: U1.86 (GPIO44); also elsewhere on the board
/SDMMC_D0: U1.80 (GPIO39); also elsewhere on the board
/SDMMC_D1: U1.81 (GPIO40); also elsewhere on the board
/SDMMC_D2: U1.82 (GPIO41); also elsewhere on the board
/SDMMC_D3: U1.83 (GPIO42); also elsewhere on the board
/SD_CARD_DETECT: U1.88 (GPIO46); also elsewhere on the board
/SD_PWR_EN: U1.87 (GPIO45); also elsewhere on the board
/SYS_POWER_ALERT_N: U1.97 (GPIO53/ADC2_CHANNEL4); also elsewhere on the board
/UART0_RX: U1.70 (GPIO38); also elsewhere on the board
/UART0_TX: U1.69 (GPIO37); also elsewhere on the board
/USB0_FAULT_N: U1.23 (GPIO21/ADC1_CHANNEL5); also elsewhere on the board
/USB0_HS_DM: U1.49 (USB-DM); also elsewhere on the board
/USB0_HS_DP: U1.50 (USB-DP); also elsewhere on the board
/USB0_PWR_EN: U1.22 (GPIO20/ADC1_CHANNEL4); also elsewhere on the board
/USB1_FAULT_N: U1.63 (GPIO32); also elsewhere on the board
/USB1_FS_DM: U1.55 (GPIO26/USB1P1_N1); also elsewhere on the board
/USB1_FS_DP: U1.56 (GPIO27/USB1P1_P1); also elsewhere on the board
/USB1_PWR_EN: U1.24 (GPIO22/ADC1_CHANNEL6); also elsewhere on the board
/XTAL_N: U1.99 (XTAL_N); also elsewhere on the board
/XTAL_P: U1.100 (XTAL_P); also elsewhere on the board

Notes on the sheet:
ESP32-P4X pin map normalized pin-by-pin against current Espressif library; 105/105 physical pins verified.
CRITICAL: physical package pin 54 = VDD_HP_1 on v3.x. All VDD_HP_0/1/2/3 are tied to P4_VDD_HP.
Core feedback: 499k P4_VDD_HP->FB, 499k FB->GND, 22pF in parallel with upper 499k per Espressif v3.x TLV62569 reference.
VDDO_3 is firmware-configured to 2.5V for MIPI DPHY. VDDO_4 is intentionally unused/NC in Rev A (no SDIO 3.0 voltage switching).
ESP32-P4NRW32X requires a separate v3.x firmware build; legacy JC4880 rev1.3 binary is not valid for M1.

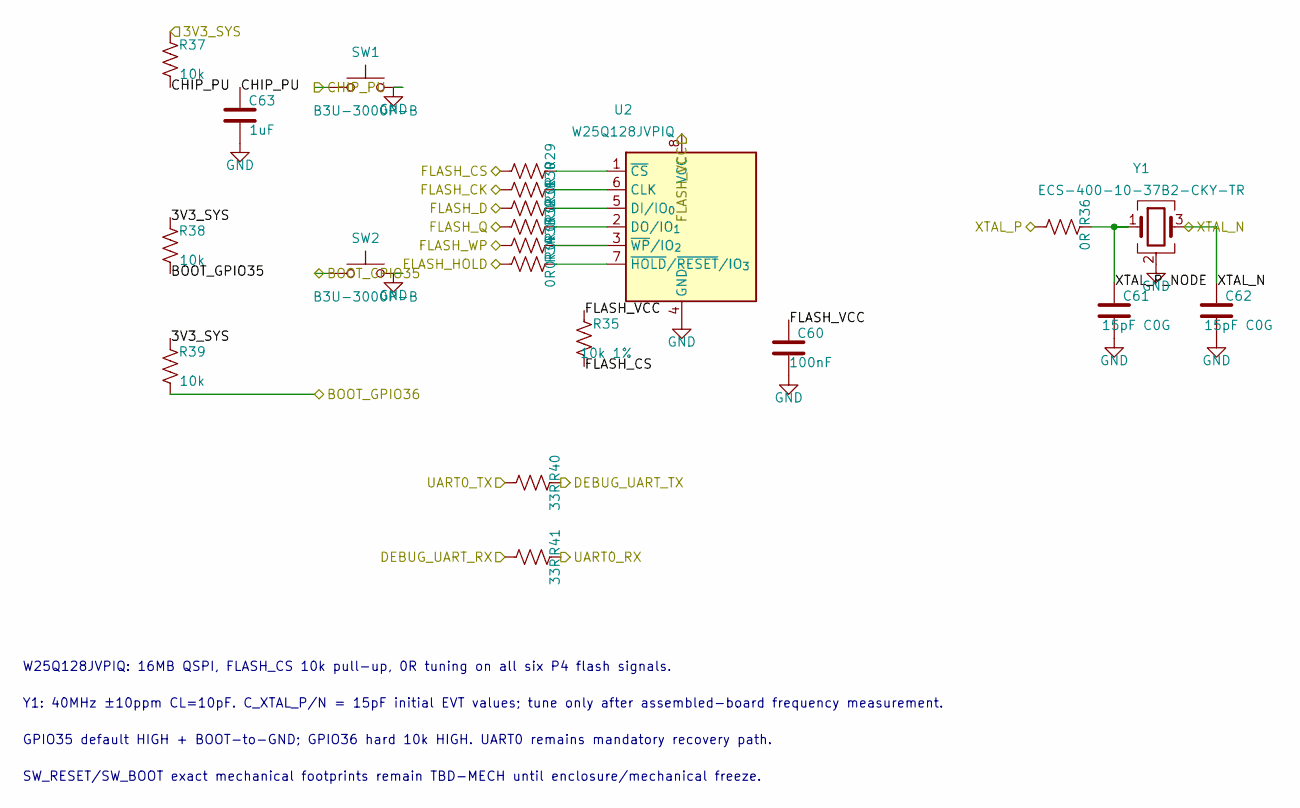
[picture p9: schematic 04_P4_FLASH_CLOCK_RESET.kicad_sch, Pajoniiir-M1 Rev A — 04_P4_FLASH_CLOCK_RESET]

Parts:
C60: 100nF; C_0603_1608Metric
C61, C62: 15pF C0G; C_0402_1005Metric
C63: 1uF; C_0603_1608Metric
R29, R30, R31, R32, R33, R34, R36: 0R; R_0402_1005Metric
R35: 10k 1%; R_0603_1608Metric
R37, R38, R39: 10k; R_0603_1608Metric
R40, R41: 33R; R_0603_1608Metric
SW1, SW2: B3U-3000P-B; SW_SPST_B3U-3000P-B
U2: W25Q128JVPIQ; WSON-8-1EP_6x5mm_P1.27mm_EP3.4x4.3mm
Y1: ECS-400-10-37B2-CKY-TR; Crystal_SMD_2016-4Pin_2.0x1.6mm

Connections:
/3V3_SYS: R37.1, R38.1, R39.1; also elsewhere on the board
/03_P4_CORE/FLASH_CK: R30.1; also elsewhere on the board
/03_P4_CORE/FLASH_D: R31.1; also elsewhere on the board
/03_P4_CORE/FLASH_HOLD: R34.1; also elsewhere on the board
/03_P4_CORE/FLASH_Q: R32.1; also elsewhere on the board
/03_P4_CORE/FLASH_VCC: C60.1, R35.1, U2.8 (VCC); also elsewhere on the board
/03_P4_CORE/FLASH_WP: R33.1; also elsewhere on the board
/04_P4_FLASH_CLOCK_RESET/FLASH_CS: R29.1, R35.2; also elsewhere on the board
/04_P4_FLASH_CLOCK_RESET/XTAL_P_NODE: C61.1, R36.2, Y1.1
/BOOT_GPIO35: R38.2, SW2.1; also elsewhere on the board
/BOOT_GPIO36: R39.2; also elsewhere on the board
/CHIP_PU: C63.1, R37.2, SW1.1; also elsewhere on the board
/DEBUG_UART_RX: R41.1; also elsewhere on the board
/DEBUG_UART_TX: R40.2; also elsewhere on the board
/UART0_RX: R41.2; also elsewhere on the board
/UART0_TX: R40.1; also elsewhere on the board
/XTAL_N: C62.1, Y1.3; also elsewhere on the board
/XTAL_P: R36.1; also elsewhere on the board
unnamed: R30.2, U2.6 (CLK)
unnamed: R31.2, U2.5 (DI/IO_{0})
unnamed: R32.2, U2.2 (DO/IO_{1})
unnamed: R29.2, U2.1 (~CS)
unnamed: R34.2, U2.7 (~HOLD/~RESET/IO_{3})
unnamed: R33.2, U2.3 (~WP/IO_{2})

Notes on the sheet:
W25Q128JVPIQ: 16MB QSPI, FLASH_CS 10k pull-up, 0R tuning on all six P4 flash signals.
Y1: 40MHz ±10ppm CL=10pF. C_XTAL_P/N = 15pF initial EVT values; tune only after assembled-board frequency measurement.
GPIO35 default HIGH + BOOT-to-GND; GPIO36 hard 10k HIGH. UART0 remains mandatory recovery path.
SW_RESET/SW_BOOT exact mechanical footprints remain TBD-MECH until enclosure/mechanical freeze.

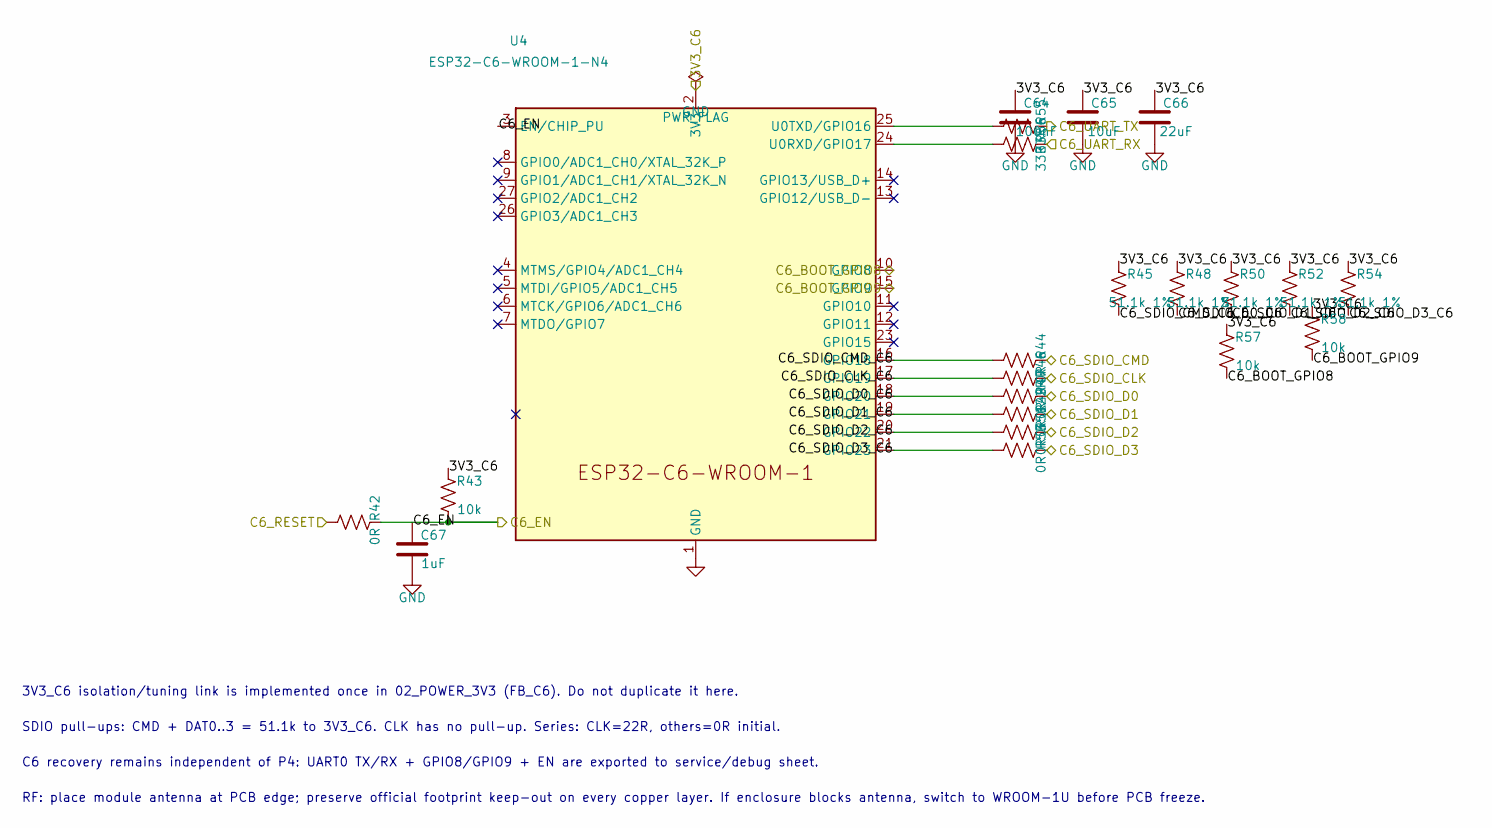
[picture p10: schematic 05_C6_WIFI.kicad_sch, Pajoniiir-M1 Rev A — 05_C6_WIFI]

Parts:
C64: 100nF; C_0603_1608Metric
C65: 10uF; C_0805_2012Metric
C66: 22uF; C_1206_3216Metric
C67: 1uF; C_0603_1608Metric
R42: 0R; R_0603_1608Metric
R43, R57, R58: 10k; R_0603_1608Metric
R44, R47, R49, R51, R53: 0R; R_0402_1005Metric
R45, R48, R50, R52, R54: 51.1k 1%; R_0603_1608Metric
R46: 22R; R_0402_1005Metric
R55, R56: 33R; R_0603_1608Metric
U4: ESP32-C6-WROOM-1-N4; ESP32-C6-WROOM-1

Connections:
/3V3_C6: C64.1, C65.1, C66.1, R43.1, R45.1, R48.1, R50.1, R52.1, R54.1, R57.1, R58.1, U4.2 (3V3); also elsewhere on the board
/05_C6_WIFI/C6_SDIO_CLK_C6: R46.1, U4.17 (GPIO19)
/05_C6_WIFI/C6_SDIO_CMD_C6: R44.1, R45.2, U4.16 (GPIO18)
/05_C6_WIFI/C6_SDIO_D0_C6: R47.1, R48.2, U4.18 (GPIO20)
/05_C6_WIFI/C6_SDIO_D1_C6: R49.1, R50.2, U4.19 (GPIO21)
/05_C6_WIFI/C6_SDIO_D2_C6: R51.1, R52.2, U4.20 (GPIO22)
/05_C6_WIFI/C6_SDIO_D3_C6: R53.1, R54.2, U4.21 (GPIO23)
/C6_BOOT_GPIO8: R57.2, U4.10 (GPIO8); also elsewhere on the board
/C6_BOOT_GPIO9: R58.2, U4.15 (GPIO9); also elsewhere on the board
/C6_EN: C67.1, R42.2, R43.2, U4.3 (EN/CHIP_PU); also elsewhere on the board
/C6_RESET: R42.1; also elsewhere on the board
/C6_SDIO_CLK: R46.2; also elsewhere on the board
/C6_SDIO_CMD: R44.2; also elsewhere on the board
/C6_SDIO_D0: R47.2; also elsewhere on the board
/C6_SDIO_D1: R49.2; also elsewhere on the board
/C6_SDIO_D2: R51.2; also elsewhere on the board
/C6_SDIO_D3: R53.2; also elsewhere on the board
/C6_UART_RX: R56.2; also elsewhere on the board
/C6_UART_TX: R55.2; also elsewhere on the board
unnamed: R56.1, U4.24 (U0RXD/GPIO17)
unnamed: R55.1, U4.25 (U0TXD/GPIO16)

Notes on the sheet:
3V3_C6 isolation/tuning link is implemented once in 02_POWER_3V3 (FB_C6). Do not duplicate it here.
SDIO pull-ups: CMD + DAT0..3 = 51.1k to 3V3_C6. CLK has no pull-up. Series: CLK=22R, others=0R initial.
C6 recovery remains independent of P4: UART0 TX/RX + GPIO8/GPIO9 + EN are exported to service/debug sheet.
RF: place module antenna at PCB edge; preserve official footprint keep-out on every copper layer. If enclosure blocks antenna, switch to WROOM-1U before PCB freeze.

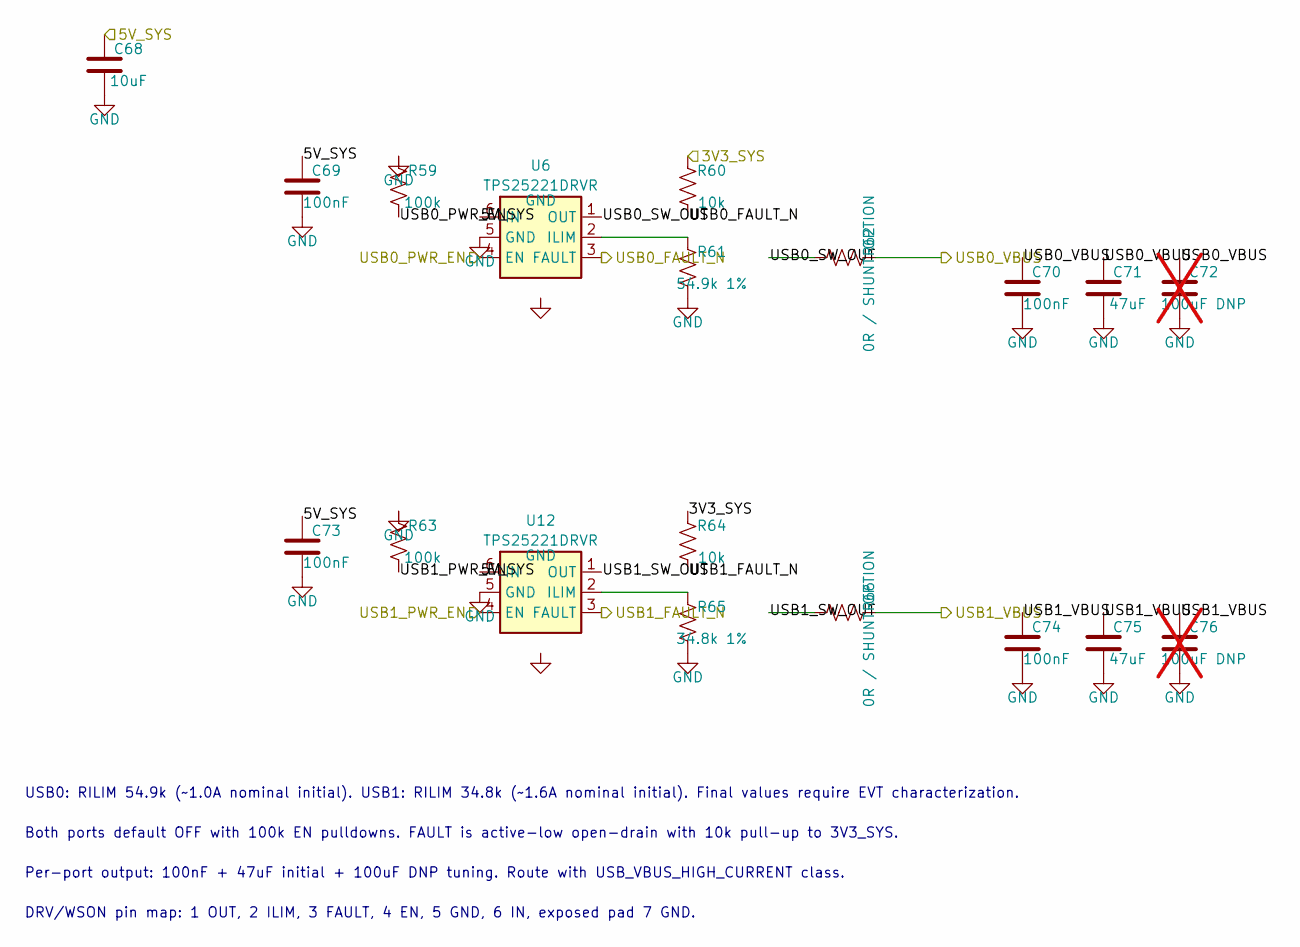
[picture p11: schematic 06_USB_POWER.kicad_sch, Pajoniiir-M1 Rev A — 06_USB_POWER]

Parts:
C68: 10uF; C_0805_2012Metric
C69, C70, C73, C74: 100nF; C_0603_1608Metric
C71, C75: 47uF; C_1210_3225Metric
C72, C76: 100uF DNP; C_1210_3225Metric; not fitted
R59, R63: 100k; R_0603_1608Metric
R60, R64: 10k; R_0603_1608Metric
R61: 54.9k 1%; R_0603_1608Metric
R62, R66: 0R / SHUNT OPTION; R_1206_3216Metric
R65: 34.8k 1%; R_0603_1608Metric
U6, U12: TPS25221DRVR; WSON-6-1EP_2x2mm_P0.65mm_EP1x1.6mm

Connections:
/3V3_SYS: R60.1, R64.1; also elsewhere on the board
/5V_SYS: C68.1, C69.1, C73.1, U6.6 (IN), U12.6 (IN); also elsewhere on the board
/06_USB_POWER/USB0_SW_OUT: R62.1, U6.1 (OUT)
/06_USB_POWER/USB1_SW_OUT: R66.1, U12.1 (OUT)
/USB0_FAULT_N: R60.2, U6.3 (FAULT); also elsewhere on the board
/USB0_PWR_EN: R59.2, U6.4 (EN); also elsewhere on the board
/USB0_VBUS: C70.1, C71.1, C72.1, R62.2; also elsewhere on the board
/USB1_FAULT_N: R64.2, U12.3 (FAULT); also elsewhere on the board
/USB1_PWR_EN: R63.2, U12.4 (EN); also elsewhere on the board
/USB1_VBUS: C74.1, C75.1, C76.1, R66.2; also elsewhere on the board
unnamed: R61.1, U6.2 (ILIM)
unnamed: R65.1, U12.2 (ILIM)

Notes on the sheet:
USB0: RILIM 54.9k (~1.0A nominal initial). USB1: RILIM 34.8k (~1.6A nominal initial). Final values require EVT characterization.
Both ports default OFF with 100k EN pulldowns. FAULT is active-low open-drain with 10k pull-up to 3V3_SYS.
Per-port output: 100nF + 47uF initial + 100uF DNP tuning. Route with USB_VBUS_HIGH_CURRENT class.
DRV/WSON pin map: 1 OUT, 2 ILIM, 3 FAULT, 4 EN, 5 GND, 6 IN, exposed pad 7 GND.

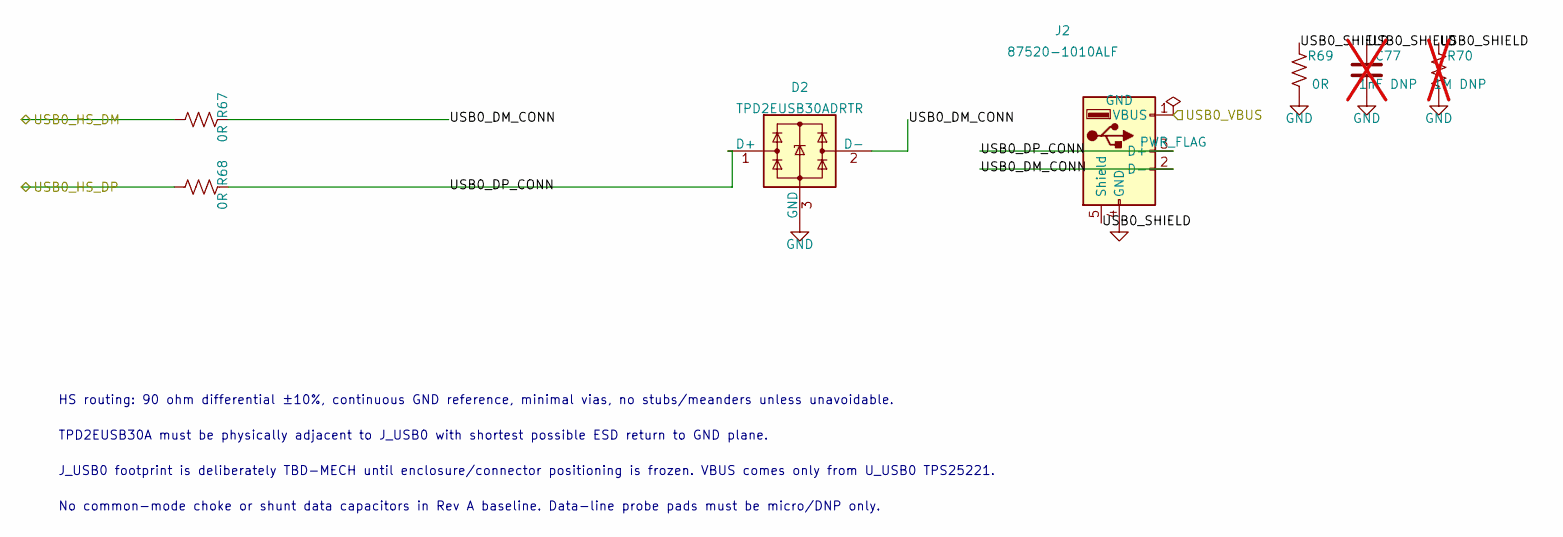
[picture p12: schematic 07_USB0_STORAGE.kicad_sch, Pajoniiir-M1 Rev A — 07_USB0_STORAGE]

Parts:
C77: 1nF DNP; C_0603_1608Metric; not fitted
D2: TPD2EUSB30ADRTR; Texas_DRT-3
J2: 87520-1010ALF; Amphenol_87520-1010ALF
R67, R68: 0R; R_0402_1005Metric
R69: 0R; R_0603_1608Metric
R70: 1M DNP; R_0603_1608Metric; not fitted

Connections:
/07_USB0_STORAGE/USB0_DM_CONN: D2.2 (D-), J2.2 (D-), R67.2
/07_USB0_STORAGE/USB0_DP_CONN: D2.1 (D+), J2.3 (D+), R68.2
/07_USB0_STORAGE/USB0_SHIELD: C77.1, J2.5 (Shield), R69.1, R70.1
/USB0_HS_DM: R67.1; also elsewhere on the board
/USB0_HS_DP: R68.1; also elsewhere on the board
/USB0_VBUS: J2.1 (VBUS); also elsewhere on the board

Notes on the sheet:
HS routing: 90 ohm differential ±10%, continuous GND reference, minimal vias, no stubs/meanders unless unavoidable.
TPD2EUSB30A must be physically adjacent to J_USB0 with shortest possible ESD return to GND plane.
J_USB0 footprint is deliberately TBD-MECH until enclosure/connector positioning is frozen. VBUS comes only from U_USB0 TPS25221.
No common-mode choke or shunt data capacitors in Rev A baseline. Data-line probe pads must be micro/DNP only.

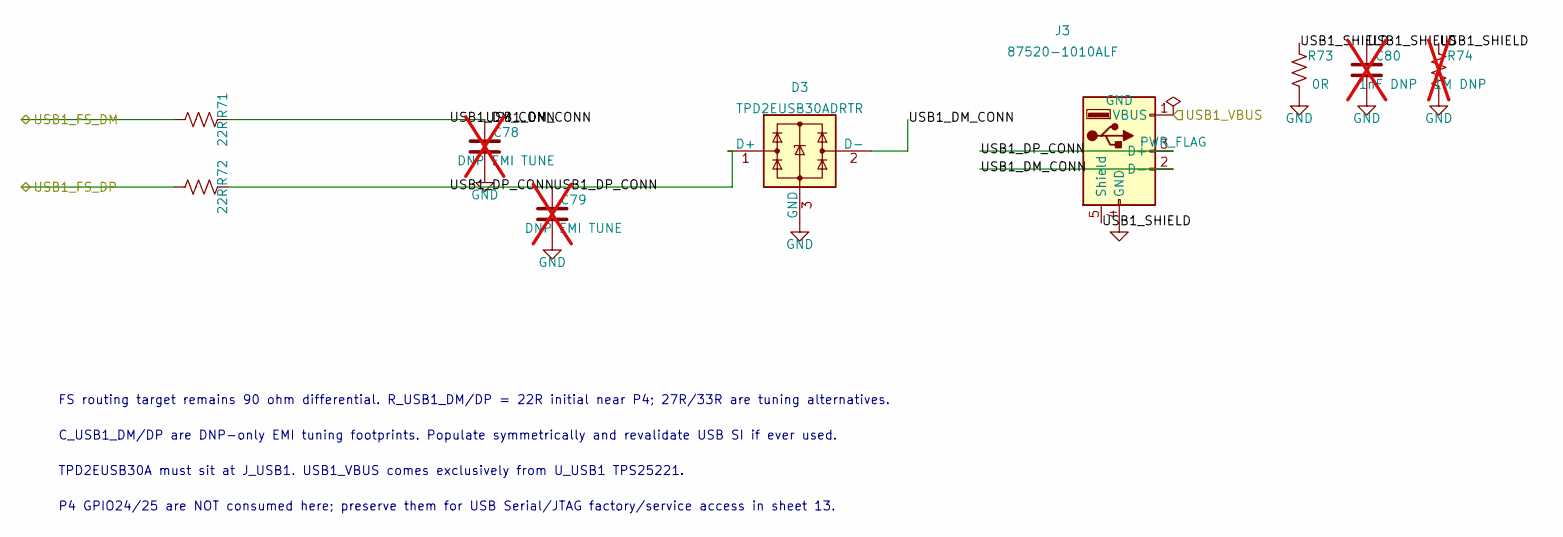
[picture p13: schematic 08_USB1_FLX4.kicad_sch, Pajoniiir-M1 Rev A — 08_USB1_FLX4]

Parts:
C78, C79: DNP EMI TUNE; C_0402_1005Metric; not fitted
C80: 1nF DNP; C_0603_1608Metric; not fitted
D3: TPD2EUSB30ADRTR; Texas_DRT-3
J3: 87520-1010ALF; Amphenol_87520-1010ALF
R71, R72: 22R; R_0402_1005Metric
R73: 0R; R_0603_1608Metric
R74: 1M DNP; R_0603_1608Metric; not fitted

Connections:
/08_USB1_FLX4/USB1_DM_CONN: C78.1, D3.2 (D-), J3.2 (D-), R71.2
/08_USB1_FLX4/USB1_DP_CONN: C79.1, D3.1 (D+), J3.3 (D+), R72.2
/08_USB1_FLX4/USB1_SHIELD: C80.1, J3.5 (Shield), R73.1, R74.1
/USB1_FS_DM: R71.1; also elsewhere on the board
/USB1_FS_DP: R72.1; also elsewhere on the board
/USB1_VBUS: J3.1 (VBUS); also elsewhere on the board

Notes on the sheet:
FS routing target remains 90 ohm differential. R_USB1_DM/DP = 22R initial near P4; 27R/33R are tuning alternatives.
C_USB1_DM/DP are DNP-only EMI tuning footprints. Populate symmetrically and revalidate USB SI if ever used.
TPD2EUSB30A must sit at J_USB1. USB1_VBUS comes exclusively from U_USB1 TPS25221.
P4 GPIO24/25 are NOT consumed here; preserve them for USB Serial/JTAG factory/service access in sheet 13.

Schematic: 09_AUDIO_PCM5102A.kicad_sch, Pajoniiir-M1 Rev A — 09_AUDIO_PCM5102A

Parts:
C81, C83, C85, C87: 10uF; C_0805_2012Metric
C82, C84, C86, C90: 100nF; C_0603_1608Metric
C88, C89: 2.2uF; C_0603_1608Metric
C91, C92: 2.2nF C0G; C_0603_1608Metric
J4: KLPX-0848A-2-W-G; Kycon_KLPX-0848A-2-x-G
J5: KLPX-0848A-2-R-G; Kycon_KLPX-0848A-2-x-G
R75, R76, R77: 22R; R_0402_1005Metric
R78: 100R; R_0603_1608Metric
R79: 100k; R_0603_1608Metric
R80, R81: 470R; R_0603_1608Metric
U5: PCM5102APWR; TSSOP-20_4.4x6.5mm_P0.65mm

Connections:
/3V3_AUDIO: C81.1, C82.1, C83.1, C84.1, C85.1, C86.1, C87.1, U5.1 (CPVDD), U5.8 (AVDD), U5.20 (DVDD); also elsewhere on the board
/09_AUDIO_PCM5102A/DAC_CAPM: C88.2, U5.4 (CAPM)
/09_AUDIO_PCM5102A/DAC_CAPP: C88.1, U5.2 (CAPP)
/09_AUDIO_PCM5102A/DAC_DATA_DAC: R76.2, U5.14 (DIN)
/09_AUDIO_PCM5102A/DAC_LDOO_1V8: C90.1, U5.18 (LDOO)
/09_AUDIO_PCM5102A/DAC_VNEG: C89.1, U5.5 (VNEG)
/09_AUDIO_PCM5102A/MAIN_L: C91.1, J4.1 (In), R80.2
/09_AUDIO_PCM5102A/MAIN_R: C92.1, J5.1 (In), R81.2
/DAC_BCLK: R77.1; also elsewhere on the board
/DAC_DATA: R76.1; also elsewhere on the board
/DAC_LRCK: R75.1; also elsewhere on the board
/DAC_XSMT: R78.1; also elsewhere on the board
unnamed: R77.2, U5.13 (BCK)
unnamed: R75.2, U5.15 (LRCK)
unnamed: R80.1, U5.6 (OUTL)
unnamed: R81.1, U5.7 (OUTR)
unnamed: R78.2, R79.1, U5.17 (XSMT)

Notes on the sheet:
PCM5102A 3-wire mode: SCK=GND; FMT=LOW (I2S); FLT=LOW; DEMP=LOW. No external MCLK is required.
XSMT defaults LOW via 100k pulldown. Firmware starts stable BCLK/LRCK/DATA, waits, then drives DAC_XSMT HIGH.
Single 3V3_AUDIO supply for CPVDD/DVDD/AVDD. LDOO is an internal ~1.8V output and is decoupled only.
MAIN_L/R are ground-centered DirectPath line outputs: 470R + 2.2nF, no series DC-block capacitors.
RCA J4/J5 Kycon KLPX-0848A gold-family footprints are locked; final panel XY/cutouts remain open. J6 / 3.5mm line-out was removed from Rev A in M1-MECH-A8; CUE/headphones remain via FLX4 USB Audio.

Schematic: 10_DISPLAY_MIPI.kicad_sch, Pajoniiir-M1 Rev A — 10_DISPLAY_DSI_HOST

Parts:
C93: 100nF; C_0603_1608Metric
C94: 10uF; C_0805_2012Metric
FB3: 0R / ferrite option; R_0603_1608Metric
J6: 15-pin Raspberry-Pi-style DSI host; Amphenol_SFW15R-2STE1LF
R82, R83, R84, R85, R86, R87: 0R; R_0201_0603Metric
R95, R96: 22R; R_0402_1005Metric
R97, R98: 4.7k; R_0603_1608Metric
R99, R100: 4.7k DNP; R_0603_1608Metric; not fitted
TP1: 3V3_DISPLAY_MODULE; TestPoint_Pad_D1.5mm
TP2: P4_LDO_MIPI_2V5; TestPoint_Pad_D1.5mm
TP9: J6_I2C_SDA; TestPoint_Pad_D1.5mm
TP10: J6_I2C_SCL; TestPoint_Pad_D1.5mm

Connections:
/3V3_SYS: FB3.1; also elsewhere on the board
/10_DISPLAY_MIPI/3V3_DISPLAY_MODULE: C93.1, C94.1, FB3.2, J6.14 (3V3), J6.15 (3V3), R97.1, R98.1, R99.1, R100.1, TP1.1
/10_DISPLAY_MIPI/J6_DSI_CLK_N: J6.5 (DSI_CLK_N), R87.2
/10_DISPLAY_MIPI/J6_DSI_CLK_P: J6.6 (DSI_CLK_P), R86.2
/10_DISPLAY_MIPI/J6_DSI_D0_N: J6.8 (DSI_D0_N), R83.2
/10_DISPLAY_MIPI/J6_DSI_D0_P: J6.9 (DSI_D0_P), R82.2
/10_DISPLAY_MIPI/J6_DSI_D1_N: J6.2 (DSI_D1_N), R85.2
/10_DISPLAY_MIPI/J6_DSI_D1_P: J6.3 (DSI_D1_P), R84.2
/10_DISPLAY_MIPI/J6_I2C_SCL: J6.11 (I2C_SCL), R96.2, R98.2, R100.2, TP10.1
/10_DISPLAY_MIPI/J6_I2C_SDA: J6.12 (I2C_SDA), R95.2, R97.2, R99.2, TP9.1
/DISPLAY_I2C_SCL: R96.1; also elsewhere on the board
/DISPLAY_I2C_SDA: R95.1; also elsewhere on the board
/DSI_CLK_N: R87.1; also elsewhere on the board
/DSI_CLK_P: R86.1; also elsewhere on the board
/DSI_D0_N: R83.1; also elsewhere on the board
/DSI_D0_P: R82.1; also elsewhere on the board
/DSI_D1_N: R85.1; also elsewhere on the board
/DSI_D1_P: R84.1; also elsewhere on the board
/P4_LDO_MIPI_2V5: TP2.1; also elsewhere on the board

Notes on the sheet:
DISPLAY INTERFACE: generic 15-pin Raspberry-Pi-style DSI host. DSI506/DYL0023 is one validated profile.
J6 = Amphenol SFW15R-2STE1LF, 15P 1.0mm TOP contact. Locked host map: GND/D1/CLK/D0/I2C/3V3.
DSI506 PROFILE: panel power/backlight 0x45; touch 0x38 at 100kHz. Other displays require a qualified profile.
DSI506 PROFILE: 1 lane @ 800Mbps, RGB888, 27.777MHz, H 59/2/45, V 109/2/22; both physical lanes are routed.
DSI routing target 100R differential; MIPI DPHY 2.5V LDO and 4.02k DSI_REXT remain in 03_P4_CORE.

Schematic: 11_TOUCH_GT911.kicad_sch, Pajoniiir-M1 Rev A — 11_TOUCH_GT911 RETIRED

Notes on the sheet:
M1-ELEC-B2/B7: separate GT911 hardware retired. Touch is supplied by the selected DSI display profile over shared I2C; DSI506 uses 0x38.
GPIO7/8 I2C conditioning, pull-ups and test points moved into 10_DISPLAY_MIPI next to final J8 connector.
GPIO3 TOUCH_RST and GPIO4 TOUCH_INT are released/NC in final M1 architecture.

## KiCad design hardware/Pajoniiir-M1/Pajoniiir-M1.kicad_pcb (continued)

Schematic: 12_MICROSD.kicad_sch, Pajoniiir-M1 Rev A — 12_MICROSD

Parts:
C101, C104: 100nF; C_0603_1608Metric
C102: 1uF; C_0603_1608Metric
C103: 470pF >=25V; C_0402_1005Metric
C105: 10uF; C_0805_2012Metric
C106: 22uF DNP; C_1206_3216Metric; not fitted
C107: DNP SI TUNE; C_0402_1005Metric; not fitted
J7: 503398-1892; Molex_503398-1892
R104: 100k; R_0603_1608Metric
R105: 100R; R_0603_1608Metric
R106, R107, R108, R110, R111: 0R; R_0402_1005Metric
R109: 22R; R_0402_1005Metric
R112, R113, R114, R115, R116, R117: 10k; R_0603_1608Metric
U13: TPS22918DBVR; SOT-23-6

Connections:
/3V3_SYS: C101.1, C102.1, R117.1, U13.1 (VIN); also elsewhere on the board
/12_MICROSD/3V3_SD: C104.1, C105.1, C106.1, J7.4 (VDD), R105.2, R112.1, R113.1, R114.1, R115.1, R116.1, U13.6 (VOUT)
/12_MICROSD/SD_CLK_CARD: C107.1, J7.5 (CLK), R109.2
/12_MICROSD/SD_CMD_CARD: J7.3 (CMD), R108.2, R114.2
/12_MICROSD/SD_D0_CARD: J7.7 (DAT0), R110.2, R115.2
/12_MICROSD/SD_D1_CARD: J7.8 (DAT1), R111.2, R116.2
/12_MICROSD/SD_D2_CARD: J7.1 (DAT2), R106.2, R112.2
/12_MICROSD/SD_D3_CARD: J7.2 (DAT3/CD), R107.2, R113.2
/SDMMC_CLK: R109.1; also elsewhere on the board
/SDMMC_CMD: R108.1; also elsewhere on the board
/SDMMC_D0: R110.1; also elsewhere on the board
/SDMMC_D1: R111.1; also elsewhere on the board
/SDMMC_D2: R106.1; also elsewhere on the board
/SDMMC_D3: R107.1; also elsewhere on the board
/SD_CARD_DETECT: J7.9 (DET), R117.2; also elsewhere on the board
/SD_PWR_EN: R104.2, U13.3 (ON); also elsewhere on the board
unnamed: C103.1, U13.4 (CT)
unnamed: R105.1, U13.5 (QOD)

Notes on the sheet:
SDMMC0 fixed IO-MUX: GPIO39 D0, GPIO40 D1, GPIO41 D2, GPIO42 D3, GPIO43 CLK, GPIO44 CMD.
TPS22918: SD rail defaults OFF. CT=470pF initial; QOD=100R initial; 3V3_SD must fully discharge for true card reset.
CMD/D0..D3 pull-ups are 10k to switched 3V3_SD. CLK has no pull-up; CLK series=22R and a DNP shunt-C tuning footprint.
Before SD power-off firmware must stop SDMMC and make GPIO39-44 high-Z to prevent back-power through card I/O protection.
J_SD footprint and low-cap multi-line ESD array remain TBD. Socket shield is direct GND; card-detect is active-low when supported.

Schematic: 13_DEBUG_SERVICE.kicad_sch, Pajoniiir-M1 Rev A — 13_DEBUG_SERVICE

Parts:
C108, C109: DNP EMI TUNE; C_0402_1005Metric; not fitted
J8: P4 DEBUG TC2030-NL DNL; Tag-Connect_TC2030-IDC-NL_2x03_P1.27mm_Vertical; not fitted
J9: P4 USB SERIAL/JTAG FACTORY POGO DNL; Factory_Pogo_USBJTAG_1x05_P1.27_2Tooling; not fitted
J10: C6 DEBUG TC2030-NL DNL; Tag-Connect_TC2030-IDC-NL_2x03_P1.27mm_Vertical; not fitted
R118, R119: 22R; R_0402_1005Metric
TP13: BOOT_GPIO36; TestPoint_Pad_D1.5mm
TP14: C6_BOOT_GPIO8; TestPoint_Pad_D1.5mm
TP15: DEBUG_UART_TX; TestPoint_Pad_D1.5mm
TP16: DEBUG_UART_RX; TestPoint_Pad_D1.5mm
TP17: CHIP_PU; TestPoint_Pad_D1.5mm
TP18: USBJTAG_DM_SERVICE; TestPoint_Pad_D1.5mm
TP19: USBJTAG_DP_SERVICE; TestPoint_Pad_D1.5mm
TP20: C6_EN; TestPoint_Pad_D1.5mm

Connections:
/3V3_C6: J10.5; also elsewhere on the board
/3V3_SYS: J8.5, J9.5; also elsewhere on the board
/13_DEBUG_SERVICE/USBJTAG_DM_SERVICE: C108.1, J9.3, R118.2, TP18.1
/13_DEBUG_SERVICE/USBJTAG_DP_SERVICE: C109.1, J9.2, R119.2, TP19.1
/BOOT_GPIO35: J8.2; also elsewhere on the board
/BOOT_GPIO36: TP13.1; also elsewhere on the board
/C6_BOOT_GPIO8: TP14.1; also elsewhere on the board
/C6_BOOT_GPIO9: J10.2; also elsewhere on the board
/C6_EN: J10.4, TP20.1; also elsewhere on the board
/C6_UART_RX: J10.3; also elsewhere on the board
/C6_UART_TX: J10.6; also elsewhere on the board
/CHIP_PU: J8.4, J9.1, TP17.1; also elsewhere on the board
/DEBUG_UART_RX: J8.3, TP16.1; also elsewhere on the board
/DEBUG_UART_TX: J8.6, TP15.1; also elsewhere on the board
/P4_USBJTAG_DM: R118.1; also elsewhere on the board
/P4_USBJTAG_DP: R119.1; also elsewhere on the board

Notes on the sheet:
JDBG_P4 and JDBG_C6 are no-parts Tag-Connect footprints (DNL). Pin-1 VREF is sense/reference only, never a board power input.
P4 UART conditioning is already in sheet 04; C6 UART conditioning is already in sheet 05. Do not duplicate those series resistors here.
P4 USB Serial/JTAG uses GPIO24/25 through 22R/22R. DNP shunt capacitors are symmetrical tuning-only footprints.
Factory recovery is independent of display/Wi-Fi/application firmware: P4 UART0, P4 USB Serial/JTAG and C6 UART/boot all remain accessible.

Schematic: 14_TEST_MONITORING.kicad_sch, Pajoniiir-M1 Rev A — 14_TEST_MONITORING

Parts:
C110, C111: 100nF; C_0603_1608Metric
C112: 1uF; C_0603_1608Metric
R120: WSK25125L000FEA / 5mR 1% 1W; R_Shunt_Vishay_WSK2512_6332Metric_T1.19mm
R121, R122: 10R; R_0603_1608Metric
R123: 10k; R_0603_1608Metric
TP21: 5V_PROTECTED; TestPoint_Pad_D1.5mm
TP22: 5V_SYS; TestPoint_Pad_D1.5mm
TP23: 3V3_SYS; TestPoint_Pad_D1.5mm
TP24: SYS_POWER_ALERT_N; TestPoint_Pad_D1.5mm
U14: INA238AIDGSR; Texas_DGS0010A_VSSOP-10_3x3mm_P0.5mm

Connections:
/3V3_SYS: C111.1, C112.1, R123.1, TP23.1, U14.6 (VS); also elsewhere on the board
/5V_PROTECTED: R120.1, R121.1, TP21.1; also elsewhere on the board
/5V_SYS: R120.2, R122.1, TP22.1, U14.8 (Vbus); also elsewhere on the board
/14_TEST_MONITORING/INA_INN_FILT: C110.2, R122.2, U14.9 (Vin-)
/14_TEST_MONITORING/INA_INP_FILT: C110.1, R121.2, U14.10 (Vin+)
/DISPLAY_I2C_SCL: U14.5 (SCL); also elsewhere on the board
/DISPLAY_I2C_SDA: U14.4 (SDA); also elsewhere on the board
/SYS_POWER_ALERT_N: R123.2, TP24.1, U14.3 (~Alert); also elsewhere on the board

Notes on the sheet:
R_SYS_SHUNT = WSK25125L000FEA, 5mR 1% 1W, 4-terminal/Kelvin. At 4.5A: 22.5mV, ~101mW.
INA238 address 0x40: A0=A1=GND. VBUS senses load-side 5V_SYS; IN+ = supply-side Kelvin, IN- = load-side Kelvin.
Input filter: 10R + 10R and 100nF differential. Do not route sense traces on shared high-current copper; take Kelvin taps at shunt pads.
Cost-down: U_MON/filter/ALERT may be DNP, but R_SYS_SHUNT must remain or be replaced by footprint-compatible 0R high-current jumper.
Shared I2C uses existing bus pull-ups; do not add another strong pull-up pair on this sheet.

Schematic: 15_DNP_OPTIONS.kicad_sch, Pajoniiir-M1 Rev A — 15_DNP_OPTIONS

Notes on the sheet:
ASSEMBLY POLICY
Functional DNP/tuning footprints live on their owning sheets. This sheet is control documentation only.
POWER
01: input bulk alternatives = DNP tuning; 02: FB_C6 / FB_AUDIO are 0R defaults with ferrite option; 10: FB_LCD; 11: FB_TOUCH.
14: INA238 is POP for EVT/DVT and may become DNP in production. R_SYS_SHUNT must remain populated or be replaced by approved footprint-compatible 0R jumper.
USB0 HIGH-SPEED
R_USB0_DM/DP = 0R POP tuning. C_USB0_OUT_OPT = 100uF DNP. Shield 1nF + 1M options DNP. No CMC in Rev A baseline.
USB1 FULL-SPEED
R_USB1_DM/DP = 22R POP initial. C_USB1_DM/DP = DNP EMI tuning. C_USB1_OUT_OPT = 100uF DNP. Shield 1nF + 1M options DNP.
FLASH / CLOCK
QSPI series 0R tuning footprints POP. Crystal load values are assembly-selection values, not simultaneously populated alternatives.
AUDIO
J_LINE_35 = DNP optional line-level output. No headphone amp, speaker amp, ES8311, microphone or legacy monitor-I2S DNP footprints.
DISPLAY / TOUCH
10: DSI six inline 0R = POP. R_LCD_TE_SER = DNP. No external MIPI ESD baseline. Physical J_LCD footprint remains BLOCKED, not DNP.
11: R_TOUCH_SDA_PU2 / R_TOUCH_SCL_PU2 = DNP pull-up tuning. Optional touch ESD remains uninstantiated until enclosure exposure requires it.
MICROSD
C_SD_OUT_OPT = 22uF DNP. C_SD_CLK_TUNE = DNP SI tuning. Optional low-C SD ESD waits for final socket/layout. TPS22918 is mandatory POP.
DEBUG / FACTORY
JDBG_P4 and JDBG_C6 = DNL Tag-Connect PCB pads. JDBG_USB = DNL pogo footprint. C_P4_USBJTAG_DM/DP = DNP tuning.
PROHIBITED LEGACY FOOTPRINTS
NO ESP32-S3
NO ES8311
NO speaker amplifier / speaker connector
NO analog microphone
NO MAX485 / RS485
NO MIPI CSI camera block
NO P4<->S3 legacy UART bridge
NO legacy monitor I2S bridge
NO battery charger / IP5306 baseline
NO generic large expansion header
VARIANT INTENT
EVT: populate INA238; expose all tuning/test infrastructure; debug fixtures remain DNL pads.
DVT: retain telemetry and selected tuning values; validate EMI/SI/thermal margins and decide cost-down.
PROD: only validated tuning values; optional telemetry decision after DVT; no open main power path allowed.
HARD GATES BEFORE PCB FREEZE
1. Authoritative LCD panel MPN + FPC pin order + pitch/contact-side + 30-vs-32 resolution.
2. Exact USB-A mechanical connector MPNs / board-edge placement.
3. Exact microSD socket MPN / card-detect mechanics.
4. RCA / optional 3.5mm mechanical MPNs and enclosure datum.

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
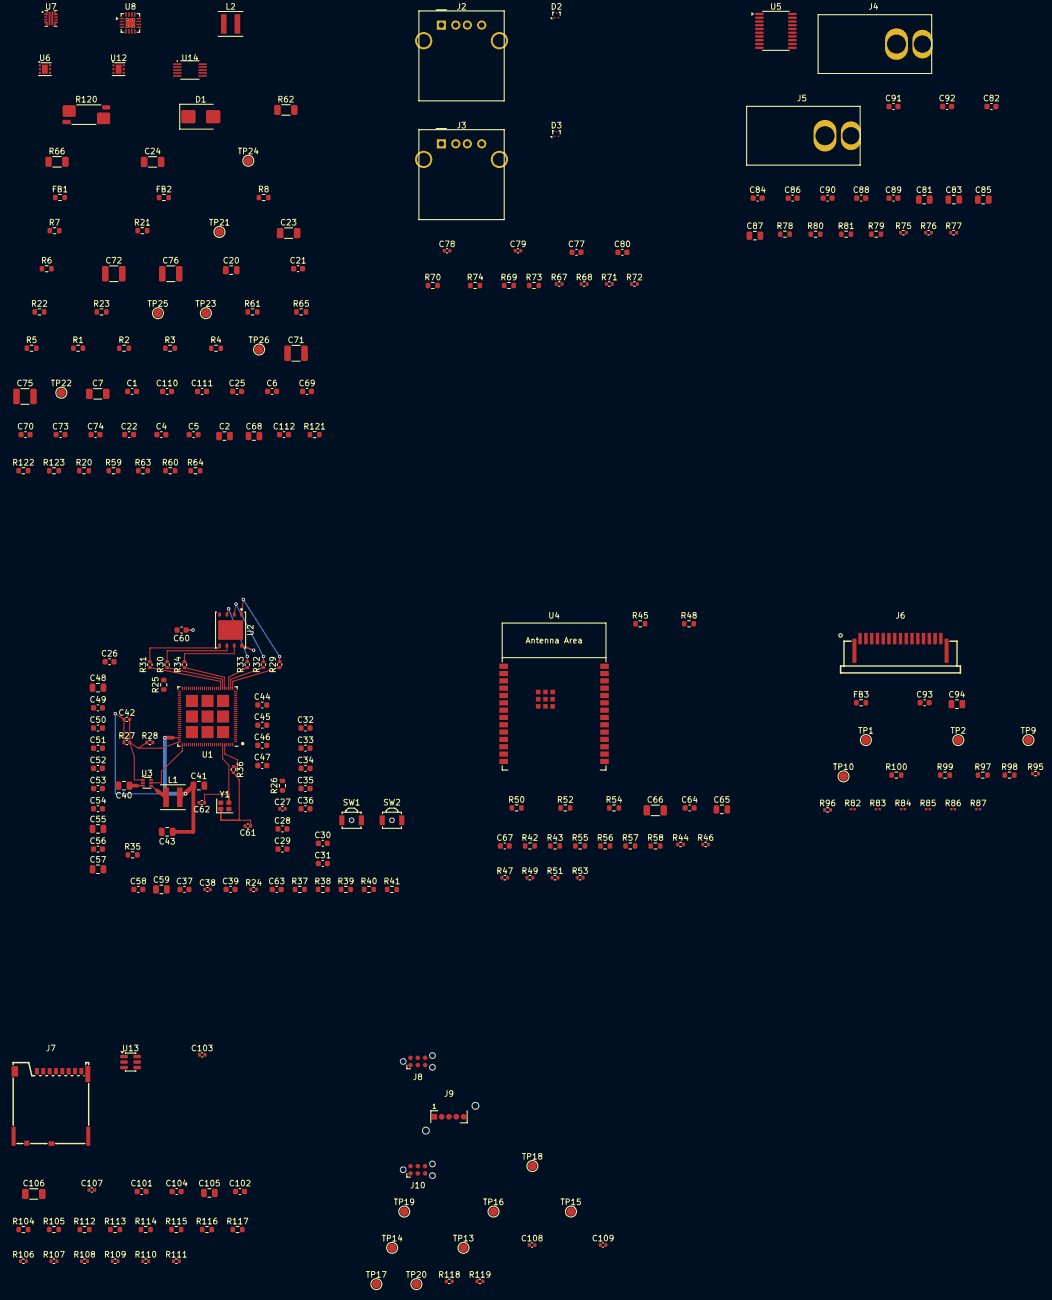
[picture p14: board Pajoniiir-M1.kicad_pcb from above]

Board: 4 copper layers, 244 parts (0 on the bottom side), 149 nets.

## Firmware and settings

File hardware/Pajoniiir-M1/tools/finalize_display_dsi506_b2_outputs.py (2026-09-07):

#!/usr/bin/env python3
"""Finalize deterministic M1-ELEC-B2 outputs before structural/KiCad validation.

This script applies only contract-normalization fixes discovered by full post-migration
structural audits. It is intentionally fail-closed and idempotent.
"""
from __future__ import annotations

from pathlib import Path
import json
import re

B = Path(__file__).resolve().parents[1]
P10 = B / "10_DISPLAY_MIPI.kicad_sch"
P11 = B / "11_TOUCH_GT911.kicad_sch"
P14 = B / "14_TEST_MONITORING.kicad_sch"
VAL = B / "tools/validate_schematic_structure.py"
MIG = B / "tools/migrate_display_dsi506_b2.py"
GATES = B / "mechanical_gates.json"
FD = B / "display_compatibility_dsi506.json"
DC = B / "display_connector_b1.json"


def sexpr_at(text: str, start: int) -> tuple[str, int]:
    depth = 0
    in_string = False
    escaped = False
    begun = False
    for i in range(start, len(text)):
        ch = text[i]
        if in_string:
            if escaped:
                escaped = False
                continue
            if ch == "\\":
                escaped = True
                continue
            if ch == '"':
                in_string = False
            continue
        if ch == '"':
            in_string = True
            continue
        if ch == "(":
            depth += 1
            begun = True
        elif ch == ")":
            depth -= 1
            if begun and depth == 0:
                return text[start : i + 1], i + 1
    raise ValueError(f"unterminated S-expression at {start}")


def instantiated_symbol_blocks(text: str):
    pos = 0
    while True:
        pos = text.find("  (symbol", pos)
        if pos < 0:
            return
        block, end = sexpr_at(text, pos)
        if '(lib_id "' in block:
            yield block
        pos = end


def left_justify_top_text(path: Path) -> None:
    text = path.read_text()
    needle = "\n  (text "
    pos = 0
    replacements: list[tuple[int, int, str]] = []
    while True:
        found = text.find(needle, pos)
        if found < 0:
            break
        start = found + 1
        block, end = sexpr_at(text, start)
        if "(justify left)" not in block:
            old = "(effects (font (size 1.27 1.27)))"
            if old not in block:
                raise SystemExit(f"{path.name}: top-level note has unexpected effects syntax")
            block = block.replace(
                old,
                "(effects (font (size 1.27 1.27)) (justify left))",
                1,
            )
            replacements.append((start, end, block))
        pos = end
    for start, end, block in reversed(replacements):
        text = text[:start] + block + text[end:]
    path.write_text(text)


def recursive_replace(value, old: str, new: str):
    if isinstance(value, str):
        return value.replace(old, new)
    if isinstance(value, list):
        return [recursive_replace(v, old, new) for v in value]
    if isinstance(value, dict):
        return {k: recursive_replace(v, old, new) for k, v in value.items()}
    return value


def used_connector_refs_excluding_display() -> set[str]:
    refs: set[str] = set()
    for path in sorted(B.glob("[0-9][0-9]_*.kicad_sch")):
        if path == P10:
            continue
        text = path.read_text()
        for block in instantiated_symbol_blocks(text):
            match = re.search(r'\(property "Reference" "(J\d+)"', block)
            if match:
                refs.add(match.group(1))
    return refs


def allocate_display_ref() -> tuple[str, str]:
    p10 = P10.read_text()
    display_block = None
    for block in instantiated_symbol_blocks(p10):
        if "DSI506 / DYL0023 15-pin DSI" in block:
            display_block = block
            break
    if not display_block:
        raise SystemExit("10_DISPLAY_MIPI: DSI506 production connector instance missing")
    match = re.search(r'\(property "Reference" "(J\d+)"', display_block)
    if not match:
        raise SystemExit("10_DISPLAY_MIPI: DSI506 connector RefDes missing")
    old_ref = match.group(1)

    used = used_connector_refs_excluding_display()
    free_ref = next((f"J{i}" for i in range(1, 100) if f"J{i}" not in used), None)
    if free_ref is None:
        raise SystemExit("no free J1..J99 RefDes available for final display connector")

    # Internal connector-side net names intentionally share the RefDes prefix.
    p10 = p10.replace(old_ref, free_ref)
    P10.write_text(p10)

    for path in (GATES, FD, DC):
        data = json.loads(path.read_text())
        data = recursive_replace(data, old_ref, free_ref)
        path.write_text(json.dumps(data, indent=2) + "\n")

    print(f"PASS: display connector RefDes {old_ref} -> {free_ref}; occupied={sorted(used)}")
    return old_ref, free_ref


def normalize_test_monitoring_i2c() -> None:
    text = P14.read_text()
    text = text.replace('"I2C_SDA"', '"DISPLAY_I2C_SDA"')
    text = text.replace('"I2C_SCL"', '"DISPLAY_I2C_SCL"')
    P14.write_text(text)


def normalize_validator(old_ref: str, display_ref: str) -> None:
    text = VAL.read_text()
    # Generated B2 display contract follows the dynamically allocated RefDes.
    text = text.replace(f'final DSI506 {old_ref} connector missing', f'final DSI506 {display_ref} connector missing')
    text = text.replace(f'(property "Reference" "{old_ref}"', f'(property "Reference" "{display_ref}"')
    # Cover earlier failed-run literals if they appear in the generated contract text.
    for stale in ("J8", "J10"):
        if stale != display_ref:
            text = text.replace(f"final DSI506 {stale} connector missing", f"final DSI506 {display_ref} connector missing")

    old = '''            expected_unit2 = {
                "TOUCH_RST": "GPIO3",
                "TOUCH_INT": "GPIO4",
                "LCD_RST": "GPIO5",
                "LCD_TE": "GPIO6",
                "I2C_SDA": "GPIO7",
                "I2C_SCL": "GPIO8",'''
    new = '''            expected_unit2 = {
                "DISPLAY_I2C_SDA": "GPIO7",
                "DISPLAY_I2C_SCL": "GPIO8",'''
    if old in text:
        text = text.replace(old, new, 1)
    elif '"DISPLAY_I2C_SDA": "GPIO7"' not in text:
        raise SystemExit("validator: expected unit-2 mapping preamble not found")

    # GPIO23 is released with the other legacy dedicated panel-control pins.
    text = text.replace('                "LCD_BL_PWM": "GPIO23/ADC1_CHANNEL7",\n', "")

    old = '''                    "GPIO0", "GPIO1", "GPIO2",
                    "GPIO9", "GPIO10", "GPIO11", "GPIO12", "GPIO13",'''
    new = '''                    "GPIO0", "GPIO1", "GPIO2",
                    "GPIO3", "GPIO4", "GPIO5", "GPIO6",
                    "GPIO9", "GPIO10", "GPIO11", "GPIO12", "GPIO13",
                    "GPIO23/ADC1_CHANNEL7",'''
    if old in text:
        text = text.replace(old, new, 1)
    else:
        unused = text.split("unused_unit2 =", 1)[1].split("}", 1)[0]
        for required in ("GPIO3", "GPIO4", "GPIO5", "GPIO6", "GPIO23/ADC1_CHANNEL7"):
            if f'"{required}"' not in unused:
                raise SystemExit(f"validator: released {required} missing from unused unit-2 set")

    VAL.write_text(text)


def normalize_migrator_source_for_reproducibility(old_ref: str, display_ref: str) -> None:
    text = MIG.read_text()
    text = text.replace(old_ref, display_ref)

    # Future migrations must emit left-justified notes directly.
    note_expr = "(exclude_from_sim no) (at 145 {135+i*5} 0) {EFF}"
    note_repl = "(exclude_from_sim no) (at 145 {135+i*5} 0) (effects (font (size 1.27 1.27)) (justify left))"
    text = text.replace(note_expr, note_repl)
    for stub in ("stub1", "stub2", "stub3"):
        text = text.replace(
            f'{{EFF}} (uuid "{{U(\'{stub}\')}}")',
            f'(effects (font (size 1.27 1.27)) (justify left)) (uuid "{{U(\'{stub}\')}}")',
        )
    MIG.write_text(text)


def assert_contracts(display_ref: str) -> None:
    p10 = P10.read_text()
    p11 = P11.read_text()
    p14 = P14.read_text()
    val = VAL.read_text()
    used = used_connector_refs_excluding_display()

    if f'(property "Reference" "{display_ref}"' not in p10:
        raise SystemExit(f"final {display_ref} connector not instantiated")
    if display_ref in used:
        raise SystemExit(f"display RefDes collision remains: {display_ref}")
    if '"I2C_SDA"' in p14 or '"I2C_SCL"' in p14:
        raise SystemExit("14_TEST_MONITORING still exports legacy I2C names")
    for path, text in ((P10, p10), (P11, p11)):
        for match in re.finditer(r'\n  \(text ', text):
            block, _ = sexpr_at(text, match.start() + 1)
            if "(justify left)" not in block:
                raise SystemExit(f"{path.name}: non-left-justified engineering note remains")
    for required in (
        '"DISPLAY_I2C_SDA": "GPIO7"',
        '"DISPLAY_I2C_SCL": "GPIO8"',
        '"GPIO3", "GPIO4", "GPIO5", "GPIO6"',
        '"GPIO23/ADC1_CHANNEL7"',
    ):
        if required not in val:
            raise SystemExit(f"validator missing B2 GPIO contract token: {required}")
    if '"LCD_BL_PWM": "GPIO23/ADC1_CHANNEL7"' in val:
        raise SystemExit("validator still treats released GPIO23 as LCD_BL_PWM")


def main() -> None:
    old_ref, display_ref = allocate_display_ref()
    left_justify_top_text(P10)
    left_justify_top_text(P11)
    normalize_test_monitoring_i2c()
    normalize_validator(old_ref, display_ref)
    normalize_migrator_source_for_reproducibility(old_ref, display_ref)
    assert_contracts(display_ref)
    print("PASS: B2 output finalization complete")
    print(f"PASS: {display_ref} unique; display I2C aligned; GPIO3/4/5/6/23 explicit NC")


if __name__ == "__main__":
    main()

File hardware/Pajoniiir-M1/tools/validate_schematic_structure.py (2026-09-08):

#!/usr/bin/env python3
"""Lightweight structural validator for Pajoniiir-M1 KiCad schematic sources.

This is intentionally NOT a replacement for native KiCad ERC.
It catches hierarchy/source-control regressions without requiring kicad-cli.
"""

from __future__ import annotations

import json
import re
import sys
from collections import Counter, defaultdict
from pathlib import Path

BASE = Path(__file__).resolve().parents[1]
ROOT = BASE / "Pajoniiir-M1.kicad_sch"
PROJECT = BASE / "Pajoniiir-M1.kicad_pro"
RPW0010A_FOOTPRINT = BASE / "libraries" / "footprints.pretty" / "Texas_RPW0010A_VQFN-HR-10_2x2mm.kicad_mod"
CHILDREN = [
    "01_POWER_INPUT",
    "02_POWER_3V3",
    "03_P4_CORE",
    "04_P4_FLASH_CLOCK_RESET",
    "05_C6_WIFI",
    "06_USB_POWER",
    "07_USB0_STORAGE",
    "08_USB1_FLX4",
    "09_AUDIO_PCM5102A",
    "10_DISPLAY_MIPI",
    "11_TOUCH_GT911",
    "12_MICROSD",
    "13_DEBUG_SERVICE",
    "14_TEST_MONITORING",
    "15_DNP_OPTIONS",
]

MECHANICAL_GATES = BASE / "mechanical_gates.json"
PCB_CONSTRAINTS = BASE / "pcb_constraints.json"
PCB = BASE / "Pajoniiir-M1.kicad_pcb"
MECH_A = BASE / "mech_a.json"

BANNED_LEGACY_VALUE_PATTERNS = (
    "ESP32-S3",
    "ES8311",
    "MAX485",
    "NS4150",
)

def balanced_sexpr(text: str) -> tuple[int, int]:
    depth = 0
    minimum = 0
    in_string = False
    escaped = False
    for ch in text:
        if in_string:
            if escaped:
                escaped = False
                continue
            if ch == "\\":
                escaped = True
                continue
            if ch == '"':
                in_string = False
            continue
        if ch == '"':
            in_string = True
        elif ch == "(":
            depth += 1
        elif ch == ")":
            depth -= 1
            minimum = min(minimum, depth)
    return depth, minimum

def sexpr_at(text: str, start: int) -> tuple[str, int]:
    depth = 0
    in_string = False
    escaped = False
    begun = False
    for i in range(start, len(text)):
        ch = text[i]
        if in_string:
            if escaped:
                escaped = False
                continue
            if ch == "\\":
                escaped = True
                continue
            if ch == '"':
                in_string = False
            continue
        if ch == '"':
            in_string = True
            continue
        if ch == "(":
            depth += 1
            begun = True
        elif ch == ")":
            depth -= 1
            if begun and depth == 0:
                return text[start : i + 1], i + 1
    raise ValueError(f"unterminated S-expression at offset {start}")

def sheet_blocks(root_text: str) -> dict[str, str]:
    out: dict[str, str] = {}
    pos = 0
    while True:
        pos = root_text.find("  (sheet", pos)
        if pos < 0:
            break
        block, end = sexpr_at(root_text, pos)
        m = re.search(r'\(property "Sheetname" "([^"]+)"', block)
        if m:
            out[m.group(1)] = block
        pos = end
    return out

def top_level_blocks(text: str, token: str):
    """Yield top-level schematic S-expressions with the requested token."""
    needle = f"\n  ({token}"
    pos = 0
    while True:
        found = text.find(needle, pos)
        if found < 0:
            return
        start = found + 1
        block, end = sexpr_at(text, start)
        yield block
        pos = end

def instantiated_symbol_blocks(text: str):
    pos = 0
    while True:
        pos = text.find("  (symbol", pos)
        if pos < 0:
            return
        block, end = sexpr_at(text, pos)
        if '(lib_id "' in block:
            yield block
        pos = end

def main() -> int:
    errors: list[str] = []
    notes: list[str] = []

    if not ROOT.exists():
        print(f"ERROR: missing root schematic: {ROOT}", file=sys.stderr)
        return 2

    root_text = ROOT.read_text(encoding="utf-8")
    child_text: dict[str, str] = {}

    allowed_blank_footprints: set[tuple[str, str]] = set()
    if not MECHANICAL_GATES.exists():
        errors.append(f"missing mechanical gate manifest {MECHANICAL_GATES.name}")
    else:
        try:
            mechanical = json.loads(MECHANICAL_GATES.read_text(encoding="utf-8"))
        except (OSError, json.JSONDecodeError) as exc:
            errors.append(f"{MECHANICAL_GATES.name}: invalid JSON: {exc}")
            mechanical = {}
        gates = mechanical.get("gates", []) if isinstance(mechanical, dict) else []
        for gate in gates:
            if not isinstance(gate, dict):
                errors.append(f"{MECHANICAL_GATES.name}: malformed gate entry {gate!r}")
                continue
            if gate.get("allow_blank_footprint"):
                sheet = gate.get("sheet")
                refdes = gate.get("refdes")
                if not isinstance(sheet, str) or not isinstance(refdes, str):
                    errors.append(
                        f"{MECHANICAL_GATES.name}: blank-footprint gate lacks sheet/refdes: "
                        f"{gate.get('id', '<unknown>')}"
                    )
                else:
                    allowed_blank_footprints.add((sheet, refdes))
        open_blockers = [
            gate.get("id", "<unknown>")
            for gate in gates
            if isinstance(gate, dict)
            and gate.get("blocks_layout_freeze")
            and gate.get("status") != "closed"
        ]
        if mechanical.get("layout_freeze_allowed") and open_blockers:
            errors.append(
                f"{MECHANICAL_GATES.name}: layout_freeze_allowed=true with open blockers: "
                + ", ".join(open_blockers)
            )
        if open_blockers:
            notes.append(
                f"layout freeze remains blocked by {len(open_blockers)} mechanical/sourcing gates"
            )
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

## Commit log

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2026-09-02 fix(docs): use TPS62132 for 3V3 system rail
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2026-09-02 docs: redesign dual USB VBUS with independent power switches
2026-09-02 fix(docs): make dual TPS25221 the Rev A USB power baseline
2026-09-02 fix(docs): align USB power architecture with dual TPS25221
2026-09-02 docs: define GT911 touch reset interrupt and I2C design
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2026-09-02 hardware: initialize KiCad Rev A schematic project
    [01_POWER_INPUT.kicad_sch, 02_POWER_3V3.kicad_sch, 03_P4_CORE.kicad_sch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]
2026-09-02 hardware: capture Rev A input eFuse schematic
    [01_POWER_INPUT.kicad_sch, Pajoniiir-M1.kicad_sch]
2026-09-02 hardware: capture Rev A 3V3 system buck schematic
    [02_POWER_3V3.kicad_sch, Pajoniiir-M1.kicad_sch]
2026-09-02 hardware: capture ESP32-P4X v3 core and DCDC schematic
    [03_P4_CORE.kicad_sch, Pajoniiir-M1.kicad_sch]
2026-09-02 hardware: resize P4 root hierarchy block
    [Pajoniiir-M1.kicad_sch]
2026-09-02 hardware: capture P4 flash clock reset boot schematic
    [04_P4_FLASH_CLOCK_RESET.kicad_sch, Pajoniiir-M1.kicad_sch]
2026-09-02 hardware: capture C6 WiFi ESP-Hosted SDIO schematic
    [05_C6_WIFI.kicad_sch, Pajoniiir-M1.kicad_sch]
2026-09-02 hardware: capture independent dual USB VBUS power
    [06_USB_POWER.kicad_sch]
2026-09-02 hardware: wire dual USB power hierarchy
    [Pajoniiir-M1.kicad_sch]
2026-09-02 hardware: capture USB0 high-speed storage path
    [07_USB0_STORAGE.kicad_sch]
2026-09-02 hardware: wire USB0 storage hierarchy
    [Pajoniiir-M1.kicad_sch]
2026-09-02 hardware: capture USB1 FLX4 full-speed path
    [08_USB1_FLX4.kicad_sch]
2026-09-02 hardware: wire USB1 FLX4 hierarchy
    [Pajoniiir-M1.kicad_sch]
2026-09-02 hardware: capture PCM5102A main audio schematic
    [09_AUDIO_PCM5102A.kicad_sch]
2026-09-02 hardware: wire audio hierarchy and clean root layout
    [Pajoniiir-M1.kicad_sch]
2026-09-02 hardware: capture controlled-power microSD SDMMC schematic
    [12_MICROSD.kicad_sch]
2026-09-02 hardware: wire microSD SDMMC hierarchy
    [Pajoniiir-M1.kicad_sch]
2026-09-02 hardware: capture debug recovery factory service schematic
    [13_DEBUG_SERVICE.kicad_sch]
2026-09-02 hardware: wire debug service hierarchy
    [Pajoniiir-M1.kicad_sch]
2026-09-02 hardware: expose pre-shunt 5V protected rail
    [01_POWER_INPUT.kicad_sch]
2026-09-02 hardware: capture total-system power monitoring schematic
    [14_TEST_MONITORING.kicad_sch]
2026-09-02 hardware: insert system shunt into 5V root power path
    [Pajoniiir-M1.kicad_sch]
2026-09-02 hardware: capture MIPI display and backlight schematic
    [10_DISPLAY_MIPI.kicad_sch]
2026-09-02 hardware: wire MIPI display hierarchy
    [Pajoniiir-M1.kicad_sch]
2026-09-02 hardware: capture GT911 touch interface schematic
    [11_TOUCH_GT911.kicad_sch]
2026-09-02 hardware: wire GT911 touch hierarchy
    [Pajoniiir-M1.kicad_sch]
2026-09-02 hardware: define Rev A assembly option matrix
    [15_DNP_OPTIONS.kicad_sch]
2026-09-02 hardware: assign unique U7 reference to input eFuse
    [01_POWER_INPUT.kicad_sch]
2026-09-02 hardware: sync hierarchy pin shapes and remove stale power label
    [Pajoniiir-M1.kicad_sch]
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2026-09-02 hardware: lock backlight inductor candidate
    [10_DISPLAY_MIPI.kicad_sch]
2026-09-02 hardware: lock Kelvin system shunt candidate
    [14_TEST_MONITORING.kicad_sch]
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2026-09-02 hardware: freeze TI RPW0010A eFuse footprint
    [01_POWER_INPUT.kicad_sch]
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2026-09-02 ci: isolate KiCad schematic load failures
2026-09-02 hardware: normalize cached symbols for KiCad 9
    [03_P4_CORE.kicad_sch, 10_DISPLAY_MIPI.kicad_sch, 12_MICROSD.kicad_sch]
2026-09-02 hardware: fix root hierarchical instance paths
    [Pajoniiir-M1.kicad_sch]
2026-09-02 hardware: normalize root sheet flags for KiCad 9
    [Pajoniiir-M1.kicad_sch]
2026-09-02 hardware: instantiate P4 GPIO unit and bind Rev A nets
    [03_P4_CORE.kicad_sch]
2026-09-02 hardware: separate child schematic file UUIDs
    [01_POWER_INPUT.kicad_sch, 02_POWER_3V3.kicad_sch, 03_P4_CORE.kicad_sch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]
2026-09-02 hardware: normalize root hierarchical pin order
    [Pajoniiir-M1.kicad_sch]
2026-09-02 hardware: normalize root schematic section order
    [Pajoniiir-M1.kicad_sch]
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2026-09-02 hardware: fix local symbol cache keys for ERC
    [03_P4_CORE.kicad_sch, 06_USB_POWER.kicad_sch, 10_DISPLAY_MIPI.kicad_sch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]
2026-09-02 hardware: split root polyline into KiCad wire segments
    [Pajoniiir-M1.kicad_sch]
2026-09-02 hardware: snap child sheets 01-05 to 25 mil grid
    [01_POWER_INPUT.kicad_sch, 02_POWER_3V3.kicad_sch, 03_P4_CORE.kicad_sch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]
2026-09-02 hardware: snap child sheets 06-10 to 25 mil grid
    [06_USB_POWER.kicad_sch, 07_USB0_STORAGE.kicad_sch, 08_USB1_FLX4.kicad_sch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]
2026-09-02 hardware: snap child sheets 11-15 to 25 mil grid
    [11_TOUCH_GT911.kicad_sch, 12_MICROSD.kicad_sch, 13_DEBUG_SERVICE.kicad_sch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]
2026-09-02 hardware: snap root hierarchy to 25 mil grid
    [Pajoniiir-M1.kicad_sch]
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2026-09-02 hardware: place P4 hierarchical rails on decoupling nets
    [03_P4_CORE.kicad_sch]
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2026-09-02 hardware: terminate reset and boot switch nets
    [04_P4_FLASH_CLOCK_RESET.kicad_sch]
2026-09-02 hardware: correct W25Q flash signal and power mapping
    [04_P4_FLASH_CLOCK_RESET.kicad_sch]
2026-09-02 hardware: correct microSD power and signal mapping
    [12_MICROSD.kicad_sch]
2026-09-02 hardware: correct C6 power and interface pin mapping
    [05_C6_WIFI.kicad_sch]
2026-09-02 hardware: correct PCM5102A pin and audio net mapping
    [09_AUDIO_PCM5102A.kicad_sch]
2026-09-02 hardware: correct MP3202 backlight pin mapping
    [10_DISPLAY_MIPI.kicad_sch]
2026-09-02 hardware: correct USB-A connector pin mapping
    [07_USB0_STORAGE.kicad_sch, 08_USB1_FLX4.kicad_sch]
2026-09-02 hardware: correct dual USB power-switch pin mapping
    [06_USB_POWER.kicad_sch]
2026-09-02 hardware: correct P4 unit-2 pin coordinate mapping
    [03_P4_CORE.kicad_sch]
2026-09-02 ci: correct P4 DSI pin coordinate transform
    [validate_schematic_structure.py]
2026-09-02 hardware: correct P4 unit-1 pin coordinate mapping
    [03_P4_CORE.kicad_sch]
2026-09-02 hardware: correct INA238 monitor pin mapping
    [14_TEST_MONITORING.kicad_sch]
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2026-09-02 hardware: normalize endpoint nets and fix microSD input rail
    [09_AUDIO_PCM5102A.kicad_sch, 10_DISPLAY_MIPI.kicad_sch, 11_TOUCH_GT911.kicad_sch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]
2026-09-02 hardware: correct TPS259474 electrical pin types
    [01_POWER_INPUT.kicad_sch]
2026-09-02 hardware: anchor microSD switched rail at load-switch output
    [12_MICROSD.kicad_sch]
2026-09-02 hardware: repair P4 power endpoints and core buck routing
    [03_P4_CORE.kicad_sch]
2026-09-02 hardware: fix 3V3 buck enable and power-good nets
    [02_POWER_3V3.kicad_sch]
2026-09-02 hardware: declare verified rail power sources for ERC
    [01_POWER_INPUT.kicad_sch, 02_POWER_3V3.kicad_sch, 03_P4_CORE.kicad_sch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]
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2026-09-02 hardware: remove stale reset and switched-rail wire stubs
    [04_P4_FLASH_CLOCK_RESET.kicad_sch, 12_MICROSD.kicad_sch]
2026-09-02 hardware: correct P4 supply and USB exposed-pad pin semantics
    [03_P4_CORE.kicad_sch, 06_USB_POWER.kicad_sch]
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2026-09-02 hardware: repair C6 EN hierarchy and trim open net tails
    [05_C6_WIFI.kicad_sch, 07_USB0_STORAGE.kicad_sch, 08_USB1_FLX4.kicad_sch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]
2026-09-02 hardware: normalize gated endpoints and backlight sense wiring
    [10_DISPLAY_MIPI.kicad_sch, 11_TOUCH_GT911.kicad_sch]
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2026-09-02 hardware: pin Rev-A symbols to local library copies
    [02_POWER_3V3.kicad_sch, 04_P4_FLASH_CLOCK_RESET.kicad_sch, 09_AUDIO_PCM5102A.kicad_sch]
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2026-09-03 ci: capture KiCad 9 symbols and repair PGTH junction
    [01_POWER_INPUT.kicad_sch, 02_POWER_3V3.kicad_sch, 04_P4_FLASH_CLOCK_RESET.kicad_sch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]
2026-09-03 hardware: normalize KiCad 9 caches and protected rail endpoint
    [01_POWER_INPUT.kicad_sch, 09_AUDIO_PCM5102A.kicad_sch]
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2026-09-03 hardware: realign crystal ground pins to KiCad 9 symbol
    [04_P4_FLASH_CLOCK_RESET.kicad_sch]
2026-09-03 hardware: stabilize system buck and crystal symbols
    [02_POWER_3V3.kicad_sch, 04_P4_FLASH_CLOCK_RESET.kicad_sch]
2026-09-03 hardware: fix local TPS62132 symbol library format
    [02_POWER_3V3.kicad_sch]
2026-09-03 hardware: record clean ERC and narrow display hard gate
    [10_DISPLAY_MIPI.kicad_sch]
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2026-09-03 ci: fix KiCad BOM command continuation
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2026-09-03 mechanical: correct M1 rear working envelope
    [validate_schematic_structure.py]
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2026-09-03 display: resolve FPC shell and NC pin evidence
    [10_DISPLAY_MIPI.kicad_sch]
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2026-09-03 tools: fix DSI506 migrator active-symbol guards
    [fix_migrate_display_dsi506_b2_guards.py]
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2026-09-04 mech: add fail-closed A13 authority validator
    [validate_mechanical_authority.py]
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2026-09-04 mechanical: lock RESET BOOT switch footprints
    [04_P4_FLASH_CLOCK_RESET.kicad_sch]
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2026-09-07 feat: establish board-first B8 pre-layout
    Populate the live PCB with the complete schematic footprint/net set, preserve fail-closed mechanical gates, and isolate DSI506 as a qualified display profile. Add reproducible placement validation, ERC/BOM evidence, and synchronized project documentation.
    [01_POWER_INPUT.kicad_sch, 02_POWER_3V3.kicad_sch, 07_USB0_STORAGE.kicad_sch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]
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2026-09-08 pcb: fix U8 thermal via drill rule
    [02_POWER_3V3.kicad_sch, Pajoniiir-M1.kicad_pcb]
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
